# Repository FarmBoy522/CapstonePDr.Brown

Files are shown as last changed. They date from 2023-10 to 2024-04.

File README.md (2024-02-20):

# CapstonePDr.Brown
Option 8 - Capstone Project - CS490 ERAU
			      EE421/CS491

Vision Statement

Produce a handheld ultrasound inspection device for inspecting a bridge/structural component for faults in the field. This handheld unit gathers and stores test data collected over time for 48 to 72 hours.

Product Backlog
(current status shown in the issues tab)

Hardware:
	•	Design an outer casing to contain the electronics and test equipment.
	•	Requirements: the case must be able to withstand a fall from 3 ft and protect the contents of the case, the case must be water resistant and be able to protect the contents from water penetration from rain, 				      the case must have a handle and or strap for operator use, the case shall have all required penetrations for equipment to run wires and status lights (if applicable). The case shall be resistant/ 			      shielded from outside radio interference.
	•	Design an electrical system to support the unit’s operation.
	•	Requirements: The power supply shall support equipment normal operating use for greater than or equal to 48 hours (Ideally 72hrs), the electrical system shall be reusable, the electrical system shall have wires 			      secured to the casing or sheathed to prevent damage, the electrical system shall alert the user when power is low. Some portions of the system will operate at 500v and require verification that 			      wire insulation is sufficient for safe operation. 
	•	(TX) Design a smaller equivalent to the signal generator for the transistors operating frequencies.
	•	Requirements: able to produce required frequency for transducer 500kHz, able to produce required frequency for transducer 50kHz, able to switch between the two frequencies, Able to adjust the amplitude of 			              the signal (if required) Transmitter output: pulse 500V, 2microseconds. (Similar system) or Excitation: HV 1000v at 5us, LV 600v at 5us (data sheet)
	•	(RX) Design a smaller equivalent to the oscilloscope for the transistors operating frequencies.
	•	Requirements: able to receive required frequency for transducer 500kHz, able to receive required frequency for transducer 50kHz, able to switch between the two frequencies, Amplifier to boost amplitude of signal. 			      (If required)
	•	Produce attachable extensions to the test equipment leads to extend the test length or assist in accessibility for operator (if required) (not to exceed 20 ft)
	•	Design the memory storage and access hardware
	•	Requirements: minimum storage of “The current data files contain 40000 double-precision numbers and are approx. 1.6 MB” sampling at 10 min interval over 72-hour period, must be computer accessible. 					      (Estimated 691.2MB)
	•	Design an alarm/status system.
	•	Requirement: low battery/power light or alarm, self-check light or alarm, operating/on light or alarm, transmitting/testing light or alarm, memory full light or alarm, high temperature alarm light or alarm.
	•	Design a cooling system for the unit in the case of an overtemperature event. (If applicable)
	•	Requirement: temperature sensor inside the unit (RTD and fan recommended)

Software:
	•	Design/ program/find compatible software to process recorded signal. (MATLAB used previously)
	•	Requirements: must display the captured signal, alert the user if a fault is detected and where (if applicable)
	•	Develop software to monitor battery life and project remaining life 
	•	Develop software to monitor remaining memory space and project how much longer the device can record (use minutes and seconds remaining for recording)
	•	Develop software to pull data overtime from a signal to be used in other programs.
	•	Design software to perform a self-check of the system and determine if the unit has a fault.
	•	Design software to monitor temperature and activate the cooling system. Or shut down if the temperature exceeds 150 F (arbitrary value that may be changed)
	•	Design a GUI (graphical user interface) to quickly check calculated values and for maintenance purposes to display system data.
	
Other:
	•	The unit altogether shall not exceed 25 pounds 
	•	The unit shall be usable by a single operatior in the field.
	•	The unit should be corrosion resistant
	•	The unit should have safety features to shut down the unit if a fault in the system is detected
	•	The unit budget shall not exceed 2000$

Client request:
	•	The unit shall store data to be processed using a computer at a later time.
	•	Recording triggered/start when transmission starts

 2024 update for Backlog

To Do
Develop system to prevent frequent OS errors to allow program to run continuously #55
Design program to monitor charge voltage #54
Create system trigger to shutdown and light "overtemp protection" LED in case of uncontrolled temp overrun #53
Create system trigger to run "charging" fans if temps exceed operational max for parts #52
Wire "charging" fans to main circuit #51
Determine fan mounting positions #50
Install cooling fans #49
Apply sealant to the exterior casing #48
Purchase waterproof sealant #47
Label exterior LED's, switches, and components #46
Create cover plates (if applicable) #45
Create an operators manual (if time available) #44
Purchase 12 to 19.5 v power converter #43
Mount and Install RTD #42
Purchase RTD (resistance temperature detector) #41
Connect capacitor electrically HVS #40
Mount and install relay HVS #39
Purchase Relay for HVS #38
Test fan controllers via Arduino [Sprint 1 2024] #23
Design software to perform a self-check of the system and determine if the unit has a fault. #14
Develop software to store oscilloscope data on computer #13
Develop software to monitor remaining memory space and project how much longer the device can record (use minutes and seconds remaining for recording) #12
Develop software to monitor battery life and project remaining life #11
Test new data recording system with old Matlab program #10
Design the memory storage and access hardware #7

In Progress
Produce drip cover for exterior casing #56
Install electrical system HVS part 8 (resistors) #37
Install electrical system HVS part 7 (coaxial connection port) #36
Install electrical system LVS part 6 (battery) #35
Install electrical system HVS part 6 (12v to 500v power converter) #34
Install electrical system HVS part 5 (Fuses) #33
Install electrical system HVS part 4 (exterior operated switches) #32
Install electrical system HVS part 3 (Capacitor) #31
Install electrical system HVS part 2 (wiring) #30
Install electrical system HVS part 1 (circuit boards) #29
Install electrical system LVS part 5 (Fuses) #28
Install electrical system LVS part 4 (exterior operated switches) #27
Install electrical system LVS part 3 (LED) #26
Install electrical system LVS part 2 (wiring) #25
Install electrical system LVS part 1 (circuit boards) #24
Test electrical systems #21
code for led indicating lights/alarms #18
verify design criteria met #17

Finished
Program LUT for fan controllers [Sprint 1 2024] #22
Verify components electrically #20
connect/solder electrical system components #19
Design a GUI (graphical user interface) to quickly check calculated values and for maintenance purposes to display system data. #16
Design software to monitor temperature and activate the cooling system. Or shut down if the temperature exceeds 150 F (arbitrary value that may be changed) #15
Design a cooling system for the unit in the case of an overtemperature event. (If applicable) #9
Design an alarm/status system. #8
Produce attachable extensions to the test equipment leads to extend the test length or assist in accessibility for operator (if required) #6
(RX) Design a smaller equivalent to the oscilloscope for the transistors operating frequencies. #5
(TX) Design a smaller equivalent to the signal generator for the transistors operating frequencies. #4
Perform research to determine if the equipment can be miniaturized from the lab environment. #3
Design an electrical system to support the unit’s operation. #2
Design an outer casing to contain the electronics and test equipment. #1

	•	50 pulses sent each transmission (100 µsec interval in example)
	•	The revived 50 pulses are averaged together and displayed.
	•	The unit battery shall last for 48-72 hours or greater with samples being taken every 10 min.
	•	Budget less than or equal to 2000$
	•	MATLAB used to process data into usable form and graphed for analysis.

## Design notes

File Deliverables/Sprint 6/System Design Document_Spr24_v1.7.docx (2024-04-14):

System Design Document

Dr. Brown Capstone Project Spring ‘24:

Portable Ultrasound Device for Coda-Wave Interferometry

Team members:

Michael Kisellus, Matthew Baker, Layton Foxworthy, Kyle Fox, and Christopher Coppedge

Version | Author | Change | Date
v1.0 | Michael Kisellus, Matthew Baker, Layton Foxworthy, Kyle Fox, and Christopher Coppedge | Initial draft | 1/23/2024
v1.1 | Michael Kisellus | Times new roman text, figure 6,7 update, print format to make more readable, update references, update table of context, table 2 update | 4Feb2024
V1.2 | Kyle Fox | Updated readability | 5Feb2024
V1.3 | Michael Kisellus | Corrections from SDD feedback | 15,20Feb2024
V1.4 | Michael Kisellus | Same as above | 29Feb2024
V1.5 | Kyle Fox | Update Software architecture sections | 01Mar2024
V1.6 | Matthew Baker | Update cooling system detailed design, corrections from feedback on External Interfaces | 21Mar2024
V1.7 | Matthew Baker | Corrections from TA feedback: eliminating stray highlighting, proofreading | 11Apr2024

# TABLE OF CONTENT

1 INTRODUCTION 4

1.1 Purpose and Scope 4

1.2 Project Executive Summary 4

1.2.1 System Overview 4

1.2.2 Design Constraints 6

1.2.3 Future Contingencies 6

1.3 Document Organization 7

1.4 Project References 8

1.5 Glossary 8

2 SYSTEM ARCHITECTURE 9

2.1 System Hardware Architecture 10

2.1.1 Cooling System 10

2.1.2 Electrical System 11

2.2 System Software Architecture 12

2.3 Internal Communications Architecture 12

3 HUMAN-MACHINE INTERFACE 13

3.1 Inputs 13

3.2 Outputs 14

4 DETAILED DESIGN 15

4.1 Hardware Detailed Design 15

4.1.1 Environment Control and Cooling System 15

4.1.2 Electrical and Power System 16

4.1.3 Microcontroller and Control 17

4.1.4 Output Signal 17

4.1.5 Input Signal 17

4.2 Software Detailed Design 17

4.3 Internal Communications Detailed Design 18

5 EXTERNAL INTERFACES 19

5.1 Interface Architecture 19

5.2 Interface Detailed Design 20

6 SYSTEM INTEGRITY CONTROLS 20

7 References 23

SYSTEM DESIGN DOCUMENT

Overview

The System Design Document describes the system requirements, operating environment, system and subsystem architecture, files and database design, input formats, output layouts, human-machine interfaces, detailed design, processing logic, and external interfaces.

# 1 INTRODUCTION

Bridges are vital transportation infrastructure that are used daily by millions of people. Like any constructed work, the material used has a finite lifespan and will degrade as both the effects of nature and its designed purpose act on the bridge. Being able to determine locations of failure points, subsurface cracks, and voids in building materials such as concrete can greatly increase the ability for an engineering team to predict future issues and plan remedial work for a bridge. To assist those engineers, the Portable Ultrasound Device (PUD) was designed. This device can be used in conjunction with ultrasonic transducers to detect anomalies within concrete. The data collected can be used to make future engineering decisions.

## 1.1 Purpose and Scope

The PUD is a handheld ultrasound inspection device for inspecting bridges and structural components for faults in the field. This handheld unit will have an independent power supply and will collect and store test data. The PUD is fully capable of its precise data collection duties while still being durable enough to withstand difficult environmental conditions such as shock from a fall, rain, and other environments a field tool will be exposed to.

## 1.2 Project Executive Summary

This PUD unit consists of commercial off-the-shelf (COTS) components engineered into a cohesive system that matches the requirements. The production management for the PUD project is Agile Scrum. Dividing the PUD project into 3 sprints over the course of an 11-week timeline.

### 1.2.1 System Overview

The PUD system will output a pulse signal to the transducer as shown in figure 2 point 1. The transducer then uses the piezoelectric effect to produce a 54kHz test signal, this signal propagates into the connected concrete sample being tested. The signal then propagates to a second transducer placed on the opposing side of the concrete sample. Through the piezoelectric effect the second transducer converts the 54kHz signal into a low-level voltage which is returned to the PUD to be processed.

Note: The 54 kHz is due to the manufacturer of the transducer NDT James Instruments. It is designed to produce this frequency

The use case diagram shown in figure 1 describes the options an operator can use to operate the PUD system. The operator may charge the battery or remove the storage device (SD) card when the power is off to the main system. The main functionality is accessible when the operator turns the unit's power on. Allowing the operator to enter the test duration by repeatedly pressing the test duration button to cycle through the options. The test duration selected is displayed on the face plate LEDs 6,7,8,9, and 10 shown in figure 6. The operator may press the start button to initiate the test. The operator may also stop the test before the test duration ends and save the resulting data to an SD card.

Figure 1: Use Case Diagram

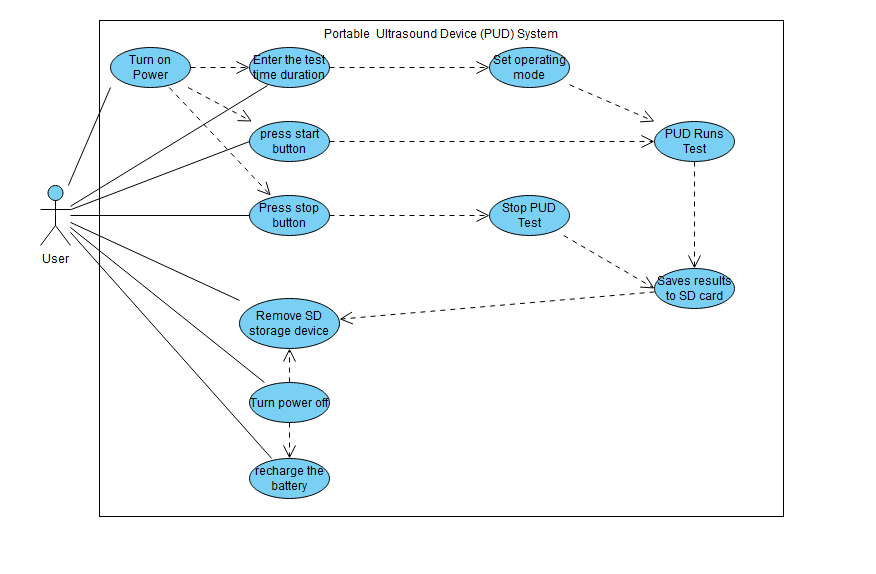
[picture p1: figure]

Figure 2: overall system diagram

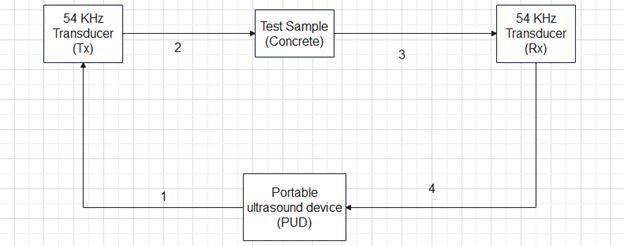
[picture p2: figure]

### 1.2.2 Design Constraints

The design of the system will balance system weight vs battery life, battery consumption vs cooling, and accuracy vs component price. One of the requirements of the system is that it must remain portable and as such we will be keeping the unit as light as possible. This comes in direct competition with battery life, which also has its own requirement. Battery consumption and cooling are also going to have to be balanced to ensure the hardware, specifically the battery, stays within operating temperature. This would lead us to running the fans more but that increases battery consumption and decreases how long the system can be used in the field. Lastly, more accurate signal processing hardware costs more than its less accurate counterpart so our design uses components that are within the project’s budget of $2000 and are also accurate enough for our application.

### 1.2.3 Future Contingencies

The exact requirements of the system are dependent on the civil engineering laboratory (Lab run by Professor Brown), which serves as the primary stakeholder for the system. They will be the primary user of the PUD once it is operational so the requirements must match their expectations. Any changes to the system will depend on their wants and needs. The civil engineering lab already has some components of the final system, these are not going to change and are proven to operate correctly from previous testing.

Operating with 500V requires specialized components and rated insulative material to protect the system from inadvertent grounds or component failure. If components fail during testing a higher voltage rated component may be purchased to replace insufficient performing parts.

The Metal oxide semiconductor field effect transistor (MOSFET) component used must switch on and off quickly to fulfill its purpose. If the component is unable to meet specifications during testing a better/ more expensive component may need to be purchased to replace this component.

The oscilloscope used to sample the return signal needs to be sampled extremely quickly to capture the return signal in detail. This component may need to be replaced if testing reveals the sample rate to be insufficient.

## 1.3 Document Organization

The document adheres to the organizational structure and formatting prescribed by the course. Every section, heading, and subheading has been aligned with the template guidelines to maintain a consistent and professional appearance. By following the provided instructions and formatting guidelines, we aimed not only to meet the basic requirements but also to contribute to the overall uniformity of documentation between the multiple teams. This approach ensures that the professors and TAs can easily navigate the document.

Part 1 contains the INTRODUCTION which has 8 subsections: Purpose and Scope, Project Executive Summary, System Overview, Design Constraints, Future Contingencies, Document Organization, Project References, and the Glossary. Overall, this section describes the system, constraints, contingencies and the documentation associated with the system.

Part 2 contains the SYSTEM ARCHITECTURE which has 3 subsections: System Hardware Architecture, System Software Architecture, Internal Communications Architecture. Overall, this section describes the system hardware and software architecture for the PUD system. The hardware section is subdivided by systems.

Part 3 contains the HUMAN-MACHINE INTERFACE which has 2 subsections: Inputs and Outputs. Overall, this section describes the inputs a user can make and the outputs the PUD system will produce.

Part 4 contains the DETAILED DESIGN which has 3 subsections: Hardware Detailed Design, Software Detailed Design, Internal Communications Detailed Design. Overall, this section provides an in-depth explanation of the systems used to construct the PUD system.

Part 5 contains the EXTERNAL INTERFACES which has 2 subsections: Interface Architecture and Interface Detailed Design. Overall, this section describes other systems the PUD system must interface with to operate. This section is small because the system is self-contained and does not communicate to exterior systems during operation.

Part 6 contains the SYSTEM INTEGRITY CONTROLS. Overall, this system has to do with data security and software protection. This section is small due to the unit not requiring data protection as the PUD does not contain sensitive information.

## 1.4 Project References

This section provides a bibliography of key project references and deliverables that have been produced before this point.

International Electrotechnical Commission (2013). Degrees of protection provided by enclosures (IP Code) (IEC 60529). Retrieved from https://website.iec.ch/publication/2452

Parts references are placed at the end of the document in table 3.

## 1.5 Glossary

Supply a glossary of all terms and abbreviations used in this document. If the glossary is several pages in length, it may be included as an appendix. Shown in table 1.

Table 1: glossary

IP Rating [IPAB]

Ingress Protection rating as codified under the IEC 60529 standard, where A is the device’s resistance to solid particle such as dust from zero (no protection) to 6 (most protection) and B is the device’s resistance to liquids from zero (no protection) to 9K (most protection). (International Electrotechnical Commission [IEC], 2013)

An IP55 rating means:

5-Ingress of dust is not entirely prevented, but it must not enter in sufficient quantity to interfere with the satisfactory operation of the equipment.

5-Water projected by a nozzle (6.3 mm) against enclosure from any direction shall have no harmful effects.
PUD | Portable ultrasound device
LED | Light emitting diode
piezoelectric effect | Applying mechanical stress to a crystal produces an electrical charge and vice versa.
MOSFET | Metal oxide semiconductor field effect transistor
UART | Universal asynchronous receiver transmitter
HMI | Human machine interface
PC | Personal computer
Tx | Transmitter
Rx | Reciever
SD | Storage device
FRD | Functional requirement document
RTM | Requirement traceability matrix

# 2 SYSTEM ARCHITECTURE

This section outlines the overall system architecture, including both software and hardware architecture for the PUD system and subsystems.

Figure 3 shows the PUD physical components and their interactions. Point 1 shows that the cooling fan receives power to operate from the battery. Point 2 shows that the analog to digital converter delivers its data to the central control chip. Point 3 shows that the pulse generator is controlled by the central control chip. Point 4 shows that the pulse generator controls the MOSFET gating on or off. Point 5 shows that The MOSFET outputs to the Transducer. Point 6 shows that the central control chip transfers data to the SD card. Point 7 shows that the central control chip monitors the battery voltage. Point 8 shows that the cooling fan is controlled by the central control chip. Point 9 shows that the status LEDs are controlled by the central control chip. Point 10 shows that the central control chip receives power from the battery. Point 11 shows that the status LEDs are powered by the battery. Point 12 shows that the transducer transmits a signal to the analog to digital converter. Point 13 shows that the MOSFET input is provided by the DC-to-DC converter. Point 14 shows that the DC-to-DC converter is powered by the battery.

Figure 3: Portable ultrasound device (PUD) internal components block diagram

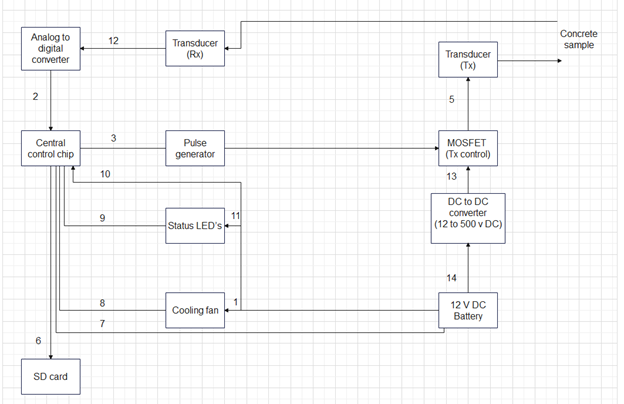
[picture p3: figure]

## 2.1 System Hardware Architecture

This section, describes the overall system hardware and organization. The system hardware is broken into 2 subsystems: Cooling System, Electrical System.

### 2.1.1 Cooling System

The cooling system consists of multiple 80mm fans each connected to an integrated fan controller and temperature sensor to operate independently from one another to ensure that if one fan goes down the other(s) can still operate as well as making sure each area within the case gets the airflow that it requires. The fans will be placed on either end of an inner metal frame to drive the airflow over the components in the most efficient manner possible. The fan’s RPM rate will be tied to the internal temperature of local components (detected via the controller) via the following curve shown in figure 4. This curve is designed by the manufacturer of the fan components.

Figure 4: Cooling fan behavior chart

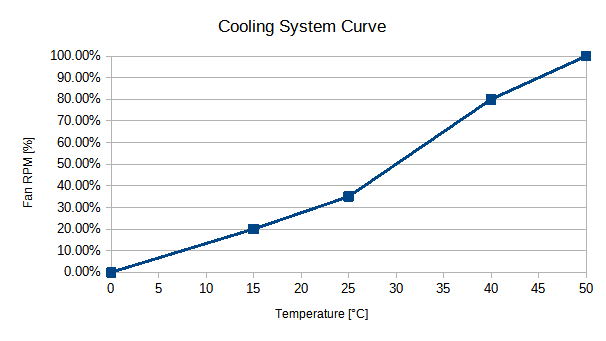
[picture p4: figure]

While the system’s design considers the possibility for the fans to run at maximum for the entire operating time, this thermal curve is in keeping with industry standards for keeping a computer system cooled while preventing too much current and power use from the internal power supply and thus preventing premature power drain.

Parts List:

- Twin NMB 08025SE-12Q-FT-DW Fan, 12VDC, 3.12 Watts at 0.26 Amps for variable cooling
- EMC2101 integrated fan controller and thermocouple, 3/5V DC connected to central board.

### 2.1.2 Electrical System

The PUD electrical system consists of a 12v battery bank which is used to power various loads. Such as LED’s and cooling fans. There is a subsystem for charging the battery which is disconnected through an externally operable switch. The high voltage section consists of a 12v DC to 500v DC converter and a capacitor bank to maintain voltage. Electrical schematic shown in figure 3 below.

Parts list for electrical systems are shown in table 2 but parts may be replaced with equivalent parts.

Figure 5: PUD Electrical system

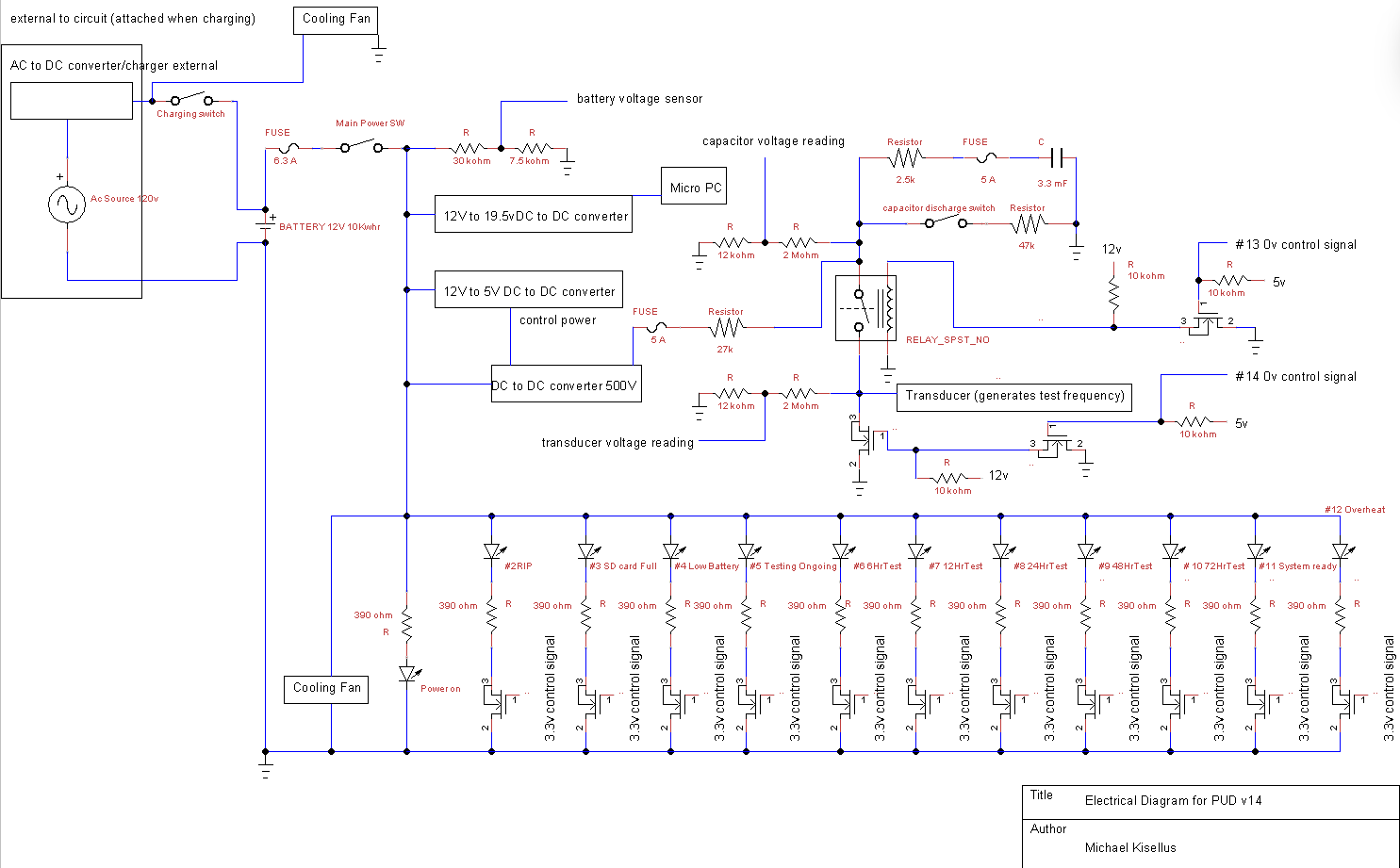
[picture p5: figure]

## 2.2 System Software Architecture

The software system is made up of two parts, the Raspberry Pi Pico, and the minicomputer. Both parts work independently to control the system and record data.

The Raspberry Pi Pico (RP Pico) handles system control through a state machine with three separate states. Each state controls a different part of the hardware system. The first state allows for button interrupts to control movement to the next state. The second state allows for pulse control and overall system timing. The third state changes the total test time of the system.

The microcomputer will run a Python-C wrapper to program the oscilloscope to do automated data collections. This collection will be done without human intervention and store the data on an SD card within the computer for later retrieval.

## 2.3 Internal Communications Architecture

The internal communications will consist of USB, Digital IO, and UART. The Universal asynchronous receiver transmitter (UART) will allow us to program the microcontroller. USB will be used to control and program the Oscilloscope as well as preform data collection/storage. The microcontroller will use the digital IO pins to control the Human machine interface (HMI) and pulse control. Shown in figure 8.

There will be no communication between the microcontroller and the minicomputer as the buttons will control microcontroller function and the oscilloscope will have automatic data collection. The microcontroller will however send a pulse to the oscilloscope at the same time as the control pulse is sent to the transducer.

Figure 8: Internal Communications Architecture diagram

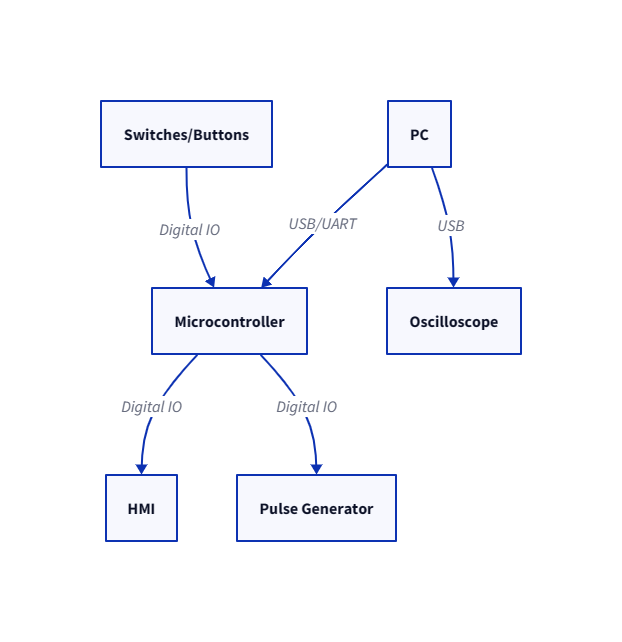
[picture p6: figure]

# 3 HUMAN-MACHINE INTERFACE

The PUD system will have input from the user to start the system and to determine how long the system should operate. This will be performed through physical buttons. As for outputs the PUD will have LED indicators to display the system’s status to the operator. Additionally, a removable SD card will be able to be extracted from the system after it has gathered the desired data.

## 3.1 Inputs

The PUD system inputs will be physical buttons that send a voltage signal to the microcontroller. Because it is a simple 2-state button the PUD will have the input to the microcontroller be a simple binary input. The buttons will correspond to modes that set the time the system will be in operation. This simplicity will make I/O controls simple and reliable.

The front panel physical button I/O options will be “Test System”, “6 Hour”, “12 Hour”, “24 Hour”, “48 Hour”, “72 Hour”, “Start Test” “Select Test Duration” and “Stop Test”. As shown in figure 6.

Figure 6: Input panel for PUD

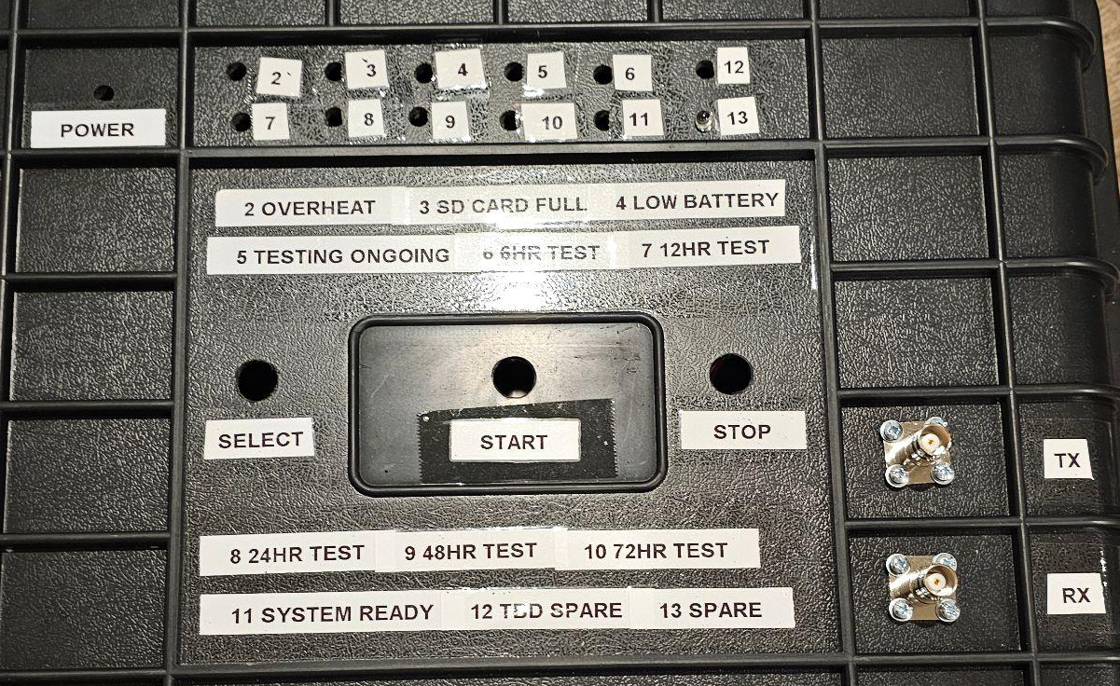
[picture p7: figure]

## 3.2 Outputs

The outputs from the system come in two different forms. The data from the operation of the system, and the indicators that tell the operator the status of the system. The operator indicators will be presented on LEDs and the system’s output data from the concrete measurement will be stored on an SD card.

The operator’s indicators will be the representation of binary values in our microcontroller. The implementation of this will depend on the voltage the microcontroller is able to output so if it is not able to power the LED we may need a relay to switch the LED on. The indicators will include “Power Available”, “Low Battery”, “High Temperature”, “SD Card Full”, “Unit Charging Capacitor” and more if needed.

The data the system collects about the concrete will need to be converted to a digital signal and stored through the oscilloscope. This will then be written to an SD card in the minicomputer for the operator to retrieve when the system is done with its operation. The retrieval will require the case to be opened. This helps protect the SD card against the weather. The output file on the SD card will be set within the minicomputer program as a “.mat” file.

Note: Expanding on the source of the data the system collects: After the system transmits a 500 v pulse to the Transmitting (Tx) transducer. The transducer vibrates and those vibrations travel through the concrete/sample. The vibrations then reach the receiving (Rx) transducer and the vibrations are converted to a electrical voltage. This voltage is read by the connected oscilloscope and processed into a graph of the resulting voltages over time. This graph is then saved for review by human operators on a removable SD card or other storage device.

Figure 7: Output panel for PUD

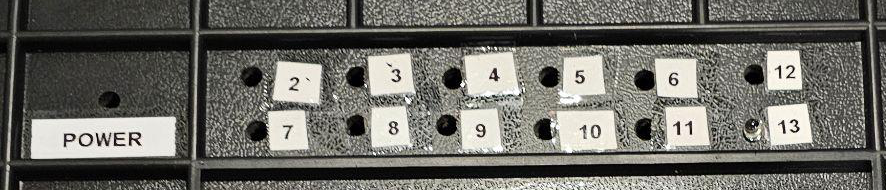
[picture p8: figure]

# 4 DETAILED DESIGN

This section provides the information needed for a system development team to build and integrate the hardware components, code, and integrate the software modules, and interconnect the hardware and software segments into a functional product. Additionally, this section addresses the detailed procedures for combining separate COTS packages into a single system. Every detailed requirement should map back to the Functional requirement document

(FRD), and the mapping should be presented in an update to the Requirement traceability matrix (RTM) and include the RTM as an appendix to this design document.

## 4.1 Hardware Detailed Design

The low-level hardware design is split into 5 distinct parts. The microcontroller and control system, the output signal, the input signal, the environment control, and the power system.

### 4.1.1 Environment Control and Cooling System

The cooling system consists of two 80mm 12VDC fans each connected to a EMC2101 fan controller which circulates air via a pull-push arrangement with one fan acting as intake and the other acting as exhaust. The fans are placed on opposing sides of the case and staggered with one at the rear-right and the other at the front-left side to properly vent air around the battery and capacitor. The fan controllers are integrated circuit boards that contain a programmable ROM that contains a look-up table which instructs the fan on the proper RPM to spin at via pulse-width modulation which is dependent on the temperature inside the case. The external cutouts for the fans have fan covers that consist of an external vent to protect from rainfall; filter media to prevent the ingress of dust, insects, and other solid matter; and a plastic grate to act as a finger guard in the event that the external cover is dislodged. Internally the fans are protected via plastic mesh held to prevent damage to the internal wiring. Each fan as an IP55 rating to aid in the overall elemental resistance of the unit. The fan cover baseplates are attached via long screws and waterproof sealant. Each fan draws 3.12 watts and 0.26 amps and each controller board requires 5VDC supply voltage provided by available power within the electrical system. The fan controller boards also provide the temperature readings to the Pico at the heart of the system so that, in case of temperature overrun, the system can be shut down to prevent damage to the components.

### 4.1.2 Electrical and Power System

The electrical system consists of 2 main buses. Note: electrical bus bars are used to distribute power. A 12 V DC bus and a 500 V DC bus are used.

The 12 V DC bus consists of 2 loops. The first loop is used to recharge the LiFePO4 12V 50Ah Lithium Iron Phosphate Battery. The battery is connected using 6 AWG (16mm²) 13 Inch Battery Interconnect Cable to the exterior of the casing and is accessible without opening the case. A Battery Isolator Switch for Car Vehicle RV and Marine (On/Off) is used to isolate the battery charging loop when not in use. The battery charger used is a 5A & 10A 12V Smart Battery Charger with LCD Display for Lead Acid and Lithium (LiFePO4) Batteries. The second loop connects the battery to the 12 V DC load bus which powers the various loads of the system. The battery has a switch to open this loop and turn off the system. The battery connects to the 10 Position Wire to Board Terminal Block Horizontal with Board. This is used to connect the various 12 v loads. Including the LED indicating lights which require a 453 Ohms ±1% 0.25W, 1/4W Through Hole Resistor Axial Metal Film to reduce voltage and current to 3.3v and 20mA for the LED to operate. The LED uses a Transistor’s: Bipolar (BJT) Transistor NPN 36 V Through Hole TO-92-3 to receive signals from the controlling chip to turn on or off. The cooling fan receives power from this bus. The controlling chip receives its power from this bus. The DC 12v 24v to 5v Step Down Converter Regulator 5A 25W Power Adapter Reducer for Car Electronics Truck Vehicle Boat Solar System (Accept DC 8-40V Inputs) receives power from this bus and its output is used as control power on the Enclosed DC to DC Converter 1 Output 0 ~ 500V 20mA 13V Input. The 12V DC to 500V DC converter receives its main power from this bus and sends power to the 500V bus.

The 500V DC bus starts at the 12V DC to 500V DC converter and is used to charge a 3300 µF 500 V Aluminum Electrolytic Capacitor which acts as a voltage regulator for normal operation. Amcor Marine Grade Primary Wire and Battery Cable is used for the 500 v portions of the circuit to connect the circuit components. A 47 kOhms ±5% 50W Wire wound Chassis Mount Resistor is used in series with the capacitor to prevent current from exceeding the 20mA limit of the converter while charging the capacitor. Finally, a MOSFET N-Channel 500 V 14A (Tc) 30W (Tc) Through Hole TO-220FP is used to gate the 500 V DC source on for 2*10^-6 sec. This pulse then travels to the transducer and leaves the PUD system. Figure 3 above displays the electrical schematic.

### 4.1.3 Microcontroller and Control

This part of the PUD can be affectionately considered the brains of the PUD. The microcontroller and control system handles both user inputs, timing of data collection from the input signal, control of the output signal, and allows for user retrieval of data from the SD card.

This system uses the bus architecture described earlier to communicate with both the SD card and the ADC. This allows data to move through the microcontroller to the SD card with minimal latency for further data collection.

### 4.1.4 Output Signal

This is the 500V DC signal that pings the transducer. The system uses a DC-DC converter to charge 500V and release a 2-microsecond pulse to the transducer allowing the semiconductive nature of the crystal to ring. This is activated by the microcontroller and is timed to allow the input signal to be unaffected by the “strike” of the output transducer.

### 4.1.5 Input Signal

The input signal is a 1V peak signal that is fed into a high-speed high bandwidth ADC. This ADC converts the analog signal into a digital stream that is fed into the microcontroller. This signal is the representation of the concrete health, this signal must be captured in its entirety and for its whole duration. This is done by using the ADC filtering functions to remove noise and capture the whole waveform for data processing. Once the ADC has captured a portion of the signal, the microcontroller moves the data over SPI to the SD card for processing by the data analysis program, which is off system.

## 4.2 Software Detailed Design

Software design of the microcontroller consists of a state machine of 3 states. This is done to reduce the chance of functions or control running in error. This design also allows for a major simplification of the overall system by allowing for the minicomputer to not communicate directly with the microcontroller.

This simplification of design parameters allows for each state to control the program with a minor number of function calls that operate linearly. The first state allows for input from buttons to step into the next state. This “waiting” state allows for the user to press the start button to go to state 2 and begin the test, stop button to do nothing, and select button to go to state 3 and change the total test time. The second “running” state will control the pulse control, system timing, and overall control. The third “select” state changes the current total test time value.

## 4.3 Internal Communications Detailed Design

USB Communication will be the method in which the PC will communicate with the oscilloscope. The oscilloscope will be preprogrammed with a function that will allow for automated data collection. This software is sourced from the manufacturer. This automated data collection will allow for the program to store data on the computer without human intervention.

Shown in figure 9.

Figure 9: Rx system

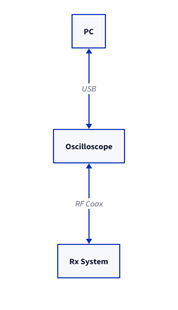
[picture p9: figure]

The microcontroller will use its Digital IO pins to turn LEDs on and off, for digital interrupts from the HMI, and send a pulse to the TX and oscilloscope portion of the system. The LEDs will be controlled by the outputs of the microcontroller. The pulse will be timed to be as short as possible, however to ensure accuracy that will feed into a timer circuit to keep the time consistent. Shown in figure 10.

Figure 10: Button interface to system

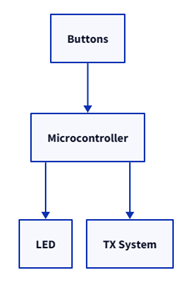
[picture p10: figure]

# 5 EXTERNAL INTERFACES

With the system being self-contained there are no external interfaces under the scope of this PUD project, the only exception being the SD card containing the testing data. However, as this card is extracted from the PUD system manually by the operator this would only fit the definition of an external interface via the broadest possible interpretation of the term.

# 6 SYSTEM INTEGRITY CONTROLS

The data collected by the PUD system is not inherently sensitive or private so security is not the highest priority. There will be a physical lock on the PUD outer casing for safety purposes but this will also protect the data the system collects. Physical protection of the device is the responsibility of the user of the system. Verification of the data will come from the lab that analyzes the data so this is not within the scope of the PUD project.

Table 2: electrical components parts list

part number | Part specification and description
1 | 3300 µF 500 V Aluminum Electrolytic Capacitors Radial, Can - Screw Terminals 54mOhm @ 100Hz 20000 Hrs @ 85°C
2 | Enclosed DC DC Converter 1 Output 0 ~ 500V 20mA 13V Input 3838-HighVoltagePowerSupplyAHV12V500V20MAWTB-ND - Tape & Box (TB)
3 | DC 12v 24v to 5v Step Down Converter Regulator 5A 25W Power Adapter Reducer for Car Electronics Truck Vehicle Boat Solar System (Accept DC 8-40V Inputs)
4 | White, Cool 9000K LED Indication - Discrete 3.2V Radial
5 | 5A & 10A 12V Smart Battery Charger with LCD Display for Lead Acid and Lithium (LiFePO4) Batteries
6 | 6AWG (16mm²) 13 Inch Battery Interconnect Cable
7 | LiFePO4 12V 50Ah Lithium Iron Phosphate Battery
8 | Battery Isolator Switch for Car Vehicle RV and Marine (On/Off)
9 | Ancor Marine Grade Primary Wire and Battery Cable
10 | N-Channel 500 V 14A (Tc) 30W (Tc) Through Hole TO-220FP
11 | Starelo 5pcs 19mm Momentary Push Button Switch Black Shell, IP65 Waterproof Push Button Switch,Stainless Steel 1 Normally Open Without LED.
12 | 47 kOhms ±5% 50W Wirewound Chassis Mount Resistor
13 | N-Channel 20 V 6.8A (Ta) 510mW (Ta), 6.94W (Tc) Surface Mount TO-236AB
14 | 390 Ohms ±5% 0.5W, 1/2W Through Hole Resistor Axial Flame Retardant Coating, Safety Carbon Film
15 | 21 Circuit 0.374" (9.50mm) Barrier Block Connector Screws
16 | 5 A 600 V AC 500 V DC Fuse Cartridge, Ceramic Requires Holder 5mm x 20mm
17 | Fuse Block 10 A 600V 1 Circuit Cartridge Chassis Mount
18 | 6.3 A 250 V AC DC Fuse Cartridge, Glass Requires Holder 5mm x 20mm
19 | ANSI Z535 Safety Labels - Hazardous Voltage Inside Hazard labels with strong adhesive backing ideal for rugged use
20 | 50ft - 1/4 inch & 1/2 inch PET Expandable Braided Sleeving – Black – Alex Tech Braided Cable Sleeve
21 | XHF 3/4" Strong Back-Glue Self Adhesive Black Cable Zip Tie Mounts 100pcs with 8" Zip Ties, Screws, UV Protection Outdoor Sticky Wire Fasteners Cable Clips Management Anchors Organizer Holders Squares
22 | Miuzei PCB Board Prototype Kit for Electronic Projects, Circuit Solder Double-Side Board with 40 Pin 2.54 mm Male to Female Headers Connector, 2P&3P Screw Terminal Block, Solder Flux, Solder Wire
23 | 330 Pcs M2 Male Female Brass Hex Spacer Standoffs Screws Nuts, Brass Spacer Hex Column Screw Nut Assortment Kit, Threaded Pillar Standoffs Screws for PCB Circuit Board Motherboard Standoffs Spacer
24 | Breadboard, Surface Mount Plated Surface Mount Pad (Square) 0.100" (2.54mm)
25 | 2.7 kOhms ±5% 120W Wirewound Chassis Mount Resistor
26 | Heat Sink TO-218, TO-220, TO-247 Aluminum 14.0W @ 70°C Board Level, Vertical or Heat Sink TO-220 Aluminum 2.5W @ 50°C Board Level
27 | Belker Universal Laptop Car Charger with USB C for HP Dell Asus Lenovo Samsung MacBook Pro Air Google Chromebook Ultrabook Notebook
28 | VELCRO Brand Extreme Outdoor Mounting Tape | 20Ft x 1 In, Holds 15 lbs | Strong Heavy Duty Stick on Adhesive | Mount on Brick, Concrete for Hanging, 30702
29 | Coolais 5 Pcs Momentary Push Button Switch Metal Waterproof Push Button Start 12mm 3A 250V AC PBSM-01 (Flat Head)
30 | 3M Marine Adhesive Sealant Fast Cure 5200 (05220) Permanent Bonding and Sealing for Boats and RVs Above and Below the Waterline Waterproof Repair, White, 3 fl oz Tube
31 | Temperature Sensor Analog, Local 5°C ~ 100°C 20mV/°C TO-92-3
32 | ASEV30 SERIES 30A DC CONTACTOR Search Alert TSA Approved Travel Combination Luggage Cable Locks for Suitcase, Gym Locker,Toolbox,Backpack 1,2,4,6 &10 pk
33 | E/FUSING 900 Moldable Silicone Putty - Black
34 | 2Pcs Electronic Thermostat Controller W1209 DC 12V Digital Thermostat Waterproof Sensor Temperature Control Switch -50~110°C
35 | TBD

# 7 References

“021706.3TXP Littelfuse Inc. | Circuit Protection | DigiKey.” DigiKey, www.digikey.com/en/products/detail/littelfuse-inc/021706-3TXP/3425317. Accessed 21 Oct. 2023.

“05200005ZXGY Littelfuse Inc. | Circuit Protection | DigiKey.” DigiKey, www.digikey.com/en/products/detail/littelfuse-inc/05200005ZXGY/554334. Accessed 21 Oct. 2023.

“0ADKC5000-Be Bel Fuse Inc. | Circuit Protection | Digikey.” DigiKey, www.digikey.com/en/products/detail/bel-fuse-inc/0ADKC5000-BE/7404459. Accessed 21 Oct. 2023.

“100ft - 1/2 Inch Pet Expandable Braided Sleeving - Amazon.Com.” Amazon, www.amazon.com/100ft-Expandable-Braided-Sleeving-braided/dp/B074GMNW7T. Accessed 21 Oct. 2023.

“12-48V Battery Isolator Switch for Car Vehicle RV and Marine (on/off): Eco-Worthy.” ECO, www.eco-worthy.com/products/12-48v-battery-isolator-switch-for-car-vehicle-rv-and-marine-on-off?variant=40589578567868. Accessed 21 Oct. 2023.

“2-1546306-1 TE Connectivity AMP Connectors - DigiKey Electronics.” DigiKey, www.digikey.com/en/products/detail/te-connectivity-amp-connectors/2-1546306-1/1136667. Accessed 21 Oct. 2023.

“330 PCS M2 Male Female Brass Hex Spacer Standoffs Screws ... - Amazon.Com.” Amazon, www.amazon.com/Standoffs-Assortment-Threaded-Circuit-Motherboard/dp/B0BZYTC581. Accessed 21 Oct. 2023.

“577002B00000G Aavid, Thermal Division of Boyd Corporation - Digikey.” DigiKey, www.digikey.com/en/products/detail/aavid-thermal-division-of-boyd-corporation/577002B00000G/102507. Accessed 21 Oct. 2023.

“5A 12V Automatic Smart Battery Charger and Maintainer with LCD Display for Lead Acid and Lithium (LiFePO4) Batteries: Eco-Worthy.” ECO, www.eco-worthy.com/products/5a-12v-automatic-smart-battery-charger-and-maintainer-with-lcd-display-for-lead-acid-and-lithium-lifepo4-batteries?variant=42350017052921. Accessed 21 Oct. 2023.

“6AWG (16mm2) 13 Inch Battery Interconnect Cable: Eco-Worthy.” ECO, www.eco-worthy.com/products/6awg-16mm-13-inch-battery-interconnect-cable?variant=34593133625509. Accessed 21 Oct. 2023.

“Als30a332np500 Kemet | Capacitors | Digikey - Digi-Key Electronics.” Digikey, www.digikey.com/en/products/detail/kemet/ALS30A332NP500/3462159. Accessed 21 Oct. 2023.

“Amazon.Com: 2Pcs Electronic Thermostat Controller W1209 DC 12V Digital ...” Amazon, www.amazon.com/Electronic-Thermostat-Controller-Waterproof-Temperature/dp/B08Y6L34PX. Accessed 4 Feb. 2024.

“Amazon.Com: Tsa Approved Luggage Locks, Travel Locks Which Also Work ...” Amazon, www.amazon.com/Approved-Luggage-Travel-Toolbox-Backpack/dp/B07MVJZ6C2. Accessed 4 Feb. 2024.

“Amazon.Com: XHF 3/4" Strong Back-Glue Self Adhesive Black Cable Zip Tie ...” Amazon, www.amazon.com/XHF-Back-Glue-Protection-Fasteners-Management/dp/B08F77YVYB. Accessed 21 Oct. 2023.

“ANCOR Marine Grade Primary Wire and Battery Cable - Amazon.Com.” Amazon, www.amazon.com/Ancor-Marine-Grade-Primary-Battery/dp/B07ZSDK651. Accessed 21 Oct. 2023.

“ANSI Z535 Safety Labels - Hazardous Voltage Inside.” Seton, www.seton.com/ansi-z535-safety-labels-hazardous-voltage-inside-l5476.html?utm_campaign=%5BNB%5D_Labels_Catch%2BAll_PLA-S_High_All_PC-02_GGL_SUS&utm_source=google&utm_medium=cpc&utm_term=&matchtype=&device=c&adgroupid=&gclsrc=aw.ds&gclid=CjwKCAjwseSoBhBXEiwA9iZtxo15KyzhNfMKE5oyzbC-vorhbGmpge9ewSppeK7ReCrhPLgh6Yt0NRoCVhcQAvD_BwE. Accessed 21 Oct. 2023.

“ASEV30-B Altran Magnetics, LLC | Relays | Digikey.” DigiKey, www.digikey.com/en/products/detail/altran-magnetics-llc/ASEV30-B/14120027. Accessed 4 Feb. 2024.

“C503C-Wan-CCADB232 Creeled, Inc. | Optoelectronics | DigiKey.” DigiKey, www.digikey.com/en/products/detail/creeled-inc/C503C-WAN-CCADB232/2681196. Accessed 21 Oct. 2023.

“CF12JT390R Stackpole Electronics Inc | Resistors | Digikey.” DigiKey, www.digikey.com/en/products/detail/stackpole-electronics-inc/CF12JT390R/1741140. Accessed 21 Oct. 2023.

“DC 12V 24V to 5V Step down Converter Regulator 5A 25W Power Adapter ...” Amazon, www.amazon.com/Converter-Regulator-Adapter-Reducer-Electronics/dp/B07Q5W1BG3. Accessed 21 Oct. 2023.

“Dolby Vision + Dolby Atmos - Amazon.Com.” Amazon, www.amazon.com/Hisense-Premium-50U6G1-Quantum-Compatible/dp/B09TWYDMPY. Accessed 4 Feb. 2024.

“E/Fusing 900 Moldable Silicone Putty - Black - Amazon.Com.” Amazon, www.amazon.com/E-FUSING-900/dp/B0B6JWT295. Accessed 4 Feb. 2024.

“High Voltage Power Supply AHV12V500V20MAW Analog Technologies | Power ...” DigiKey, www.digikey.com/en/products/detail/analog-technologies/High-Voltage-Power-Supply-AHV12V500V20MAW/18621897. Accessed 21 Oct. 2023.

“HTTPS: //WWW. Amazon. COM/GP/Product/B00955337I/Ref=oh_aui_detailpage ...” Amazon, www.amazon.com/gp/customer-reviews/R2WSHBZW6W1Z0K/. Accessed 4 Feb. 2024.

“HTTPS: //WWW. Amazon. COM/GP/Product/B00955337I/Ref=oh_aui_detailpage ...” Amazon, www.amazon.com/gp/customer-reviews/R2WSHBZW6W1Z0K/. Accessed 4 Feb. 2024.

“LiFePO4 12V 50ah Lithium Iron Phosphate Battery: Eco-Worthy.” ECO, www.eco-worthy.com/products/lifepo4-12v-50ah-lithium-iron-phosphate-battery?currency=USD&variant=42491122712825&utm_medium=cpc&utm_source=google&utm_campaign=Google+Shopping&stkn=ac7b7d784bf0&gclid=CjwKCAjwgsqoBhBNEiwAwe5w02e_e41oUWis8aF0zZ64SqB2gfhDZQGvhFikRSAGGwQNgwVP8l8POBoCaacQAvD_BwE. Accessed 21 Oct. 2023.

“Miuzei PCB Board Prototype Kit for Electronic Projects, Circuit Solder ...” Amazon, www.amazon.com/Miuzei-Including-Prototype-Connector-Terminal/dp/B07PS4VCDD. Accessed 21 Oct. 2023.

“Ohmite Distributor | DigiKey Electronics.” DigiKey, www.digikey.com/en/supplier-centers/ohmite. Accessed 21 Oct. 2023.

“PMV16XNR Nexperia USA Inc. | Discrete Semiconductor Products | DigiKey.” DigiKey, www.digikey.com/en/products/detail/nexperia-usa-inc/PMV16XNR/5395791. Accessed 21 Oct. 2023.

“Ra-T2X-38E Ohmite | Fans, Thermal Management | DigiKey.” DigiKey, www.digikey.com/en/products/detail/ohmite/RA-T2X-38E/2416488. Accessed 21 Oct. 2023.

“SBBSM2106-1 Chip Quik Inc. | Prototyping, Fabrication Products | DigiKey.” DigiKey, www.digikey.com/en/products/detail/chip-quik-inc/SBBSM2106-1/5978238. Accessed 21 Oct. 2023.

“Starelo 5pcs 12mm Momentary Push Button Switch Black Shell with Pre ...” Amazon, www.amazon.com/Momentary-Push-Button-Switch-Without/dp/B09BKZ68HF. Accessed 21 Oct. 2023.

“STF19NM50N Stmicroelectronics | Discrete Semiconductor Products | DigiKey.” DigiKey, www.digikey.com/en/products/detail/stmicroelectronics/STF19NM50N/2346299. Accessed 21 Oct. 2023.

“TE120B2K7J Te Connectivity Passive Product | Resistors | DigiKey.” DigiKey, www.digikey.com/en/products/detail/te-connectivity-passive-product/TE120B2K7J/14308543. Accessed 21 Oct. 2023.

“TMP37FT9Z Analog Devices Inc. | Sensors, Transducers | DigiKey.” DigiKey, www.digikey.com/en/products/detail/analog-devices-inc/TMP37FT9Z/1217626. Accessed 4 Feb. 2024.

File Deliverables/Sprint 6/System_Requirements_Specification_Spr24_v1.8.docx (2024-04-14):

System Requirements Specification

for

Portable Ultrasound Device for Coda-Wave Interferometry

Version 1.8

Prepared by Michael Kisellus

Christopher Coppedge

Layton Foxworthy

Matthew Baker

Kyle Fox

13APR2024

Table of Contents

Table of Contents ii

Revision History ii

1. Introduction 4

1.1 Purpose 4

1.2 Document Conventions 4

1.3 Intended Audience and Reading Suggestions 4

1.4 Product Scope 4

1.5 References 5

2. Overall Description 5

2.1 Product Perspective 5

2.2 Product Functions 6

2.3 User Classes and Characteristics 6

2.4 Operating Environment 7

2.5 Design and Implementation Constraints 7

2.6 User Documentation 7

2.7 Assumptions and Dependencies 8

3. External Interface Requirements 8

3.1 User Interfaces 8

3.2 Hardware Interfaces 9

3.3 Software Interfaces 10

3.4 Communications Interfaces 10

4. System Features 10

4.1 System test pulse generation and reception 10

4.2 System self-regulation/ protection for overheat 11

4.3 System alarm system 12

4.4 After test processing 13

5. Other Nonfunctional Requirements 13

5.1 Performance Requirements 13

5.2 Safety Requirements 13

5.3 Security Requirements 14

5.4 System Quality Attributes 14

5.5 Business Rules 14

6. Other Requirements 14

Appendix A: Glossary 14

Appendix B: Analysis Models 15

Appendix C: Reference 16

Revision History

Name | Date | Reason For Changes | Version
Michael Kisellus, Christopher Coppedge, Layton Foxworthy, Matthew Baker, Kyle Fox | 1Feb | Initial draft | 1.0
Matthew Baker | 1 Feb | Initial draft, initial edit | 1.1
Michael Kisellus | 4Feb | Figure 3,5 update, Times new roman text, removed appendix D, updated table of contents, update appendix c | 1.2
Christopher Coppedge | 2/22 | Making changes based on TA feedback | 1.3
Michael Kisellus | 29Feb | Same as above | 1.4
Christopher Coppedge | 3/21 | Making changes based on TA feedback | 1.5
Michael Kisellus | 21Mar | correcting req 4.1.3.1 | 1.6
Matthew Baker | 31Mar | Making changes based on TA feedback | 1.7
Christopher Coppedge | 4 April | Final changes and review | 1.8

# Introduction

Bridges are vital transportation infrastructure that are used daily by millions of people. Like any constructed work, the material used has a finite lifespan and will degrade as both the effects of nature and its designed purpose act on the bridge. Being able to determine locations of failure points, subsurface cracks, and voids in building materials such as concrete can greatly increase the ability for an engineering team to predict future issues and plan remedial work for a bridge. To assist those engineers, the Portable Ultrasound Device (PUD) was designed. This device can be used in conjunction with ultrasonic transducers to detect anomalies within concrete. The data collected can be used to make future engineering decisions.

## Purpose

This document intends to define all requirements and conditions relating to the Portable Ultrasound Device. This document covers the physical device hardware, software required to operate the device, operator interaction with the device and the requirements used to produce the unit. As well as software used to process the data collected by the unit (if applicable).

## Document Conventions

Document is in keeping with the provided template, no other requirements exist for this document specific to this project.

## Intended Audience and Reading Suggestions

The intended user for this product is civil engineers and maintenance workers responsible for the integrity of bridge support pillars. This also applies for any profession working with or testing load bearing concrete support pillars such as inspectors or safety personnel. This document contains information on product functionality and requirements given by the client Dr. Brown. Section 2 contains an overall view of the project. Section 3 contains information and procedures for how to use the product. This would be most useful to a system operator or troubleshooter. Section 4 and 5 contain features and operational requirements for the system.

Section 1.4 contains any references used and is required to fully understand or troubleshoot the device.

## Product Scope

The goal of this system is to provide bridge maintenance and safety workers with a field service tool to detect crack propagation. This will allow the operator to gather data over the course of 72 hours and make a more accurate determination of the bridged pillars structural integrity and therefore make the bridge safer for all its users.

Produce a field service unit which after being placed to measure a concrete section will collect data over the course of 48 to 72 hours and be retrieved to review the collected data. The unit will be light enough for one person to move (less than 50 pounds), weather resistant and durable enough for field work.

## References

Appendix C contains the references used for the PUD project.

# Overall Description

Section 2 covers the project's purpose is section 2.1, product functions in section 2.2, user information in section 2.3, and description of the operating environment in section 2.4. Sections 5,6, and 7 contain constraints, user documentation and assumptions made for the unit.

## Product Perspective

The Portable Ultrasound Device for Coda-Wave Interferometry is a new, self-contained product that assists in the internal inspection of concrete support pillars. The system consists of a standalone unit for measuring and recording a concrete sample response to a transducer generated wave.

Figure 1 displays the overhead view of the system. Starting at point 1 a 500v 2 microsecond pulse is produced by the PUD. The transducer then vibrates at 54kHz and enters the concrete test sample shown at point 2. At point 3 the signal that has traveled through the concrete is received at a 2nd transducer and sends an electrical signal to the PUD shown as point 4.

Figure 1: overall system diagram for portable ultrasound device (PUD)

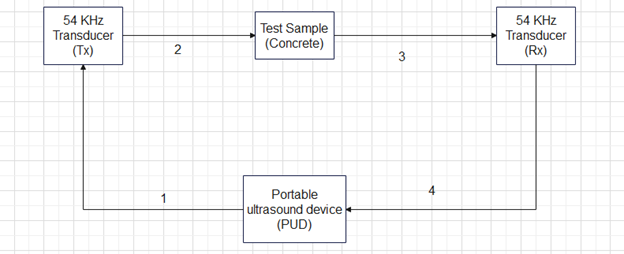
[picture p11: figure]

Figure 2: Portable ultrasound device(PUD) hardware diagram <removed, rev1.4>

## Product Functions

### The following section provides a list of the major functions the product must perform

### Generate a test pulse to the transistor transmitter (TX).

### Receive response signal from the transistor receiver (Rx)

### Store the received data locally (SD card)

### Process raw data offsite using computer programs.

### Monitor and maintain device functionality for an extended period of time.

## User Classes and Characteristics

### Data analyst

The Data analyst will receive the raw data from the receiving transducer. The raw data consists of voltages over time, which are then graphed and analyzed. The data analyst then makes the determination if there is interior structural damage. If the results are inconclusive then the data analyst can request the test engineer to take another sample or reposition the test transducer positions.

### Test engineer

The test engineer will be responsible for going into the field and performing transducer placement to perform the test. Activating the unit to collect data, then retrieving the unit 48 to 72 hours after test initiation.

## Operating Environment

### User interface

The user will interface with the device through a panel of push buttons, and electrical isolation switches. The user will have a panel of LEDs to show the PUD’s condition/status . Because the interface is physical it will require no exterior programs to function during testing.

### Data processing

The data saved during testing is saved on a Secure Digital (SD) card using .mat format (other formats may be considered but currently the civil engineering lab is using .mat). Requiring the user to possess a window 10 or later operating software. Python, possibly C (if lower level coding is required) and MATLAB programs are required to operate the analysis software.

## Design and Implementation Constraints

### Design constraints

2.5.1 The unit shall not exceed 50 pounds.

2.5.2 The unit shall be smaller than 30” x 30” x 20”.

2.5.3 The overall cost to manufacture the PUD unit shall not exceed $2000.00

2.5.4 The unit battery shall last for 72 hours with samples being taken every 10 min.

2.5.5 The unit shall have minimum data storage of 32 GB.

2.5.6 The unit shall not exceed operating temperatures of 140° F.

### Implementation constraints

2.5.7 The unit shall provide a Transmitter output pulse of 500V for 2µsec to the transducer.

## User Documentation

The following documents are the required documentation to operate the PUD.

### Users guide for PUD system.

### PUD system troubleshooting guide.

### PUD Analysis software tutorial guide.

## Assumptions and Dependencies

- Ambient temperatures during operation shall not exceed 100° F.
- The battery is fully charged before sampling starts.
- The battery is in good condition and has not degraded from age.
- The unit is placed in a dry location protected from major weather interference.
- The unit is not disturbed by unauthorized personnel during testing/ random passerby.
- The unit is used following the user manual.
- The user places the transistor transmitter and receiver correctly.
- The unit has no component failures.
- The user has a working laptop with Thonny and MATLAB installed.

# External Interface Requirements

Section 3 contains information regarding the user interface. This includes hardware and software interfaces. Section 3.1 ,3.2 and 3.3 cover the user, hardware and software interfaces. Section 3.4 covers the communication interface.

## User Interfaces

The user interface for the PUD is placed on the exterior of the unit and is designed to be extremely simple to operate for the user. Utilizing push buttons to start or stop the testing sequence. Then using software on a separate computer to analyze the data collected. Below is the operational procedure for users.

### 1.1.1 Turn on the unit's main power switch.

### 1.1.2 Verify power available light on. Shown on figure 3.

### 1.1.3 Verify no lights are illuminated in the alarm section. Shown on figure 3.

### 1.1.4 Select 10min, 6hr, 12hr, 24hr, 48hr, or 72hr testing time setting. Shown on figure 3.

### 1.1.5 Verify selected time setting indicating light is lit for selected time Shown on figure 3.

### 1.1.6 Press the start test button. Shown on figure 3.

### 1.1.7 Verify the test running status light is on. Shown on figure 3.

### 1.1.8 Wait for the test finished light to illuminate or select stop and save button to stop test early.

### 1.1.9 Turn off the main power switch.

### 1.1.10 Remove the memory storage SD card.

### 1.1.11 Place the SD card into the computer used for analysis.

Figure 3: Front panel for PUD


## 1.1 Hardware Interfaces

The PUD hardware has several input commands given by pushbuttons to interface with the Raspberry Pi pico which controls the testing procedure and writes the results to a removable hardware storage device (SD card). Which then interacts with Matlab (similar to file format this is subject to change) to produce the desired result.

### REQ 3.2.1 The push buttons(select, start and stop) shall input 5v command signals to the Raspberry Pi

### REQ 3.2.2 The Raspberry Pi Pico shall send a switching signal to the MOSFET to gate the 500v input on and off. The signal shall be sent 50 times during a testing period then wait 10 minutes.

### REQ 3.2.3 The Raspberry Pi Pico shall send PWM or digital switching signals to the cooling fan to control its speed and on/off status.

### REQ 3.2.4 The Raspberry Pi Pico shall send commands to the status and alarm LEDs to turn on or off

### REQ 3.2.5 The ADC chip shall receive inputs from the transducer receiver.

### REQ 3.2.6 The Raspberry Pi Pico shall send commands to the SD card to record the received signal.

### REQ 3.2.7 The SD card will store data and be kept in a computer and matlab readable format.

REQ 3.2.8 A laptop separate from the PUD shall run the Matlab software required to analyze the raw data.

## 1.2 Software Interfaces

The PUD system has one operating software system running on a Raspberry Pi pico unit. Then later in the process a laptop running Matlab is used to process the data retrieved from the test.

### REQ 3.3.1 Raw data from the receiving transducer shall be sent to SD card using .mat format.

### REQ 3.3.2 Laptop shall be running Windows 10 or later.

REQ 3.3.3 Laptop shall have Thonny and MATLAB installed.

## 1.3 Communications Interfaces

This section does not strongly apply to this unit as it does not contain any form of inter-device communications in a wireless form. However there are two common communication interfaces for the hardware. This consists of the SPI bus and a UART system.

REQ 3.4.1 The Raspberry Pi Pico will use the SPI bus to move data between internal components.

REQ 3.4.2 The Raspberry Pi Pico will use the UART system to allow for programming and system updates.

# System Features

Section 4 provides amplifying information on the system functions discussed in section 2.2.

## System test pulse generation and reception

4.1.1 Description and Priority

The PUD system’s main function is to provide the transducer with the pulse required to generate a testing frequency which propagates through the test material and is received by a second receiving transducer and returned as a voltage to the system and recorded. High

4.1.2 Stimulus/Response Sequences

After the user powers on the unit and selects a test duration, then the start test button is pressed.

The unit will then save results to the SD card over the course of the test duration. Which the user can then take after the test completes or the user stops the test early.

4.1.3 Functional Requirements

REQ 4.1.3.1 The electrical system shall be able to produce a 500 V 2µsec pulse.

REQ 4.1.3.2 The control system shall be able to gate the test signal on and off within 2µsec.

REQ 4.1.3.3 The system shall be able to produce 50 test signals with 100µsec interval between the test pulses.

REQ 4.1.3.4 The system shall convert the analog signal received from the receiver transducer into a digital signal which can be recorded.

REQ 4.1.3.5 The system shall be able to save the data received from the receiving transducer to a SD card.

REQ 4.1.3.6 The system shall have greater than or equal to 35 GB of storage space to store test data.

## 1.4 System self-regulation/ protection for overheat

4.2.1 Description and Priority

The PUD system performs self-monitoring of its internal temperature and activates the cooling systems to protect itself from entering failure conditions(131-140°F depending on the component). Shutting down if unable to correct the issue within 5 min to protect the system.

4.2.2 Stimulus/Response Sequences

No operator action required.

The internal temperature is detected to be approaching 131°F. This triggers the cooling fan to activate at a rate of revolutions per minute in accordance with a pre-programmed hysteresis curve (as seen in Figure 4) and cool the unit with ambient air from the unit’s surroundings.

4.2.3 Functional Requirements

REQ 4.2.3.1 The system shall be able to monitor internal temperatures within the unit.

REQ 4.2.3.2 The system shall run the cooling fan via pulse-width modulation in accordance with a pre-programmed hysteresis curve.

REQ 4.2.3.3 The system shall shut down in the event that temperatures cannot be reduced below the danger level.

## 1.5 System alarm system

4.3.1 Description and Priority

The system shall monitor for various failure conditions and alert the user to any detected abnormalities. This includes overtemperature, SD card full, and low battery. Low

4.3.2 Stimulus/Response Sequences

No user input required

Overheat, SD card Full, or low battery event occurs.

The system will illuminate a LED on the alarm panel to alert the user.

4.3.3 Functional Requirements

REQ 4.3.3.1 The system shall be able to monitor internal unit temperature.

REQ 4.3.3.2 The system shall turn power on for the overheated LED on the alarm panel if temperature exceeds or is equal to 125°F for more than 1 min.

REQ 4.3.3.3 The system shall shut down if temperature exceeds or is equal to 130°F for more than 30 seconds.

REQ 4.3.3.4 The system shall be able to monitor SD card status.

REQ 4.3.3.5 The system shall power on if no SD card is inserted and flash the “SD Card Full” and “Power” LEDs if the card is not present.

REQ 4.3.3.6 If no SD card is present, the machine shall not perform the test phase.

REQ 4.3.3.7 The system shall turn power on for the SD card full LED on the alarm panel if the SD card is 95% of max storage capacity.

REQ 4.3.3.8 The system shall record over the oldest data on the SD card if the error is not corrected.

REQ 4.3.3.9 The system shall be able to monitor battery voltage.

REQ 4.3.3.10 The system shall turn power on for the low battery LED on the alarm panel if the battery voltage drops to or below 10.5V

REQ 4.3.3.11 The system shall turn off the system if battery voltage is below 10V for greater than 1 min.

## After test processing

4.4.1 Description and Priority

The programs used to process the data retrieved from the PUD unit SD card. Making the raw data useful and displaying it in a useful format for analysis.

4.4.2 Stimulus/Response Sequences

Sd card is placed in laptop used for processing and analyzed using Matlab

4.4.3 Functional Requirements

REQ 4.4.3.1 SD Card slot shall be protected by an external cover that requires external action to open

REQ 4.4.3.2 SD Card shall contain a locking latch mechanism

REQ 4.4.3.3 SD Card slot shall present an alignment guide to ensure proper insertion

# Other Nonfunctional Requirements

Section 5 consists of requirements and regulations other than the ones stated in previous sections.

## Performance Requirements

The system shall operate for 48 to 72 hours without recharging the internal battery

The system shall have fans and thermal monitoring to ensure components do not overheat in accordance with (IAW) applicable component requirements.

## Safety Requirements

### The system shall have an external safety lock to protect the user from high voltages present within.

### The system shall have a warning posted on the outside to alert the user to secure power and wait 40 minutes prior to opening due to risk of shock from high voltage supply and capacitor bank.

The safety lock shall be electrically isolated from any of the high voltage components to prevent shock.

## Security Requirements

The project has no security requirements as the data is not sensitive or private.

## System Quality Attributes

### All system components shall be tested prior to installation

### The system when fully constructed shall be tested using a test plan.

A parts list shall be provided along with the finished product to the user.

## Business Rules

Only personnel who have read the operating manual should operate the equipment.

# Other Requirements

## The case shall be able to withstand a fall from 3 ft and protect the contents of the case

The case shall be water resistant and be able to protect the contents from water penetration from rain

The electrical distribution system shall not exceed a component's rated limits, as shown in its related datasheet.

The electrical system shall have no faulty components.

The electrical system shall produce 5,12, and 500V DC.

The electrical system shall have sheathing protection.

The electrical system components shall be securely mounted to the casing.

The electrical system shall have no unintended paths to ground.

Appendix A: Glossary

Abbreviation | Full spelling
LED | Light emitting diode
MOSFET | Metal-oxide-semiconductor field-effect transistor
PUD | Portable Ultrasound Device
Rx | Rx- Receiver
Tx | Tx- Transmitter
SD | Secure Digital card
IAW | In accordance with

Appendix B: Analysis Models

Figure 4: Cooling fan behavior vs temperature


Figure 5: Electrical system schematic diagram


Appendix C: Reference

“021706.3TXP Littelfuse Inc. | Circuit Protection | DigiKey.” DigiKey, www.digikey.com/en/products/detail/littelfuse-inc/021706-3TXP/3425317. Accessed 21 Oct. 2023.

“05200005ZXGY Littelfuse Inc. | Circuit Protection | DigiKey.” DigiKey, www.digikey.com/en/products/detail/littelfuse-inc/05200005ZXGY/554334. Accessed 21 Oct. 2023.

“0ADKC5000-Be Bel Fuse Inc. | Circuit Protection | Digikey.” DigiKey, www.digikey.com/en/products/detail/bel-fuse-inc/0ADKC5000-BE/7404459. Accessed 21 Oct. 2023.

“100ft - 1/2 Inch Pet Expandable Braided Sleeving - Amazon.Com.” Amazon, www.amazon.com/100ft-Expandable-Braided-Sleeving-braided/dp/B074GMNW7T. Accessed 21 Oct. 2023.

“12-48V Battery Isolator Switch for Car Vehicle RV and Marine (on/off): Eco-Worthy.” ECO, www.eco-worthy.com/products/12-48v-battery-isolator-switch-for-car-vehicle-rv-and-marine-on-off?variant=40589578567868. Accessed 21 Oct. 2023.

“2-1546306-1 TE Connectivity AMP Connectors - DigiKey Electronics.” DigiKey, www.digikey.com/en/products/detail/te-connectivity-amp-connectors/2-1546306-1/1136667. Accessed 21 Oct. 2023.

“330 PCS M2 Male Female Brass Hex Spacer Standoffs Screws ... - Amazon.Com.” Amazon, www.amazon.com/Standoffs-Assortment-Threaded-Circuit-Motherboard/dp/B0BZYTC581. Accessed 21 Oct. 2023.

“577002B00000G Aavid, Thermal Division of Boyd Corporation - Digikey.” DigiKey, www.digikey.com/en/products/detail/aavid-thermal-division-of-boyd-corporation/577002B00000G/102507. Accessed 21 Oct. 2023.

“5A 12V Automatic Smart Battery Charger and Maintainer with LCD Display for Lead Acid and Lithium (LiFePO4) Batteries: Eco-Worthy.” ECO, www.eco-worthy.com/products/5a-12v-automatic-smart-battery-charger-and-maintainer-with-lcd-display-for-lead-acid-and-lithium-lifepo4-batteries?variant=42350017052921. Accessed 21 Oct. 2023.

“6AWG (16mm2) 13 Inch Battery Interconnect Cable: Eco-Worthy.” ECO, www.eco-worthy.com/products/6awg-16mm-13-inch-battery-interconnect-cable?variant=34593133625509. Accessed 21 Oct. 2023.

“Als30a332np500 Kemet | Capacitors | Digikey - Digi-Key Electronics.” Digikey, www.digikey.com/en/products/detail/kemet/ALS30A332NP500/3462159. Accessed 21 Oct. 2023.

“Amazon.Com: 2Pcs Electronic Thermostat Controller W1209 DC 12V Digital ...” Amazon, www.amazon.com/Electronic-Thermostat-Controller-Waterproof-Temperature/dp/B08Y6L34PX. Accessed 4 Feb. 2024.

“Amazon.Com: Tsa Approved Luggage Locks, Travel Locks Which Also Work ...” Amazon, www.amazon.com/Approved-Luggage-Travel-Toolbox-Backpack/dp/B07MVJZ6C2. Accessed 4 Feb. 2024.

“Amazon.Com: XHF 3/4" Strong Back-Glue Self Adhesive Black Cable Zip Tie ...” Amazon, www.amazon.com/XHF-Back-Glue-Protection-Fasteners-Management/dp/B08F77YVYB. Accessed 21 Oct. 2023.

“ANCOR Marine Grade Primary Wire and Battery Cable - Amazon.Com.” Amazon, www.amazon.com/Ancor-Marine-Grade-Primary-Battery/dp/B07ZSDK651. Accessed 21 Oct. 2023.

“ANSI Z535 Safety Labels - Hazardous Voltage Inside.” Seton, www.seton.com/ansi-z535-safety-labels-hazardous-voltage-inside-l5476.html?utm_campaign=%5BNB%5D_Labels_Catch%2BAll_PLA-S_High_All_PC-02_GGL_SUS&utm_source=google&utm_medium=cpc&utm_term=&matchtype=&device=c&adgroupid=&gclsrc=aw.ds&gclid=CjwKCAjwseSoBhBXEiwA9iZtxo15KyzhNfMKE5oyzbC-vorhbGmpge9ewSppeK7ReCrhPLgh6Yt0NRoCVhcQAvD_BwE. Accessed 21 Oct. 2023.

“ASEV30-B Altran Magnetics, LLC | Relays | Digikey.” DigiKey, www.digikey.com/en/products/detail/altran-magnetics-llc/ASEV30-B/14120027. Accessed 4 Feb. 2024.

“C503C-Wan-CCADB232 Creeled, Inc. | Optoelectronics | DigiKey.” DigiKey, www.digikey.com/en/products/detail/creeled-inc/C503C-WAN-CCADB232/2681196. Accessed 21 Oct. 2023.

“CF12JT390R Stackpole Electronics Inc | Resistors | Digikey.” DigiKey, www.digikey.com/en/products/detail/stackpole-electronics-inc/CF12JT390R/1741140. Accessed 21 Oct. 2023.

“DC 12V 24V to 5V Step down Converter Regulator 5A 25W Power Adapter ...” Amazon, www.amazon.com/Converter-Regulator-Adapter-Reducer-Electronics/dp/B07Q5W1BG3. Accessed 21 Oct. 2023.

“Dolby Vision + Dolby Atmos - Amazon.Com.” Amazon, www.amazon.com/Hisense-Premium-50U6G1-Quantum-Compatible/dp/B09TWYDMPY. Accessed 4 Feb. 2024.

“E/Fusing 900 Moldable Silicone Putty - Black - Amazon.Com.” Amazon, www.amazon.com/E-FUSING-900/dp/B0B6JWT295. Accessed 4 Feb. 2024.

“High Voltage Power Supply AHV12V500V20MAW Analog Technologies | Power ...” DigiKey, www.digikey.com/en/products/detail/analog-technologies/High-Voltage-Power-Supply-AHV12V500V20MAW/18621897. Accessed 21 Oct. 2023.

“HTTPS: //WWW. Amazon. COM/GP/Product/B00955337I/Ref=oh_aui_detailpage ...” Amazon, www.amazon.com/gp/customer-reviews/R2WSHBZW6W1Z0K/. Accessed 4 Feb. 2024.

“HTTPS: //WWW. Amazon. COM/GP/Product/B00955337I/Ref=oh_aui_detailpage ...” Amazon, www.amazon.com/gp/customer-reviews/R2WSHBZW6W1Z0K/. Accessed 4 Feb. 2024.

“LiFePO4 12V 50ah Lithium Iron Phosphate Battery: Eco-Worthy.” ECO, www.eco-worthy.com/products/lifepo4-12v-50ah-lithium-iron-phosphate-battery?currency=USD&variant=42491122712825&utm_medium=cpc&utm_source=google&utm_campaign=Google+Shopping&stkn=ac7b7d784bf0&gclid=CjwKCAjwgsqoBhBNEiwAwe5w02e_e41oUWis8aF0zZ64SqB2gfhDZQGvhFikRSAGGwQNgwVP8l8POBoCaacQAvD_BwE. Accessed 21 Oct. 2023.

“Miuzei PCB Board Prototype Kit for Electronic Projects, Circuit Solder ...” Amazon, www.amazon.com/Miuzei-Including-Prototype-Connector-Terminal/dp/B07PS4VCDD. Accessed 21 Oct. 2023.

“Ohmite Distributor | DigiKey Electronics.” DigiKey, www.digikey.com/en/supplier-centers/ohmite. Accessed 21 Oct. 2023.

“PMV16XNR Nexperia USA Inc. | Discrete Semiconductor Products | DigiKey.” DigiKey, www.digikey.com/en/products/detail/nexperia-usa-inc/PMV16XNR/5395791. Accessed 21 Oct. 2023.

“Ra-T2X-38E Ohmite | Fans, Thermal Management | DigiKey.” DigiKey, www.digikey.com/en/products/detail/ohmite/RA-T2X-38E/2416488. Accessed 21 Oct. 2023.

“SBBSM2106-1 Chip Quik Inc. | Prototyping, Fabrication Products | DigiKey.” DigiKey, www.digikey.com/en/products/detail/chip-quik-inc/SBBSM2106-1/5978238. Accessed 21 Oct. 2023.

“Starelo 5pcs 12mm Momentary Push Button Switch Black Shell with Pre ...” Amazon, www.amazon.com/Momentary-Push-Button-Switch-Without/dp/B09BKZ68HF. Accessed 21 Oct. 2023.

“STF19NM50N Stmicroelectronics | Discrete Semiconductor Products | DigiKey.” DigiKey, www.digikey.com/en/products/detail/stmicroelectronics/STF19NM50N/2346299. Accessed 21 Oct. 2023.

“TE120B2K7J Te Connectivity Passive Product | Resistors | DigiKey.” DigiKey, www.digikey.com/en/products/detail/te-connectivity-passive-product/TE120B2K7J/14308543. Accessed 21 Oct. 2023.

“TMP37FT9Z Analog Devices Inc. | Sensors, Transducers | DigiKey.” DigiKey, www.digikey.com/en/products/detail/analog-devices-inc/TMP37FT9Z/1217626. Accessed 4 Feb. 2024.

Copyright © 1999 by Karl E. Wiegers. Permission is granted to use, modify, and distribute this document.

Software Requirements Specification for Portable Ultrasound Device for Coda-Wave Interferometry Page 3

Software Requirements Specification for <Project> Page 0

Software Requirements Specification for Portable Ultrasound Device for Coda-Wave Interferometry Page 23

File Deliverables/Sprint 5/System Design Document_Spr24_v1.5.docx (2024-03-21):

System Design Document

Dr. Brown Capstone Project Spring ‘24:

Portable Ultrasound Device for Coda-Wave Interferometry

Team members:

Michael Kisellus, Matthew Baker, Layton Foxworthy, Kyle Fox, and Christopher Coppedge

Version | Author | Change | Date
v1.0 | Michael Kisellus, Matthew Baker, Layton Foxworthy, Kyle Fox, and Christopher Coppedge | Initial draft | 1/23/2024
v1.1 | Michael Kisellus | Times new roman text, figure 6,7 update, print format to make more readable, update references, update table of context, table 2 update | 4Feb2024
V1.2 | Kyle Fox | Updated readability | 5Feb2024
V1.3 | Michael Kisellus | Corrections from SDD feedback | 15,20Feb2024
V1.4 | Michael Kisellus | Same as above | 29Feb2024
V1.5 | Kyle Fox | Update Software architecture sections | 01Mar2024

# TABLE OF CONTENT

SYSTEM DESIGN DOCUMENT

Overview

The System Design Document describes the system requirements, operating environment, system and subsystem architecture, files and database design, input formats, output layouts, human-machine interfaces, detailed design, processing logic, and external interfaces.

# 1 INTRODUCTION

Bridges are vital transportation infrastructure that are used daily by millions of people. Like any constructed work, the material used has a finite lifespan and will degrade as both the effects of nature and its designed purpose act on the bridge. Being able to determine locations of failure points, subsurface cracks, and voids in building materials such as concrete can greatly increase the ability for an engineering team to predict future issues and plan remedial work for a bridge. To assist those engineers, the Portable Ultrasound Device (PUD) was designed. This device can be used in conjunction with ultrasonic transducers to detect anomalies within concrete. The data collected can be used to make future engineering decisions.

## 1.1 Purpose and Scope

The PUD is a handheld ultrasound inspection device for inspecting bridges and structural components for faults in the field. This handheld unit will have an independent power supply and will collect and store test data. The PUD is fully capable of its precise data collection duties while still being durable enough to withstand difficult environmental conditions such as shock from a fall, rain, and other environments a field tool will be exposed to.

## 1.2 Project Executive Summary

This PUD unit primarily consist of commercial off-the-shelf (COTS) components engineered into a cohesive system that matches our requirements. The production management for the PUD project is Agile Scrum. Dividing the PUD project into 3 sprints over the course of an 11-week timeline.

### 1.2.1 System Overview

The PUD system will output a pulse signal to the transducer as shown in figure 2 point 1. The transducer then uses the piezoelectric effect to produce a 54kHz test signal, this signal propagates into the connected concrete sample being tested. The signal then propagates to a second transducer placed on opposing side of the concrete sample. Through the piezoelectric effect the second transducer converts the 54kHz signal into a low-level voltage which is returned to the PUD to be processed.

Note: The 54 kHz is due to the manufacturer of the transducer NDT James Instruments. It is designed to produce this frequency

The use case diagram shown in figure 1 describes the options an operator can use to operate the PUD system. The operator may charge the battery or remove the storage device (SD) card when the power is off to the main system. The main functionality is accessible when the operator turns the unit's power on. Allowing the operator to enter the test duration by repeatedly pressing the test duration button to cycle through the options. The test duration selected is displayed on the face plate LED’s 6,7,8,9, and 10 shown in figure 6. The operator may press the start button to initiate the test. The operator may also stop the test before the test duration ends and save the resulting data to an SD card.

Figure 1: Use Case Diagram


Figure 2: overall system diagram


### 1.2.2 Design Constraints

The design of the system will balance system weight vs battery life, battery consumption vs cooling, and accuracy vs component price. One of the requirements of the system is that it must remain portable and as such we will be keeping the unit as light as possible. This comes in direct competition with battery life, which also has its own requirement. Battery consumption and cooling are also going to have to be balanced to ensure the hardware, specifically the battery, stays within operating temperature. This would lead us to running the fans more but that increases battery consumption and decreases how long the system can be used in the field. Lastly, more accurate signal processing hardware costs more than its less accurate counterpart so our design uses components that are within the project’s budget of $2000 and are also accurate enough for our application.

### 1.2.3 Future Contingencies

The exact requirements of the system are dependent on the civil engineering laboratory (Lab run by Professor Brown), which serves as the primary stakeholder for the system. They will be the primary user of the PUD once it is operational so the requirements must match their expectations. Any changes to the system will depend on their wants and needs. The civil engineering lab already has some components of the final system, these are not going to change and are proven to operate correctly from previous testing.

Operating with 500V requires specialized components and rated insulative material to protect the system from inadvertent grounds or component failure. If components fail during testing a higher voltage rated component may be purchased to replace insufficient performing parts.

The Metal oxide semiconductor field effect transistor (MOSFET) component used must switch on and off quickly to fulfill its purpose. If the component is unable to meet specifications during testing a better/ more expensive component may need to be purchased to replace this component.

The oscilloscope used to sample the return signal needs to be sampled extremely quickly to capture the return signal in detail. This component may need to be replaced if testing reveals the sample rate to be insufficient.

## 1.3 Document Organization

The document adheres to the organizational structure and formatting prescribed by the course. Every section, heading, and subheading has been aligned with the template guidelines to maintain a consistent and professional appearance. By following the provided instructions and formatting guidelines, we aimed not only to meet the basic requirements but also to contribute to the overall uniformity of documentation between the multiple teams. This approach ensures that the professors and TAs can easily navigate the document.

Part 1 contains the INTRODUCTION which has 8 subsections: Purpose and Scope, Project Executive Summary, System Overview, Design Constraints, Future Contingencies, Document Organization, Project References, and the Glossary. Overall, this section describes the system, constraints, contingencies and the documentation associated with the system.

Part 2 contains the SYSTEM ARCHITECTURE which has 3 subsections: System Hardware Architecture, System Software Architecture, Internal Communications Architecture. Overall, this section describes the system hardware and software architecture for the PUD system. The hardware section is subdivided by systems.

Part 3 contains the HUMAN-MACHINE INTERFACE which has 2 subsections: Inputs and Outputs. Overall, this section describes the inputs a user can make and the outputs the PUD system will produce.

Part 4 contains the DETAILED DESIGN which has 3 subsections: Hardware Detailed Design, Software Detailed Design, Internal Communications Detailed Design. Overall, this section provides an in-depth explanation of the systems used to construct the PUD system.

Part 5 contains the EXTERNAL INTERFACES which has 2 subsections: Interface Architecture and Interface Detailed Design. Overall, this section describes other systems the PUD system must interface with to operate. This section is small because the system is self-contained and does not communicate to exterior systems during operation.

Part 6 contains the SYSTEM INTEGRITY CONTROLS. Overall, this system has to do with data security and software protection. This section is small due to the unit not requiring data protection as the PUD does not contain sensitive information.

## 1.4 Project References

This section provides a bibliography of key project references and deliverables that have been produced before this point.

International Electrotechnical Commission (2013). Degrees of protection provided by enclosures (IP Code) (IEC 60529). Retrieved from https://website.iec.ch/publication/2452

Parts references are placed at the end of the document in table 3.

## 1.5 Glossary

Supply a glossary of all terms and abbreviations used in this document. If the glossary is several pages in length, it may be included as an appendix. Shown in table 1.

Table 1: glossary

IP Rating [IPAB]

Ingress Protection rating as codified under the IEC 60529 standard, where A is the device’s resistance to solid particle such as dust from zero (no protection) to 6 (most protection) and B is the device’s resistance to liquids from zero (no protection) to 9K (most protection). (International Electrotechnical Commission [IEC], 2013)

An IP55 rating means:

5-Ingress of dust is not entirely prevented, but it must not enter in sufficient quantity to interfere with the satisfactory operation of the equipment.

5-Water projected by a nozzle (6.3 mm) against enclosure from any direction shall have no harmful effects.
PUD | Portable ultrasound device
LED | Light emitting diode
piezoelectric effect | Applying mechanical stress to a crystal produces an electrical charge and vice versa.
MOSFET | Metal oxide semiconductor field effect transistor
UART | Universal asynchronous receiver transmitter
HMI | Human machine interface
PC | Personal computer
Tx | Transmitter
Rx | Reciever
SD | Storage device
FRD | Functional requirement document
RTM | Requirement traceability matrix

# 2 SYSTEM ARCHITECTURE

This section outlines the overall system architecture, including both software and hardware architecture for the PUD system and subsystems.

Figure 3 shows the PUD physical components and their interactions. Point 1 shows that the cooling fan receives power to operate from the battery. Point 2 shows that the analog to digital converter delivers its data to the central control chip. Point 3 shows that the pulse generator is controlled by the central control chip. Point 4 shows that the pulse generator controls the MOSFET gating on or off. Point 5 shows that The MOSFET outputs to the Transducer. Point 6 shows that the central control chip transfers data to the SD card. Point 7 shows that the central control chip monitors the battery voltage. Point 8 shows that the cooling fan is controlled by the central control chip. Point 9 shows that the status LEDs are controlled by the central control chip. Point 10 shows that the central control chip receives power from the battery. Point 11 shows that the status LEDs are powered by the battery. Point 12 shows that the transducer transmits a signal to the analog to digital converter. Point 13 shows that the MOSFET input is provided by the DC-to-DC converter. Point 14 shows that the DC-to-DC converter is powered by the battery.

Figure 3: Portable ultrasound device (PUD) internal components block diagram


## 2.1 System Hardware Architecture

This section, describes the overall system hardware and organization. The system hardware is broken into 2 subsystems: Cooling System, Electrical System.

### 2.1.1 Cooling System

The cooling system consists of multiple 80mm fans each connected to an integrated fan controller and temperature sensor to operate independently from one another to ensure that if one fan goes down the other(s) can still operate as well as making sure each area within the case gets the airflow that it requires. The fans will be placed on either end of an inner metal frame to drive the airflow over the components in the most efficient manner possible. The fan’s RPM rate will be tied to the internal temperature of local components (detected via the controller) via the following curve shown in figure 4. This curve is designed by the manufacturer of the fan components.

Figure 4: Cooling fan behavior chart


While the system’s design considers the possibility for the fans to run at maximum for the entire operating time, this thermal curve is in keeping with industry standards for keeping a computer system cooled while preventing too much current and power use from the internal power supply and thus preventing premature power drain.

Parts List:

# Twin NMB 08025SE-12Q-FT-DW Fan, 12VDC, 3.12 Watts at 0.26 Amps for variable cooling

# Twin Orion Fans OD8025-12HBIP5501A-ND Fans, 2.2 Watts at 0.18 Amps for cooling while charging

# EMC2101 integrated fan controller and thermocouple, 3/5V DC connected to central board.

### 2.1.2 Electrical System

The PUD electrical system consists of a 12v battery bank which is used to power various loads. Such as LED’s and cooling fans. There is a subsystem for charging the battery which is disconnected through an externally operable switch. The high voltage section consists of a 12v DC to 500v DC converter and a capacitor bank to maintain voltage. Electrical schematic shown in figure 3 below.

Parts list for electrical systems are shown in table 2 but parts may be replaced with equivalent parts.

Figure 5: PUD Electrical system


## 2.2 System Software Architecture

The software system is made up of two parts, the Raspberry Pi Pico, and the minicomputer. Both parts work independently to control the system and record data.

The Raspberry Pi Pico (RP Pico) handles system control through a state machine with three separate states. Each state controls a different part of the hardware system. The first state allows for button interrupts to control movement to the next state. The second state allows for pulse control and overall system timing. The third state changes the total test time of the system.

The microcomputer will run a Python-C wrapper to program the oscilloscope to do automated data collections. This collection will be done without human intervention and store the data on an SD card within the computer for later retrieval.

## 2.3 Internal Communications Architecture

The internal communications will consist of USB, Digital IO, and UART. The Universal asynchronous receiver transmitter (UART) will allow us to program the microcontroller. USB will be used to control and program the Oscilloscope as well as preform data collection/storage. The microcontroller will use the digital IO pins to control the Human machine interface (HMI) and pulse control. Shown in figure 8.

There will be no communication between the microcontroller and the minicomputer as the buttons will control microcontroller function and the oscilloscope will have automatic data collection. The microcontroller will however send a pulse to the oscilloscope at the same time as the control pulse is sent to the transducer.

Figure 8: Internal Communications Architecture diagram


# 3 HUMAN-MACHINE INTERFACE

The PUD system will have input from the user to start the system and to determine how long the system should operate. This will be performed through physical buttons. As for outputs the PUD will have LED indicators to display the system’s status to the operator. Additionally, a removable SD card will be able to be extracted from the system after it has gathered the desired data.

## 3.1 Inputs

The PUD system inputs will be physical buttons that send a voltage signal to the microcontroller. Because it is a simple 2-state button the PUD will have the input to the microcontroller be a simple binary input. The buttons will correspond to modes that set the time the system will be in operation. This simplicity will make I/O controls simple and reliable.

The front panel physical button I/O options will be “Test System”, “6 Hour”, “12 Hour”, “24 Hour”, “48 Hour”, “72 Hour”, “Start Test” “Select Test Duration” and “Stop Test”. As shown in figure 6.

Figure 6: Input panel for PUD

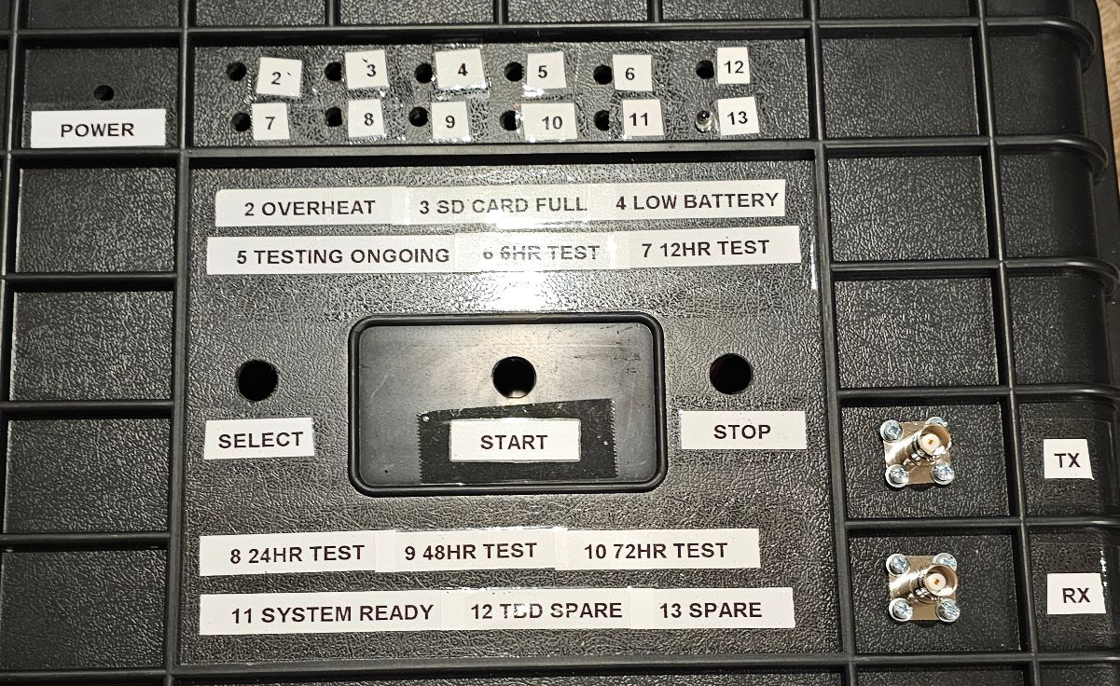
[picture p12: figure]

## 3.2 Outputs

The outputs from the system come in two different forms. The data from the operation of the system, and the indicators that tell the operator the status of the system. The operator indicators will be presented on LEDs and the system’s output data from the concrete measurement will be stored on an SD card.

The operator’s indicators will be the representation of binary values in our microcontroller. The implementation of this will depend on the voltage the microcontroller is able to output so if it is not able to power the LED we may need a relay to switch the LED on. The indicators will include “Power Available”, “Low Battery”, “High Temperature”, “SD Card Full”, “Unit Charging Capacitor” and more if needed.

The data the system collects about the concrete will need to be converted to a digital signal and stored through the oscilloscope. This will then be written to an SD card in the minicomputer for the operator to retrieve when the system is done with its operation. The retrieval will require the case to be opened. This helps protect the SD card against the weather. The output file on the SD card will be set within the minicomputer program as a “.mat” file.

Note: Expanding on the source of the data the system collects: After the system transmits a 500 v pulse to the Transmitting (Tx) transducer. The transducer vibrates and those vibrations travel through the concrete/sample. The vibrations then reach the receiving (Rx) transducer and the vibrations are converted to a electrical voltage. This voltage is read by the connected oscilloscope and processed into a graph of the resulting voltages over time. This graph is then saved for review by human operators on a removable SD card or other storage device.

Figure 7: Output panel for PUD

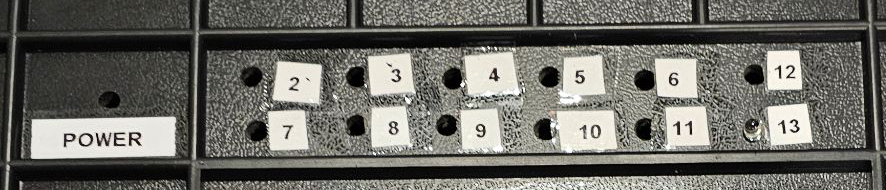
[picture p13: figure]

# 4 DETAILED DESIGN

This section provides the information needed for a system development team to build and integrate the hardware components, code, and integrate the software modules, and interconnect the hardware and software segments into a functional product. Additionally, this section addresses the detailed procedures for combining separate COTS packages into a single system. Every detailed requirement should map back to the Functional requirement document

(FRD), and the mapping should be presented in an update to the Requirement traceability matrix (RTM) and include the RTM as an appendix to this design document.

## 4.1 Hardware Detailed Design

The low-level hardware design is split into 5 distinct parts. The microcontroller and control system, the output signal, the input signal, the environment control, and the power system.

### 4.1.1 Environment Control and Cooling System

The cooling system consists of pre-fabricated aluminum heat sinks attached to the various “hotspots'' of the system (CPUs, Capacitor bank, DC-DC convertor, etc.) via thermally-conductive and electrically neutral compounds such as grease or adhesive pads. These components are then attached via standoffs to a grounded aluminum frame to act as a heat spreader and to prevent electrical short circuits. This frame will consist of sheet aluminum bent into a U-shaped frame to house the actual internal components, with cutouts for wires and connectors, and a removable aluminum top panel fit by friction to enclose the “box” to better channel air across the components. The actual action of cooling the system is provided by Orion Fans OD8025-12HBIP55 fans placed into the casing so that one acts as an intake fan and the second as an exhaust fan. These fans are then connected to the aluminum box via plastic shrouds that will channel the air through the aluminum frame for maximum static pressure. Each fan in and of itself has an IP55 rating to aid in the overall elemental resistance of the unit. In the event that the temperature inside the case approaches the thermal cutoffs/damage zones for the components (i.e. 131 degrees Fahrenheit for the DC-DC converter), the fans will be spun up to maximum RPM to prevent thermal throttling or damage to the components and will reduce RPMs according to a programmed hysteresis curve in the system’s firmware. The source of the temperature information will from the EMC2101 integrated fan controller breakout boards in the main body each of which will be in a different position within the case (e.g.beside the DC-DC converter) to ensure that each fan can operate independently as well as run at a speed that will aid in cooling local components..Additional fans and controllers may be added to provide airflow and cooling to other components inside the case (i.e. battery, capacitors, etc.). Each fan draws 2.2 watts at 0.18 amps, and each board requires a 3-3.6V supply voltage to operate effectively which it can receive from the Raspberry Pi Pico at the heart of the system. The fan controller boards connect to the fans via a standard 4-pin fan connector and to the Pico via a V_in, GND, and 3V pinout. The aluminum selected for the frame is 5052-H32 sheet aluminum at a thickness of 0.4mm which has strong corrosion resistance and is used in marine environments.

### 4.1.2 Electrical and Power System

The electrical system consists of 2 main buses. Note: electrical bus bars are used to distribute power. A 12 V DC bus and a 500 V DC bus are used.

The 12 V DC bus consists of 2 loops. The first loop is used to recharge the LiFePO4 12V 50Ah Lithium Iron Phosphate Battery. The battery is connected using 6 AWG (16mm²) 13 Inch Battery Interconnect Cable to the exterior of the casing and is accessible without opening the case. A Battery Isolator Switch for Car Vehicle RV and Marine (On/Off) is used to isolate the battery charging loop when not in use. The battery charger used is a 5A & 10A 12V Smart Battery Charger with LCD Display for Lead Acid and Lithium (LiFePO4) Batteries. The second loop connects the battery to the 12 V DC load bus which powers the various loads of the system. The battery has a switch to open this loop and turn off the system. The battery connects to the 10 Position Wire to Board Terminal Block Horizontal with Board. This is used to connect the various 12 v loads. Including the LED indicating lights which require a 453 Ohms ±1% 0.25W, 1/4W Through Hole Resistor Axial Metal Film to reduce voltage and current to 3.3v and 20mA for the LED to operate. The LED uses a Transistor’s: Bipolar (BJT) Transistor NPN 36 V Through Hole TO-92-3 to receive signals from the controlling chip to turn on or off. The cooling fan receives power from this bus. The controlling chip receives its power from this bus. The DC 12v 24v to 5v Step Down Converter Regulator 5A 25W Power Adapter Reducer for Car Electronics Truck Vehicle Boat Solar System (Accept DC 8-40V Inputs) receives power from this bus and its output is used as control power on the Enclosed DC to DC Converter 1 Output 0 ~ 500V 20mA 13V Input. The 12V DC to 500V DC converter receives its main power from this bus and sends power to the 500V bus.

The 500V DC bus starts at the 12V DC to 500V DC converter and is used to charge a 3300 µF 500 V Aluminum Electrolytic Capacitor which acts as a voltage regulator for normal operation. Amcor Marine Grade Primary Wire and Battery Cable is used for the 500 v portions of the circuit to connect the circuit components. A 47 kOhms ±5% 50W Wire wound Chassis Mount Resistor is used in series with the capacitor to prevent current from exceeding the 20mA limit of the converter while charging the capacitor. Finally, a MOSFET N-Channel 500 V 14A (Tc) 30W (Tc) Through Hole TO-220FP is used to gate the 500 V DC source on for 2*10^-6 sec. This pulse then travels to the transducer and leaves the PUD system. Figure 3 above displays the electrical schematic.

### 4.1.3 Microcontroller and Control

This part of the PUD can be affectionately considered the brains of the PUD. The microcontroller and control system handles both user inputs, timing of data collection from the input signal, control of the output signal, and allows for user retrieval of data from the SD card.

This system uses the bus architecture described earlier to communicate with both the SD card and the ADC. This allows data to move through the microcontroller to the SD card with minimal latency for further data collection.

### 4.1.4 Output Signal

This is the 500V DC signal that pings the transducer. The system uses a DC-DC converter to charge 500V and release a 2-microsecond pulse to the transducer allowing the semiconductive nature of the crystal to ring. This is activated by the microcontroller and is timed to allow the input signal to be unaffected by the “strike” of the output transducer.

### 4.1.5 Input Signal

The input signal is a 1V peak signal that is fed into a high-speed high bandwidth ADC. This ADC converts the analog signal into a digital stream that is fed into the microcontroller. This signal is the representation of the concrete health, this signal must be captured in its entirety and for its whole duration. This is done by using the ADC filtering functions to remove noise and capture the whole waveform for data processing. Once the ADC has captured a portion of the signal, the microcontroller moves the data over SPI to the SD card for processing by the data analysis program, which is off system.

## 4.2 Software Detailed Design

Software design of the microcontroller consists of a state machine of 3 states. This is done to reduce the chance of functions or control running in error. This design also allows for a major simplification of the overall system by allowing for the minicomputer to not communicate directly with the microcontroller.

This simplification of design parameters allows for each state to control the program with a minor number of function calls that operate linearly. The first state allows for input from buttons to step into the next state. This “waiting” state allows for the user to press the start button to go to state 2 and begin the test, stop button to do nothing, and select button to go to state 3 and change the total test time. The second “running” state will control the pulse control, system timing, and overall control. The third “select” state changes the current total test time value.

## 4.3 Internal Communications Detailed Design

USB Communication will be the method in which the PC will communicate with the oscilloscope. The oscilloscope will be preprogrammed with a function that will allow for automated data collection. This software is sourced from the manufacturer. This automated data collection will allow for the program to store data on the computer without human intervention.

Shown in figure 9.

Figure 9: Rx system


The microcontroller will use its Digital IO pins to turn LEDs on and off, for digital interrupts from the HMI, and send a pulse to the TX and oscilloscope portion of the system. The LEDs will be controlled by the outputs of the microcontroller. The pulse will be timed to be as short as possible, however to ensure accuracy that will feed into a timer circuit to keep the time consistent. Shown in figure 10.

Figure 10: Button interface to system


# 5 EXTERNAL INTERFACES

With the system being self-contained there should be no external interfaces under the scope of the PUD project. The only possible example could be the SD card being extracted from the PUD system and being read by a lab computer. Because of this interaction the PUD will format our data such that MATLAB will be able to read the data from the SD card. Otherwise the power, ultrasonic outputs, and ultrasonic inputs are all self-contained without the PUD system.

## 5.1 Interface Architecture

It is currently unclear regarding the data type the civil engineering lab typically uses when processing ultrasonic concrete scans so the PUD will be changing the output from the microcontroller to match that.

## 5.2 Interface Detailed Design

The data format requirement may come from the civil engineering lab such that it can process the PUD data the same way the lab processed the data they produced. The components will be permanently connected and the data flow will be one direction so there should not be a need for hand-shaking protocols. The current understanding is that any file format that can be imported into MATLAB will be acceptable.

# 6 SYSTEM INTEGRITY CONTROLS

The data collected by the PUD system is not inherently sensitive or private so security is not the highest priority. There will be a physical lock on the PUD outer casing for safety purposes but this will also protect the data the system collects. Physical protection of the device is the responsibility of the user of the system. Verification of the data will come from the lab that analyzes the data so this is not within the scope of the PUD project.

Table 2: electrical components parts list

part number | Part specification and description
1 | 3300 µF 500 V Aluminum Electrolytic Capacitors Radial, Can - Screw Terminals 54mOhm @ 100Hz 20000 Hrs @ 85°C
2 | Enclosed DC DC Converter 1 Output 0 ~ 500V 20mA 13V Input 3838-HighVoltagePowerSupplyAHV12V500V20MAWTB-ND - Tape & Box (TB)
3 | DC 12v 24v to 5v Step Down Converter Regulator 5A 25W Power Adapter Reducer for Car Electronics Truck Vehicle Boat Solar System (Accept DC 8-40V Inputs)
4 | White, Cool 9000K LED Indication - Discrete 3.2V Radial
5 | 5A & 10A 12V Smart Battery Charger with LCD Display for Lead Acid and Lithium (LiFePO4) Batteries
6 | 6AWG (16mm²) 13 Inch Battery Interconnect Cable
7 | LiFePO4 12V 50Ah Lithium Iron Phosphate Battery
8 | Battery Isolator Switch for Car Vehicle RV and Marine (On/Off)
9 | Ancor Marine Grade Primary Wire and Battery Cable
10 | N-Channel 500 V 14A (Tc) 30W (Tc) Through Hole TO-220FP
11 | Starelo 5pcs 19mm Momentary Push Button Switch Black Shell, IP65 Waterproof Push Button Switch,Stainless Steel 1 Normally Open Without LED.
12 | 47 kOhms ±5% 50W Wirewound Chassis Mount Resistor
13 | N-Channel 20 V 6.8A (Ta) 510mW (Ta), 6.94W (Tc) Surface Mount TO-236AB
14 | 390 Ohms ±5% 0.5W, 1/2W Through Hole Resistor Axial Flame Retardant Coating, Safety Carbon Film
15 | 21 Circuit 0.374" (9.50mm) Barrier Block Connector Screws
16 | 5 A 600 V AC 500 V DC Fuse Cartridge, Ceramic Requires Holder 5mm x 20mm
17 | Fuse Block 10 A 600V 1 Circuit Cartridge Chassis Mount
18 | 6.3 A 250 V AC DC Fuse Cartridge, Glass Requires Holder 5mm x 20mm
19 | ANSI Z535 Safety Labels - Hazardous Voltage Inside Hazard labels with strong adhesive backing ideal for rugged use
20 | 50ft - 1/4 inch & 1/2 inch PET Expandable Braided Sleeving – Black – Alex Tech Braided Cable Sleeve
21 | XHF 3/4" Strong Back-Glue Self Adhesive Black Cable Zip Tie Mounts 100pcs with 8" Zip Ties, Screws, UV Protection Outdoor Sticky Wire Fasteners Cable Clips Management Anchors Organizer Holders Squares
22 | Miuzei PCB Board Prototype Kit for Electronic Projects, Circuit Solder Double-Side Board with 40 Pin 2.54 mm Male to Female Headers Connector, 2P&3P Screw Terminal Block, Solder Flux, Solder Wire
23 | 330 Pcs M2 Male Female Brass Hex Spacer Standoffs Screws Nuts, Brass Spacer Hex Column Screw Nut Assortment Kit, Threaded Pillar Standoffs Screws for PCB Circuit Board Motherboard Standoffs Spacer
24 | Breadboard, Surface Mount Plated Surface Mount Pad (Square) 0.100" (2.54mm)
25 | 2.7 kOhms ±5% 120W Wirewound Chassis Mount Resistor
26 | Heat Sink TO-218, TO-220, TO-247 Aluminum 14.0W @ 70°C Board Level, Vertical or Heat Sink TO-220 Aluminum 2.5W @ 50°C Board Level
27 | Belker Universal Laptop Car Charger with USB C for HP Dell Asus Lenovo Samsung MacBook Pro Air Google Chromebook Ultrabook Notebook
28 | VELCRO Brand Extreme Outdoor Mounting Tape | 20Ft x 1 In, Holds 15 lbs | Strong Heavy Duty Stick on Adhesive | Mount on Brick, Concrete for Hanging, 30702
29 | Coolais 5 Pcs Momentary Push Button Switch Metal Waterproof Push Button Start 12mm 3A 250V AC PBSM-01 (Flat Head)
30 | 3M Marine Adhesive Sealant Fast Cure 5200 (05220) Permanent Bonding and Sealing for Boats and RVs Above and Below the Waterline Waterproof Repair, White, 3 fl oz Tube
31 | Temperature Sensor Analog, Local 5°C ~ 100°C 20mV/°C TO-92-3
32 | ASEV30 SERIES 30A DC CONTACTOR Search Alert TSA Approved Travel Combination Luggage Cable Locks for Suitcase, Gym Locker,Toolbox,Backpack 1,2,4,6 &10 pk
33 | E/FUSING 900 Moldable Silicone Putty - Black
34 | 2Pcs Electronic Thermostat Controller W1209 DC 12V Digital Thermostat Waterproof Sensor Temperature Control Switch -50~110°C
35 | TBD
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

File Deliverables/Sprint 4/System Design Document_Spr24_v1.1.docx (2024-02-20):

System Design Document

Dr. Brown Capstone Project Spring ‘24:

Portable Ultrasound Device for Coda-Wave Interferometry

Team members:

Michael Kisellus, Matthew Baker, Layton Foxworthy, Kyle Fox, and Christopher Coppedge

Version | Author | Change | Date
v1.0 | Michael Kisellus, Matthew Baker, Layton Foxworthy, Kyle Fox, and Christopher Coppedge | Initial draft | 1/23/2024
v1.1 | Michael Kisellus | Times new roman text, figure 6,7 update, print format to make more readable, update references, update table of context, table 2 update | 4Feb2023

# TABLE OF CONTENT

1 INTRODUCTION 4

1.1 Purpose and Scope 4

1.2 Project Executive Summary 4

1.2.1 System Overview 4

1.2.2 Design Constraints 6

1.2.3 Future Contingencies 6

1.3 Document Organization 7

1.4 Project References 8

1.5 Glossary 8

2 SYSTEM ARCHITECTURE 8

2.1 System Hardware Architecture 9

2.2 System Software Architecture 11

2.3 Internal Communications Architecture 12

3 HUMAN-MACHINE INTERFACE 12
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

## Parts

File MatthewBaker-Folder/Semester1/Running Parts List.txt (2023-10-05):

L 88+36+36 = 160
W 130
Top section is 114x130mm
Thickness is 0.4mm

Total sq.mm of material is 35,260 which equals approx.  0.3834 sq.ft.

Folding into a channel to form a open-ended rectangular prism consisting of 5052-H32 Aluminum

Fans, 2xOD8025-12HBIP55 12VDC fan
Manufacturer Part#: OD8025-12HBIP55
Digi Key Part#: 	1053-1456-ND
Cost: $15.84/unit, $31.68 total
https://www.digikey.com/en/products/detail/orion-fans/OD8025-12HBIP55/2707577

5052-H32 Aluminum Sheet
2x2' Sheet
Cost @ MetalsDepot.com: $32.36
https://www.metalsdepot.com/aluminum-products/aluminum-sheet

EMC2101 PC Fan controller and temperature sensor (w/STEMMA QT/JST 4pin cable and headers)
Product ID: 4808
Cost: $5.50/unit+0.95 headers+0.95 cables, $14.80 Total
https://www.adafruit.com/product/4808

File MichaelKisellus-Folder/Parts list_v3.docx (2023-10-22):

ALS30A332NP500

Digi-Key Part Number 399-7550-ND

Manufacturer Product Number ALS30A332NP500

CAP ALUM 3300UF 20% 500V SCREW

3300 µF 500 V Aluminum Electrolytic Capacitors Radial, Can - Screw Terminals 54mOhm @ 100Hz 20000 Hrs @ 85°C

https://www.digikey.com/en/products/detail/kemet/ALS30A332NP500/3462159

$88.34

High Voltage Power Supply AHV12V500V20MAW

Enclosed DC DC Converter 1 Output 0 ~ 500V 20mA 13V Input

Digi-Key Part Number(below)

3838-HighVoltagePowerSupplyAHV12V500V20MAWTB-ND - Tape & Box (TB)

https://www.digikey.com/en/products/detail/analog-technologies/High-Voltage-Power-Supply-AHV12V500V20MAW/18621897

$226.90

DC 12v 24v to 5v Step Down Converter Regulator 5A 25W Power Adapter Reducer for Car Electronics Truck Vehicle Boat Solar System (Accept DC 8-40V Inputs)

https://www.amazon.com/Converter-Regulator-Adapter-Reducer-Electronics/dp/B07Q5W1BG3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

12.99

C503C-WAN-CCADB232

LED COOL WHITE CLR 5MM RND T/H

White, Cool 9000K LED Indication - Discrete 3.2V Radial

Digi-Key Part Number(below)

C503C-WAN-CCADB232CT-ND - Cut Tape (CT)

C503C-WAN-CCADB232TB-ND - Tape & Box (TB)

https://www.digikey.com/en/products/detail/creeled,-inc./C503C-WAN-CCADB232/6138556?utm_adgroup=General&utm_source=google&utm_medium=cpc&utm_campaign=PMax%20Shopping_Product_Zombie%20SKUs&utm_term=&utm_content=General&gclid=Cj0KCQjwvL-oBhCxARIsAHkOiu3cTPz6NfGnah6dI9gyCI18RkqZMr3ya9q9RYSoVs7BqKpiX0O5d4UaAkSfEALw_wcB

$2.77 (pack of 10) (x2) = 5.54

5A & 10A 12V Smart Battery Charger with LCD Display for Lead Acid and Lithium (LiFePO4) Batteries

https://www.eco-worthy.com/products/5a-12v-automatic-smart-battery-charger-and-maintainer-with-lcd-display-for-lead-acid-and-lithium-lifepo4-batteries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

$59.99

6AWG (16mm²) 13 Inch Battery Interconnect Cable

https://www.eco-worthy.com/products/6awg-16mm-13-inch-battery-interconnect-cable?variant=34593133625509

$13.63

LiFePO4 12V 50Ah Lithium Iron Phosphate Battery

https://www.eco-worthy.com/products/lifepo4-12v-50ah-lithium-iron-phosphate-battery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

$159.99

Battery Isolator Switch for Car Vehicle RV and Marine (On/Off)

https://www.eco-worthy.com/products/12-48v-battery-isolator-switch-for-car-vehicle-rv-and-marine-on-off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

$18.99 (x2)= 37.98

Ancor Marine Grade Primary Wire and Battery Cable

https://www.amazon.com/Ancor-Marine-Grade-Primary-Battery/dp/B000NV0G0U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

$19.56

STF19NM50N

Digi-Key Part Number 497-12572-5-ND

N-Channel 500 V 14A (Tc) 30W (Tc) Through Hole TO-220FP

https://www.digikey.com/en/products/detail/stmicroelectronics/STF19NM50N/2346299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

$4.61 (x2) = 9.22

Starelo 5pcs 19mm Momentary Push Button Switch Black Shell, IP65 Waterproof Push Button Switch,Stainless Steel 1 Normally Open Without LED.

https://www.amazon.com/Momentary-pre-Wiring-Waterproof-Stainless-Normally/dp/B09BKYC5HL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

14.99

HS50 47K J

Digi-Key Part Number HS5047KJ-ND

RES CHAS MNT 47K OHM 5% 50W

47 kOhms ±5% 50W Wirewound Chassis Mount Resistor

https://www.digikey.com/en/products/detail/ohmite/HS50%252047K%2520J/5307872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

$4.66 (x2)= 9.32

PMV16XNR

Digi-Key Part Number 1727-2300-2-ND - Tape & Reel (TR)

1727-2300-1-ND - Cut Tape (CT)

1727-2300-6-ND - Digi-Reel®

N-Channel 20 V 6.8A (Ta) 510mW (Ta), 6.94W (Tc) Surface Mount TO-236AB

https://www.digikey.com/en/products/detail/nexperia-usa-inc/PMV16XNR/5395791

3.29 (pack of 10) (x2) = 6.58

CF12JT390R

Digi-Key Part Number CF12JT390RTR-ND - Tape & Reel (TR)

CF12JT390RCT-ND - Cut Tape (CT)

390 Ohms ±5% 0.5W, 1/2W Through Hole Resistor Axial Flame Retardant Coating, Safety Carbon Film

https://www.digikey.com/en/products/detail/stackpole-electronics-inc/CF12JT390R/1741140

$0.72 (pack of 10) (x2) = 1.44

2-1546306-1

Digi-Key Part Number A122807-ND

21 Circuit 0.374" (9.50mm) Barrier Block Connector Screws

https://www.digikey.com/en/products/detail/te-connectivity-amp-connectors/2-1546306-1/1136667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

$6.56

0ADKC5000-BE

Digi-Key Part Number 507-2116-ND

5 A 600 V AC 500 V DC Fuse Cartridge, Ceramic Requires Holder 5mm x 20mm

https://www.digikey.com/en/products/detail/bel-fuse-inc/0ADKC5000-BE/7404459

$7.94 (pack of 5)

05200005ZXGY

Digi-Key Part Number F4961-ND

Fuse Block 10 A 600V 1 Circuit Cartridge Chassis Mount

https://www.digikey.com/en/products/detail/littelfuse-inc./05200005ZXGY/554334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

$1.86 (x3) = 5.58

021706.3TXP

Digi-Key Part Number F6053-ND

6.3 A 250 V AC DC Fuse Cartridge, Glass Requires Holder 5mm x 20mm

https://www.digikey.com/en/products/detail/littelfuse-inc./021706.3TXP/3425317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

2.21 (pack of 5)

ANSI Z535 Safety Labels - Hazardous Voltage Inside

Hazard labels with strong adhesive backing ideal for rugged use

https://www.seton.com/ansi-z535-safety-labels-hazardous-voltage-inside-l5476.html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

$20.75

50ft - 1/4 inch & 1/2 inch PET Expandable Braided Sleeving – Black – Alex Tech Braided Cable Sleeve https://www.amazon.com/100ft-Expandable-Braided-Sleeving-Sleeve/dp/B07RZXSJBM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

9.99

XHF 3/4" Strong Back-Glue Self Adhesive Black Cable Zip Tie Mounts 100pcs with 8" Zip Ties, Screws, UV Protection Outdoor Sticky Wire Fasteners Cable Clips Management Anchors Organizer Holders Squares

https://www.amazon.com/XHF-Back-Glue-Protection-Fasteners-Management/dp/B08F77YVYB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

9.99

Miuzei PCB Board Prototype Kit for Electronic Projects, Circuit Solder Double-Side Board with 40 Pin 2.54 mm Male to Female Headers Connector, 2P&3P Screw Terminal Block, Solder Flux, Solder Wire

https://www.amazon.com/Miuzei-Including-Prototype-Connector-Terminal/dp/B07PS4VCDD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

14.99

330 Pcs M2 Male Female Brass Hex Spacer Standoffs Screws Nuts, Brass Spacer Hex Column Screw Nut Assortment Kit, Threaded Pillar Standoffs Screws for PCB Circuit Board Motherboard Standoffs Spacer

https://www.amazon.com/Standoffs-Assortment-Threaded-Circuit-Motherboard/dp/B0BZYTC581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

7.49

SBBSM2106-1

Digi-Key Part Number SBBSM2106-1-ND

Breadboard, Surface Mount Plated Surface Mount Pad (Square) 0.100" (2.54mm)

https://www.digikey.com/en/products/detail/chip-quik-inc./SBBSM2106-1/5978238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

$1.59

TE120B2K7J

Digi-Key Part Number 1712-TE120B2K7J-ND

2.7 kOhms ±5% 120W Wirewound Chassis Mount Resistor

https://www.digikey.com/en/products/detail/te-connectivity-passive-product/TE120B2K7J/14308543

$23.43

Kisellus parts Total cost: 776.99

Other people’s parts

APACHE4800 Weatherproof Protective Case, X-Large, Green

https://www.harborfreight.com/4800-weatherproof-protective-case-x-large-green-56863.html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

$59.99

OD8025-12HBIP55

Digi-Key Part Number 1053-1456-ND

FAN AXIAL 80X25MM 12VDC WIRE

Fan Tubeaxial 12VDC Square - 80mm L x 80mm H Ball 40.0 CFM (1.12m³/min) 2 Wire Leads

https://www.digikey.com/en/products/detail/orion-fans/OD8025-12HBIP55/2707577

$15.84 (x2) = 31.68

Overall Total: 868.66 + shipping

Add

RA-T2X-38E

Digi-Key Part Number RA-T2X-38E-ND

Heat Sink TO-218, TO-220, TO-247 Aluminum 14.0W @ 70°C Board Level, Vertical

https://www.digikey.com/en/products/detail/ohmite/RA-T2X-38E/2416488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

$2 or 25 for 47.43

581002B00000

Digi-Key Part Number HS300-ND

Heat Sink TO-220 Aluminum 2.5W @ 50°C Board Level

https://www.digikey.com/en/products/detail/aavid,-thermal-division-of-boyd-corporation/581002B00000/373776?utm_adgroup=&utm_source=google&utm_medium=cpc&utm_campaign=PMax%20Shopping_Product_Medium%20ROAS%20Categories&utm_term=&utm_content=&utm_id=go_cmp-20223376311_adg-_ad-__dev-c_ext-_prd-373776_sig-CjwKCAjw-KipBhBtEiwAWjgwrBpVUW_Ba5DloGsfzVWSdMukftVtxCo2AZ8gHw13FfPvSo1x5d45YhoCb_sQAvD_BwE&gclid=CjwKCAjw-KipBhBtEiwAWjgwrBpVUW_Ba5DloGsfzVWSdMukftVtxCo2AZ8gHw13FfPvSo1x5d45YhoCb_sQAvD_BwE

2.18 or 25 for 51.72

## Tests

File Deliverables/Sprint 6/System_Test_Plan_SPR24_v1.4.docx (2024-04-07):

System Test Plan

For

Portable Ultrasound Device for Coda-Wave Interferometry

Team member: Michael Kisellus, Matthew Baker, Layton Foxworthy, Kyle Fox, and Christopher Coppedge

Version/Author | Reason and Change/edit | Date
v1.0 Kisellus, Baker, Foxworthy, Fox, and Coppedge | Draft from 1st semester | 21Feb2024
V1.1 Kisellus | Formatting and editing all pages | 22Feb2024
V1.2 Baker | Updated cooling system testing. | 10Mar2024
V1.3 Baker | Feedback from TA, removal of unnecessary cases | 21Mar2024
V1.4 Baker | Combined two cases testing the same thing, corrected missing inputs for tests | 4Apr2024

# Table of Contents

1. Introduction 2

1.1 Purpose 2

1.2 Objectives 2

2. Functional Scope 2

3. Overall Strategy and Approach 2

3.1 Testing Strategy 2

3.2 System Testing Entrance Criteria 4

3.3 Testing Types 4

3.4 Suspension Criteria and Resumption Requirements 9

4. Execution Plan 9

4.1 Execution Plan 9

5. Traceability Matrix & Defect Tracking 16

5.1 Traceability Matrix 16

5.2 Defect Severity Definitions 18

6. Environment 18

6.1 Environment 18

7. Assumptions 18

8. Risks and Contingencies 18

9. Appendices 19

Reference 19

# 1. Introduction

Bridges are vital transportation infrastructure that are used daily by millions of people. Like any constructed work, the material used has a finite lifespan and will degrade as both the effects of nature and its designed purpose act on the bridge. Being able to determine locations of failure points, subsurface cracks, and voids in building materials such as concrete can greatly increase the ability for an engineering team to predict future issues and plan remedial work for a bridge. To assist those engineers, the Portable Ultrasound Device (PUD) was designed. This device can be used in conjunction with ultrasonic transducers to detect anomalies within concrete. The data collected can be used to make future engineering decisions.

## 1.1 Purpose

This document is a test plan for the Portable Ultrasound Device (PUD) Testing, produced by the System Testing team. It describes the testing strategy and approach to testing the team will use to verify that the application meets the established requirements of the client prior to release.

## 1.2 Objectives

- Meets the requirements, specifications, and Client rules.
- Supports the intended clients’ functions and achieves the required standards.
- Satisfies the Entrance Criteria for User Acceptance Testing.
- Complies with electrical safety requirements to ensure operator safety.

# 2. Functional Scope

The scope of the PUD is to utilize an internal electrical system to control and generate high voltage pulses through a piezoelectric transducer to push ultrasound waves through a sample of concrete, capture the resultant sound waves, process them through an internal oscilloscope, and capture the processed signals for analysis by an off-site lab. The PUD will also have an internal cooling system to maintain safe operating conditions for the components, a control system to maintain the testing for 48-72 hours, a software system to produce, capture, and record the pulses created by the system, and a hardware system to allow the engineer to do this with a portable unit that can be carried in one hand and left on-site unattended.

# 3. Overall Strategy and Approach

## 3.1 Testing Strategy

Portable Ultrasound Device System Testing will include testing of all functionalities that are in scope (Section 2) identified. System testing activities will include the testing of new functionalities, modified functionalities, screen level validations, work flows, functionality access, testing of internal & external interfaces.

The following 3.1 sections describe overall how the testing types will be evaluated.

### 3.1.1 Electrical subsystem testing

Test objective: The PUD’s Electrical subsystem works according to the listed requirements presented on the SRS.

Technique: Apply normal operating voltage to parts of the system and verify proper operation using test equipment.

Completion criteria: When all tested components match expected value range from the test case list below in section 4. All failed tests are troubleshot, repaired, and pass retest.

Special considerations: Some tests will involve 500V and require proper electrical safety precautions to test.

### 3.1.2 Cooling subsystem testing

Test objective: The PUD’s Cooling subsystem works according to the listed requirements presented on the SRS.

Technique: After connecting the fan to the controller and the controller to the pico, we assign the fan speed lookup table IAW the controller’s documentation and then expose the controller to controlled temperature changes of approximately ±10C and observe the output fan speed accordingly via a visual inspection and tactile increase in the amount of airflow.

Completion criteria: The fan’s RPMs increase and decrease with exposure to higher and lower ambient temperatures IAW SRS and the EMC2101 specifications.

Special considerations: N/A

### 3.1.3 Data processing subsystem testing

Test objective: The PUD’s Data processing subsystem works according to the listed requirements presented on the SRS.

Technique: Once the receiver section is assembled, a power on and function test will be performed. A test sine wave will be applied to the input and the data will be collected and stored.

Completion criteria: A complete sine wave will be reconstructed from the data collected.

Special considerations: This test should be completed before total assembly. This test should show a complete sine wave with no gaps and with consistent sampling.

### 3.1.4 Transmission/ Reception subsystem testing

Test objective: The PUD’s Transmission/ Reception subsystem works according to the listed requirements presented on the SRS.

Technique: The transmitter will be switched on, powered, and triggered. The receiver will be switched on, powered, and triggered.

Completion criteria: For the TX the transmitter must supply a full 500V signal with a ramp time of under 50ns, and a 2us pulse. RX must receive a signal between 0V and 1V, the signal must be complete in nature.

Special considerations: N/A

### 3.1.5 Control subsystem testing

Test objective: The PUD’s Control subsystem works according to the listed requirements presented on the SRS.

Technique: Apply inputs via the control switches.

Completion criteria: Microcontroller registers the input and can produce the correct, corresponding output.

Special considerations: N/A

### 3.1.6 Exterior casing/mounting subsystem testing

Test objective: The PUD’s Exterior casing/mounting works according to the listed requirements presented on the SRS.

Technique: Apply gradually stronger forces to mounted components. This will build up to a drop test.

Completion criteria: Components do not move, do not disconnect, and are not damaged by the focus applied to them.

### 3.1.7 Overall system functionality testing

Test objective: The PUD system as a whole works according to the listed requirements presented on the SRS.

Technique: Operate the PUD system to verify the unit works as expected for normal operating conditions.

Completion criteria: When all tests are passed from the test case list below in section 4. All failed tests are troubleshot, repaired, and pass retest.

Special considerations: The system is expected to operate outside for the duration of normal testing. But must be monitored to prevent theft or unexpected error.

## 3.2 System Testing Entrance Criteria

To start system testing, certain requirements must be met for testing readiness.

The system must be completely constructed or for the case of subsystems that sub system is complete. For electrical wiring the system is inspected with a fluke/multimeter prior to initial use.

Tests may also be performed to verify individual components operate properly prior to system completion.

## 3.3 Testing Types

### 3.3.1 Electrical subsystem testing

This testing encompasses the requirements for testing related to the operation of the electrical system for the PUD system. The goal of Electrical subsystem testing is to produce a safe, reliable, and requirement satisfying electrical distribution system.

System Requirements Specification, 5.2.3: “The safety lock shall be electrically isolated from any of the high voltage components to prevent shock.”

System Requirements Specification, 5.1.1: “The system shall operate for 48 to 72 hours without recharging the internal battery.”

System Requirements Specification, 6.3: “The electrical distribution system shall not exceed a component's rated limits, as shown in its related datasheet.”

System Requirements Specification, 6.4: “The electrical system shall have no faulty components.”

System Requirements Specification, 6.8: “The electrical system shall have no unintended paths to ground.”

### 3.3.2 Cooling subsystem testing

This testing encompasses the requirements for testing related to the operation of the cooling system for the PUD system. The goal of cooling subsystem testing is to produce a safe, reliable, and requirement satisfying cooling and heat dispersion system.

System Requirements Specification, 4.2.3.1: “The system shall be able to monitor internal temperatures within the unit.”

System Requirements Specification, 4.2.3.2: “The system shall run the cooling fan via pulse-width modulation in accordance with a pre-programmed hysteresis curve”

System Requirements Specification, 4.2.3.3: “The system shall shut down in the event that temperatures cannot be reduced below the danger level.”

### 3.3.3 Data processing subsystem testing

This testing encompasses the requirements for testing related to the operation of the data processing system for the PUD system. The goal of data processing testing is to produce a reliable and requirement satisfying data processing system.

System Requirements Specification, 3.2.6: “The Computer shall send commands to the SD card to record the received signal.”

System Requirements Specification, 3.2.7: “The SD card will store data and be kept in a computer and MATLAB readable format.”

System Requirements Specification, 3.3.2: “Raw data from the receiving transducer shall be sent to SD card by the oscilloscope using .mat format”

System Requirements Specification, 3.4.1: “The Raspberry Pi Pico will use the SPI bus to move data between internal components.”

System Requirements Specification, 4.1.3.4: “The system shall convert the analog signal received from the receiver transducer into a digital signal which can be recorded.”

System Requirements Specification, 4.1.3.5: “The system shall be able to save the data received from the receiving transducer to a SD card.”

System Requirements Specification, 4.1.3.6: “The system shall have greater than or equal to 35 GB of storage space to store test data.”

### 3.3.4 Transmission/ Reception subsystem testing

This testing encompasses the requirements for testing related to the operation of the Transmission/ Reception system for the PUD system. The goal of Transmission/ Reception subsystem testing is to produce a safe, reliable, and requirement satisfying Transmission/ Reception distribution system.

System Requirements Specification, 3.2.5: “The ADC or oscilloscope shall receive inputs from the transducer receiver.”

System Requirements Specification, 3.2.6: “The TX will have a ramp time of under 50ns”

System Requirements Specification, 4.1.3.1: “The electrical system shall produce 500 V 2µsec test pulse.”

### 3.3.5 Control subsystem testing

This testing encompasses the requirements for testing related to the operation of the Control system for the PUD system. The goal of Control subsystem testing is to produce a safe, reliable, and requirement satisfying Control system.

System Requirements Specification, 3.2.1: “The push buttons shall input commands to the Raspberry Pi Pico”

System Requirements Specification, 3.2.2: “The Raspberry Pi Pico shall send a switching signal to the MOSFET to gate the 500v input on and off.”

System Requirements Specification, 3.2.3: “The Raspberry Pi Pico shall send PWM or digital switching signals to the cooling fan to control its speed and on/off status.”

System Requirements Specification, 3.2.4: “The Raspberry Pi Pico shall send commands to the status and alarm LEDs to turn on or off”

System Requirements Specification, 4.1.3.2: “The control system shall be able to gate the test signal on and off within 2µsec”

System Requirements Specification, 4.1.3.3: “The system shall be able to produce 50 test signals with 100µsec interval between the test pulses.”

System Requirements Specification, 4.3.3.2: “The system shall turn power on for the overheated LED on the alarm panel if temperature exceeds or is equal to 125°F for more than 1 min.”

System Requirements Specification, 4.3.3.3: “The system shall shut down if temperature exceeds or is equal to 130°F for more than 30 seconds.”

System Requirements Specification, 4.3.3.4: “The system shall be able to monitor SD card status.”

System Requirements Specification, 4.3.3.4.1: “The system shall power on if no SD card is inserted and flash the “SD Card Full” and “Power” LEDs if the card is not present.”

System Requirements Specification, 4.3.3.4.2: “If no SD card is present, the machine shall not perform the test phase.”

System Requirements Specification, 4.3.3.5: “The system shall turn power on for the SD card full LED on the alarm panel if the SD card is 95% of max storage capacity.”

System Requirements Specification, 4.3.3.6: “The system shall record over the oldest data on the SD card if the error is not corrected.”

System Requirements Specification, 4.3.3.7: “The system shall be able to monitor battery voltage.”

System Requirements Specification, 4.3.3.8: “The system shall turn power on for the low battery LED on the alarm panel if the battery voltage drops to or below 10.5.”

System Requirements Specification, 4.3.3.9: “The system shall turn off the system if battery voltage is below 10V for greater than 1 min.”

### 3.3.6 Exterior casing/mounting subsystem testing

This testing encompasses the requirements for testing related to the Exterior casing/mounting system for the PUD system. The goal of Exterior casing/mounting subsystem testing is to produce a safe, reliable, and requirement satisfying Exterior casing/mounting distribution system.

System Requirements Specification, 4.4.3.1: “SD Card slot shall be protected by an external cover that requires external action to open.”

System Requirements Specification, 4.4.3.2: “SD Card shall contain a locking latch mechanism.”

System Requirements Specification, 4.4.3.3: “SD Card slot shall present an alignment guide to ensure proper insertion.”

System Requirements Specification, 5.2.1: “The system shall have an external safety lock to protect the user from high voltages present within.”

System Requirements Specification, 5.2.2: “The system shall have a warning posted on the outside to alert the user to secure power and wait 5 minutes prior to opening due to risk of shock from high voltage supply and capacitor bank.”

System Requirements Specification, 6.1: “The case shall be able to withstand a fall from 1 ft and protect the contents of the case”

System Requirements Specification, 6.2: “The case shall be water resistant and be able to protect the contents from water penetration from rain”

System Requirements Specification, 6.7: “The electrical system components shall be securely mounted to the casing.”

### 3.3.7 Overall system functionality/PUD testing

This testing encompasses the requirements for testing related to the operation of the PUD system that is not covered by the subsystems. The goal of PUD testing is to produce a safe, reliable, and requirement satisfying system for the client.

Note: This section also contains requirements for any remaining tests

System Requirements Specification, 3.2.8: “A laptop separate from the PUD shall run the MATLAB software required to analyze the raw data.”

System Requirements Specification, 3.3.3: “Laptop using MATLAB shall retrieve data from SD card.”

System Requirements Specification, 3.3.4: “Laptop shall be running Windows 10 or later.”

System Requirements Specification, 3.3.5: “Laptop shall have Thonny and MATLAB installed.”

System Requirements Specification, 5.4.1: “All system components shall be tested prior to installation”

System Requirements Specification, 5.4.2: “The system when fully constructed shall be tested using a test plan.”

System Requirements Specification, 5.4.3: “A parts list shall be provided along with the finished product to the user.”

System Requirements Specification, 5.5.1: “Only personnel who have read the operating manual should operate the equipment.”

## 3.4 Suspension Criteria and Resumption Requirements

This section will specify the criteria that will be used to suspend all or a portion of the testing activities on the items associated with this test plan.

### 3.4.1 Suspension Criteria

Testing will be suspended for a sub system or the whole system if a component within the sub system breaks or is damaged.

Testing will also stop if any team member expresses a concern with safety or believes the system to be unsafe in the testing condition used.

### 3.4.2 Resumption Requirements

After the system is restored to a fully functional and safe state.

Permission to resume testing will be authorized by the team leader.

# 4. Execution Plan

## 4.1 Execution Plan

The execution plan will detail the test cases to be executed. The Execution plan will be put together to ensure that all the requirements are covered. The execution plan will be designed to accommodate some changes, if necessary, if testing is incomplete on any day. All the test cases of the projects under test in this release are arranged in a logical order depending upon their inter dependency.

The test plan for the PUD system is as follows:

### 4.1.1 Electrical subsystem testing (3.1.1)

### 4.1.2 Cooling subsystem testing (3.1.2)

### 4.1.3 Control subsystem testing (3.1.5)

### 4.1.4 Data processing subsystem testing (3.1.3)

### 4.1.5 Exterior casing/mounting subsystem testing (3.3.6)

### 4.1.6 Transmission/ Reception subsystem testing (3.1.4)
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

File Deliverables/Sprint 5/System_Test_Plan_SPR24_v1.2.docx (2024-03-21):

System Test Plan

For

Portable Ultrasound Device for Coda-Wave Interferometry

Team member: Michael Kisellus, Matthew Baker, Layton Foxworthy, Kyle Fox, and Christopher Coppedge

Version/Author | Reason and Change/edit | Date
v1.0 Kisellus, Baker, Foxworthy, Fox, and Coppedge | Draft from 1st semester | 21Feb2024
V1.1 Kisellus | Formatting and editing all pages | 22Feb2024
V1.2 Baker | Updated cooling system testing. | 10Mar2024

# Table of Contents

# 1. Introduction

## 1.1 Purpose

This document is a test plan for the Portable Ultrasound Device (PUD) Testing, produced by the System Testing team. It describes the testing strategy and approach to testing the team will use to verify that the application meets the established requirements of the client prior to release.

## 1.2 Objectives

- Meets the requirements, specifications, and Client rules.
- Supports the intended clients’ functions and achieves the required standards.
- Satisfies the Entrance Criteria for User Acceptance Testing.
- Complies with electrical safety requirements to ensure operator safety.

# 2. Functional Scope

The Modules in the scope of testing for the Portable Ultrasound Device System Testing are mentioned in the document attached in the following path:

1. The system requirement specification (SRS) document:

https://docs.google.com/document/d/16PQ4nDXEOfpaoKCjTae0HhOAPFSO_Tca/edit

2. Section 3.1 of this document.
3. User manual

# 3. Overall Strategy and Approach

## 3.1 Testing Strategy

Portable Ultrasound Device System Testing will include testing of all functionalities that are in scope (Section 2) identified. System testing activities will include the testing of new functionalities, modified functionalities, screen level validations, work flows, functionality access, testing of internal & external interfaces.

The following 3.1 sections describe overall how the testing types will be evaluated.

### 3.1.1 Electrical subsystem testing

Test objective: The PUD’s Electrical subsystem works according to the listed requirements presented on the SRS.

Technique: Apply normal operating voltage to parts of the system and verify proper operation using test equipment.

Completion criteria: When all tested components match expected value range from the test case list below in section 4. All failed tests are troubleshot, repaired, and pass retest.

Special considerations: Some tests will involve 500V and require proper electrical safety precautions to test.

### 3.1.2 Cooling subsystem testing

Test objective: The PUD’s Cooling subsystem works according to the listed requirements presented on the SRS.

Technique: After connecting the fan to the controller and the controller to the pico, we assign the fan speed lookup table IAW the controller’s documentation and then expose the controller to controlled temperature changes of approximately ±10C and observe the output fan speed accordingly via a visual inspection and tactile increase in the amount of airflow.

Completion criteria: The fan’s RPMs increase and decrease with exposure to higher and lower ambient temperatures IAW SRS and the EMC2101 specifications.

Special considerations: N/A

### 3.1.3 Data processing subsystem testing

Test objective: The PUD’s Data processing subsystem works according to the listed requirements presented on the SRS.

Technique: Once the receiver section is assembled, a power on and function test will be performed. A test sine wave will be applied to the input and the data will be collected and stored.

Completion criteria: A complete sine wave will be reconstructed from the data collected.

Special considerations: This test should be completed before total assembly. This test should show a complete sine wave with no gaps and with consistent sampling.

### 3.1.4 Transmission/ Reception subsystem testing

Test objective: The PUD’s Transmission/ Reception subsystem works according to the listed requirements presented on the SRS.

Technique: The transmitter will be switched on, powered, and triggered. The receiver will be switched on, powered, and triggered.

Completion criteria: For the TX the transmitter must supply a full 500V ±5% signal with a ramp time of under 50ns, and a 2us pulse. RX must receive a signal between 0V and 1V, the signal must be complete in nature.

Special considerations: N/A

### 3.1.5 Control subsystem testing

Test objective: The PUD’s Control subsystem works according to the listed requirements presented on the SRS.

Technique: Apply inputs via the control switches.

Completion criteria: Microcontroller registers the input and can produce the correct, corresponding output.

Special considerations: N/A

### 3.1.6 Exterior casing/mounting subsystem testing

Test objective: The PUD’s Exterior casing/mounting works according to the listed requirements presented on the SRS.

Technique: Apply gradually stronger forces to mounted components. This will build up to a drop test.

Completion criteria: Components do not move, do not disconnect, and are not damaged by the focus applied to them.

### 3.1.7 Overall system functionality testing

Test objective: The PUD system as a whole works according to the listed requirements presented on the SRS.

Technique: Operate the PUD system to verify the unit works as expected for normal operating conditions.

Completion criteria: When all tests are passed from the test case list below in section 4. All failed tests are troubleshot, repaired, and pass retest.

Special considerations: The system is expected to operate outside for the duration of normal testing. But must be monitored to prevent theft or unexpected error.

## 3.2 System Testing Entrance Criteria

To start system testing, certain requirements must be met for testing readiness.

The system must be completely constructed or for the case of sub systems that sub system is complete. For electrical wiring the system is inspected with a fluke/multimeter prior to initial use.

Tests may also be preformed to verify individual component operates properly prior to system completion.

## 3.3 Testing Types

### 3.3.1 Electrical subsystem testing

This testing encompasses the requirements for testing related to the operation of the electrical system for the PUD system. The goal of Electrical subsystem testing is to produce a safe, reliable, and requirement satisfying electrical distribution system.

System Requirements Specification, 5.2.3: “The safety lock shall be electrically isolated from any of the high voltage components to prevent shock.”

System Requirements Specification, 5.1.1: “The system shall operate for 48 to 72 hours without recharging the internal battery.”

System Requirements Specification, 6.3: “The electrical distribution system shall not exceed a component's rated limits, as shown in its related datasheet.”

System Requirements Specification, 6.4: “The electrical system shall have no faulty components.”

System Requirements Specification, 6.5: “The electrical system shall produce a 5V, 12V, and 500V DC supply. Within ± 5%”

System Requirements Specification, 6.6: <requirement removed>

System Requirements Specification, 6.8: “The electrical system shall have no unintended paths to ground.”

### 3.3.2 Cooling subsystem testing

This testing encompasses the requirements for testing related to the operation of the cooling system for the PUD system. The goal of cooling subsystem testing is to produce a safe, reliable, and requirement satisfying cooling and heat dispersion system.

System Requirements Specification, 4.2.3.1: “The system shall be able to monitor internal temperatures within the unit.”

System Requirements Specification, 4.2.3.2: “The system shall run the cooling fan via pulse-width modulation in accordance with a pre-programmed hysteresis curve”

System Requirements Specification, 4.2.3.3: “The system shall shut down in the event that temperatures cannot be reduced below the danger level.”

System Requirements Specification, 5.1.2: “The system shall have fans and thermal monitoring to ensure components do not overheat IAW applicable component requirements.”

### 3.3.3 Data processing subsystem testing

This testing encompasses the requirements for testing related to the operation of the data processing system for the PUD system. The goal of data processing testing is to produce a reliable and requirement satisfying data processing system.

System Requirements Specification, 3.2.6: “The Computer shall send commands to the SD card to record the received signal.”

System Requirements Specification, 3.2.7: “The SD card will store data and be kept in a computer and MATLAB readable format.”

System Requirements Specification, 3.3.2: “Raw data from the receiving transducer shall be sent to SD card by the oscilloscope using .mat format”

System Requirements Specification, 3.4.1: “The Raspberry Pi Pico will use the SPI bus to move data between internal components.”

System Requirements Specification, 4.1.3.4: “The system shall convert the analog signal received from the receiver transducer into a digital signal which can be recorded.”

System Requirements Specification, 4.1.3.5: “The system shall be able to save the data received from the receiving transducer to a SD card.”

System Requirements Specification, 4.1.3.6: “The system shall have greater than or equal to 35 GB of storage space to store test data.”

### 3.3.4 Transmission/ Reception subsystem testing

This testing encompasses the requirements for testing related to the operation of the Transmission/ Reception system for the PUD system. The goal of Transmission/ Reception subsystem testing is to produce a safe, reliable, and requirement satisfying Transmission/ Reception distribution system.

System Requirements Specification, 3.2.5: “The ADC or oscilloscope shall receive inputs from the transducer receiver.”

System Requirements Specification, 3.2.6: “The TX will have a ramp time of under 50ns”

System Requirements Specification, 4.1.3.1: “The electrical system shall produce 500 V ±5% 2µsec test pulse.”

### 3.3.5 Control subsystem testing

This testing encompasses the requirements for testing related to the operation of the Control system for the PUD system. The goal of Control subsystem testing is to produce a safe, reliable, and requirement satisfying Control system.

System Requirements Specification, 3.2.1: “The push buttons shall input commands to the Raspberry Pi Pico”

System Requirements Specification, 3.2.2: “The Raspberry Pi Pico shall send a switching signal to the MOSFET to gate the 500v input on and off.”

System Requirements Specification, 3.2.3: “The Raspberry Pi Pico shall send PWM or digital switching signals to the cooling fan to control its speed and on/off status.”

System Requirements Specification, 3.2.4: “The Raspberry Pi Pico shall send commands to the status and alarm LEDs to turn on or off”

System Requirements Specification, 3.3.1: <removed>

System Requirements Specification, 3.4.2: <removed>

System Requirements Specification, 4.1.3.2: “The control system shall be able to gate the test signal on and off within 2µsec (MOSFET) ”

System Requirements Specification, 4.1.3.3: “The system shall be able to produce 50 test signals with 100µsec interval between the test pulses.”

System Requirements Specification, 4.3.3.2: “The system shall turn power on for the overheated LED on the alarm panel if temperature exceeds or is equal to 125°F for more than 1 min.”

System Requirements Specification, 4.3.3.3: “The system shall shut down if temperature exceeds or is equal to 130°F for more than 30 seconds.”

System Requirements Specification, 4.3.3.4: “The system shall be able to monitor SD card status.”

System Requirements Specification, 4.3.3.4.1: “The system shall power on if no SD card is inserted and flash the “SD Card Full” and “Power” LEDs if the card is not present.”

System Requirements Specification, 4.3.3.4.2: “If no SD card is present, the machine shall not perform the test phase.”

System Requirements Specification, 4.3.3.5: “The system shall turn power on for the SD card full LED on the alarm panel if the SD card is 95% of max storage capacity.”

System Requirements Specification, 4.3.3.6: “The system shall record over the oldest data on the SD card if the error is not corrected.”

System Requirements Specification, 4.3.3.7: “The system shall be able to monitor battery voltage.”

System Requirements Specification, 4.3.3.8: “The system shall turn power on for the low battery LED on the alarm panel if the battery voltage drops to or below 10.5.”

System Requirements Specification, 4.3.3.9: “The system shall turn off the system if battery voltage is below 10V for greater than 1 min.”

### 3.3.6 Exterior casing/mounting subsystem testing

This testing encompasses the requirements for testing related to the Exterior casing/mounting system for the PUD system. The goal of Exterior casing/mounting subsystem testing is to produce a safe, reliable, and requirement satisfying Exterior casing/mounting distribution system.

System Requirements Specification, 4.4.3.1: “SD Card slot shall be protected by an external cover that requires external action to open.”

System Requirements Specification, 4.4.3.2: “SD Card shall contain a locking latch mechanism.”

System Requirements Specification, 4.4.3.3: “SD Card slot shall present an alignment guide to ensure proper insertion.”

System Requirements Specification, 5.2.1: “The system shall have an external safety lock to protect the user from high voltages present within.”

System Requirements Specification, 5.2.2: “The system shall have a warning posted on the outside to alert the user to secure power and wait 5 minutes prior to opening due to risk of shock from high voltage supply and capacitor bank.”

System Requirements Specification, 6.1: “The case shall be able to withstand a fall from 1 ft and protect the contents of the case”

System Requirements Specification, 6.2: “The case shall be water resistant and be able to protect the contents from water penetration from rain”

System Requirements Specification, 6.7: “The electrical system components shall be securely mounted to the casing.”

### 3.3.7 Overall system functionality/PUD testing

This testing encompasses the requirements for testing related to the operation of the PUD system that is not covered by the subsystems. The goal of PUD testing is to produce a safe, reliable, and requirement satisfying system for the client.

Note: This section also contains requirements for any remaining tests

System Requirements Specification, 3.2.8: “A laptop separate from the PUD shall run the MATLAB software required to analyze the raw data.”

System Requirements Specification, 3.3.3: “Laptop using MATLAB shall retrieve data from SD card.”

System Requirements Specification, 3.3.4: “Laptop shall be running Windows 10 or later.”

System Requirements Specification, 3.3.5: “Laptop shall have Thonny and MATLAB installed.”

System Requirements Specification, 5.4.1: “All system components shall be tested prior to installation”

System Requirements Specification, 5.4.2: “The system when fully constructed shall be tested using a test plan.”

System Requirements Specification, 5.4.3: “A parts list shall be provided along with the finished product to the user.”

System Requirements Specification, 5.5.1: “Only personnel who have read the operating manual should operate the equipment.”

## 3.4 Suspension Criteria and Resumption Requirements

This section will specify the criteria that will be used to suspend all or a portion of the testing activities on the items associated with this test plan.

### 3.4.1 Suspension Criteria

Testing will be suspended for a sub system or the whole system if a component within the sub system breaks or is damaged.

Testing will also stop if any team member expresses a concern with safety or believes the system to be unsafe in the testing condition used.

### 3.4.2 Resumption Requirements

After the system is restored to a fully functional and safe state.

Permission to resume testing will be authorized by the team leader.

# 4. Execution Plan

## 4.1 Execution Plan

The execution plan will detail the test cases to be executed. The Execution plan will be put together to ensure that all the requirements are covered. The execution plan will be designed to accommodate some changes, if necessary, if testing is incomplete on any day. All the test cases of the projects under test in this release are arranged in a logical order depending upon their inter dependency.

The test plan for the PUD system is as follows:

### 4.1.1 Electrical subsystem testing (3.1.1)

### 4.1.2 Cooling subsystem testing (3.1.2)

### 4.1.3 Control subsystem testing (3.1.5)

### 4.1.4 Data processing subsystem testing (3.1.3)

### 4.1.5 Exterior casing/mounting subsystem testing (3.3.6)

### 4.1.6 Transmission/ Reception subsystem testing (3.1.4)
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

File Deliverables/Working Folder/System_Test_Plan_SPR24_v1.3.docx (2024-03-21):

System Test Plan

For

Portable Ultrasound Device for Coda-Wave Interferometry

Team member: Michael Kisellus, Matthew Baker, Layton Foxworthy, Kyle Fox, and Christopher Coppedge

Version/Author | Reason and Change/edit | Date
v1.0 Kisellus, Baker, Foxworthy, Fox, and Coppedge | Draft from 1st semester | 21Feb2024
V1.1 Kisellus | Formatting and editing all pages | 22Feb2024
V1.2 Baker | Updated cooling system testing. | 10Mar2024
V1.3 Baker | Feedback from TA, removal of unnecessary cases | 21Mar2024

# Table of Contents

# 1. Introduction

Bridges are vital transportation infrastructure that are used daily by millions of people. Like any constructed work, the material used has a finite lifespan and will degrade as both the effects of nature and its designed purpose act on the bridge. Being able to determine locations of failure points, subsurface cracks, and voids in building materials such as concrete can greatly increase the ability for an engineering team to predict future issues and plan remedial work for a bridge. To assist those engineers, the Portable Ultrasound Device (PUD) was designed. This device can be used in conjunction with ultrasonic transducers to detect anomalies within concrete. The data collected can be used to make future engineering decisions.

## 1.1 Purpose

This document is a test plan for the Portable Ultrasound Device (PUD) Testing, produced by the System Testing team. It describes the testing strategy and approach to testing the team will use to verify that the application meets the established requirements of the client prior to release.

## 1.2 Objectives

- Meets the requirements, specifications, and Client rules.
- Supports the intended clients’ functions and achieves the required standards.
- Satisfies the Entrance Criteria for User Acceptance Testing.
- Complies with electrical safety requirements to ensure operator safety.

# 2. Functional Scope

The scope of the PUD is to utilize an internal electrical system to control and generate high voltage pulses through a piezoelectric transducer to push ultrasound waves through a sample of concrete, capture the resultant sound waves, process them through an internal oscilloscope, and capture the processed signals for analysis by an off-site lab. The PUD will also have an internal cooling system to maintain safe operating conditions for the components, a control system to maintain the testing for 48-72 hours, a software system to produce, capture, and record the pulses created by the system, and a hardware system to allow the engineer to do this with a portable unit that can be carried in one hand and left on-site unattended.

# 3. Overall Strategy and Approach

## 3.1 Testing Strategy

Portable Ultrasound Device System Testing will include testing of all functionalities that are in scope (Section 2) identified. System testing activities will include the testing of new functionalities, modified functionalities, screen level validations, work flows, functionality access, testing of internal & external interfaces.

The following 3.1 sections describe overall how the testing types will be evaluated.

### 3.1.1 Electrical subsystem testing

Test objective: The PUD’s Electrical subsystem works according to the listed requirements presented on the SRS.

Technique: Apply normal operating voltage to parts of the system and verify proper operation using test equipment.

Completion criteria: When all tested components match expected value range from the test case list below in section 4. All failed tests are troubleshot, repaired, and pass retest.

Special considerations: Some tests will involve 500V and require proper electrical safety precautions to test.

### 3.1.2 Cooling subsystem testing

Test objective: The PUD’s Cooling subsystem works according to the listed requirements presented on the SRS.

Technique: After connecting the fan to the controller and the controller to the pico, we assign the fan speed lookup table IAW the controller’s documentation and then expose the controller to controlled temperature changes of approximately ±10C and observe the output fan speed accordingly via a visual inspection and tactile increase in the amount of airflow.

Completion criteria: The fan’s RPMs increase and decrease with exposure to higher and lower ambient temperatures IAW SRS and the EMC2101 specifications.

Special considerations: N/A
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

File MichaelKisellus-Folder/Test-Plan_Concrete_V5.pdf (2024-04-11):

# System Test Plan

# For

# Portable Ultrasound Device for Coda-Wave Interferometry

Team member: Michael Kisellus, Matthew Baker, Layton Foxworthy, Kyle Fox, and Christopher Coppedge

Version/Author | Reason and Change/edit | Date
v1.0 Kisellus, Baker, Foxworthy, Fox, and Coppedge | Draft from 1st semester | 21Feb2024
V1.1 Kisellus | Formatting and editing all pages | 22Feb2024
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

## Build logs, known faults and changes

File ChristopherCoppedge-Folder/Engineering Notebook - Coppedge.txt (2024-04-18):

9/14/23 - Elected scrum master, organized information, coordinated a meeting with Dr. Brown, and we set up our Github.

9/15/23 - Met with Dr. Brown to discuss the system requirements and operation. Team meeting to discuss basic ideas and get ready for our next meeting Tuesday.

9/19/23 - In class meeting to discuss our requirements, backlog, and vision statement. We also divided the tasks between the team members. I am in charge of the casing and have begun researching capable cases we can use.

9/21/23 - In class meeting in which we reviewed the progress we made on our respective tasks. I am in charge of the SDD which is due the 19th. Added the template to the github as a base for our SDD.

9/26/23 - In class meeting where we reviewed our progress on our respective tasks. This included ensuring everyone's ideas would meet the requirements and functionality we need. Then we started working on our respective tasks which for me was the SDD.

9/28/23 - Worked on the SDD. Then we had an in-class meeting discussing our progress on our respective tasks. We then all started to work on the SDD and SRS as the first version of those documents are due tomorrow. 

10/3/23 - Team meeting and coordination of the sprint 1 presentation. I created the background section of the presentation and made the drive that will house our shared documents.

10/5/23 - Presentation of the sprint 1 progress. Also arranging the components in CAD.

10/10/23 - Prototyped the case layout in solidworks.

10/12/23 - In class meeting in which we discussed the option of using the lab osciliscope within our system. This would simplify the data collection side of the project.

10/17/23 - In class meeting where we discussed and worked on the test plan that is due the 18th.

10/18/23 - Worked on the test plan to help ensure it is ready for submission.

10/22/23 - Helped develop the SRS.

10/24/23 - Working on Tax exempt purchases. Made some additions to the SDD.

10/26/23 - In class meeting - Went to the SGA to pick up the tax exempt paperwork - Helped compile individual parts lists into a single master list. Sent out emails to parts supplier to get recognition of tax exempt status.

10/31/23 - In class meeting - Worked on SDD and SRS. Also sent follow up emails to digikey and eco-worthy to see if there are any updates to our attempt to get tax-exempt status. Also worked on sprint 2 demo presentation.

11/2/23 - Presented sprint 2 demo, no updates to getting tax-exempt status with any supplier other than Amazon.

11/3/23 - DigiKey replied that our account has been marked as text exempt.

11/7/23 - Ordered digi-key parts from our list and made sure the receipt gets to Dr. Brown.

11/9/23 - Reviewing parts list and ensuring components are suitable for the application. Started picking out an embedded pc to collect data from the osciliscope.

11/14/23 - Class meeting and we continued to find and order parts necessary to the building of our prototype. 

11/16/23 - Team meeting to discuss what to do next. Also first round of parts have arrived so we began to test them to ensure they are functional and ready to be put into our first prototype.

11/21/23 - Class meeting, multiple boxes arrived so we discussed work to do over the break. Also distributed parts for verification. We have begun to work on sprint 3 presentation.

11/23/23 - More parts arrived, reviewed the presentation to see what it needs.

11/28/23 - Delivered parts to school and met in class.Discussed how to move forward with our project and ordered the last parts we'll need for this semester.

11/30/23 - Presentations began and I worked on finalizing our presentation. 

12/5/23 - Recieved more parts and delivered them to Michael so he can test them over the break.

12/6/23 - Working on our 3 minute video and reviewing our presenation before we present.

12/7/23 - Presented our project in the class time.

------ Spring '24 -----

1/11/24 - First day of class, met in the IC and talked about changes to the class format.

1/16/24 - Class meeting to ensure that all the work we wish to complete this semester is on GitHub. Confirm that everyone has tasks to work on. We talked about the next steps we will make to progress with our project.

1/18/24 - Class meeting in which we met with a professor and then went to our lab to plan where we will drill our case to mount hardware.

1/23/24 - In class meeting, began drilling our case and prototyping case layouts. We also realized we need more items from Amazon and digikey so I ordered them and uploaded the receipts.

1/25/24 - Meeting in which we worked on our product vision and backlog. We also identified more items we need from Amazon so I started the process of ordering them.

1/30/24 - Identified more parts we may need. Also worked on the SDD and SRS to make them reflect the progress we have made in our project.

2/1/24 - Began working on the sprint presentation. Added the progress we have made in building our physical device.

2/6/24 - Preparing for our sprint presenation. Still working on our building the device and finalizing the component positions.

2/8/24 - Sprint presentation but I was unable to attend due to a work trip.

2/13/24 - In class meeting in which we talked to the TA's about our roles and progress. We also discussed the idea of getting our project ready to be handed off if we are not able to complete it before the end of the semester. Worked on adding up our orders and renewing our amazon tax exempt status.

2/15/24 - Chose a new scrum master to reflect a change in direction of the project from hardware to software. This was done during an in class meeting where we worked on testing some circuits and worked towards getting the osciliscope controllable via python.

2/20/24 - In class meeting in which we charged the battery to ensure it was functioning correctly. I brought in parts that arrived over the weekend and we figured out how to control the osciliscope from Python.

2/22/24 - Spent the in class meeting editing the SRS based on feedback from the TA.

2/27/24 - Also spent the in class meeting editing the SRS based on feedback from the TA.

2/29/24 - Continued to correct SRS and SDD based on TA feedback.

3/5/24 - Looked to clean up the wiring in the PUD and continued to work on SRS and SDD.

3/7/24 - Looked to clean up the wiring in the PUD and continued to work on SRS and SDD.

3/19/24 - Boeing meeting.

3/24/24 - In class meeting where we talked to the professors and I worked on paperwork.

3/26/24 - In class meeting where we applied sealant to our product and worked on the SRS and SDD.

3/29/24 - Met in class and applied sealent to the PUD. Worked on revising the SRS and SDD.

4/2/24 - Working on the SDD in a class meeting.

4/4/24 - Made final edits to the test plan during an in class meeting.

4/9/24 - Met in class to discuss what is needed to progress with the project. Reviewed the SRS and SDD, then created a Github issue to document the paperwork review.\

4/11/24 - In class meeting in which we talked to the professors about our progress and presenting to an IEEE event. Also reviewed the SRS and SDD.

4/16/24 - Reviewed documentation and worked on the sprint presentation.

4/18/24 - In class meeting where we went over the presentation, updated slides, and reviewed documentation.

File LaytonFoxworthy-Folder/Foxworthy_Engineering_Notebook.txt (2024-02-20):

20230912-
	-Meet with assigned group for first time 
	-Read over project details begin to think about what part i want to tackle
	-We made a github
20230914-
	-Worked on Organizing Github
	-Michael emailed Brown about project
	-Created Discord group
	-Michael chosen as Scrum Leader
20230919-
	-Met with Dr. Brown to see what they already have
	-chose area of focus for each member (code for me)
	-Preliminary Parts list
20230921-
	-Began researching ways to take in raw data and make it usable
	-Maybe could just be microcomputer 
20230926-
	- Meeting on friday with Dr. Brown
	- Continuing to research ways to convert raw data to usable form
	- Straying away from Microcomputer to ADC system instead
20230928-
	-Starting to compile information for sprint 1 presentation
	-Read fourms with other people who have attempted to do similar projects
	 using ADC - not looking great
	-Looking at commercial products designed for specifically what i need they're
	 all very expensive.
20231003-
	-looked over project documents added anything i needed to add for code
	-Tried to obtain file of raw data to see what im working with but the 
	 system they currently use pre formats the data so its pretty useless
20231005-
	Sprint 1 Presentation
20231010-
	-Career Fair
20231012-
	-Continue to research easiest way to accomplish purpose of device
	-examine electrical system schematic to see what needs to be implimented in 
	 addition to ADC seems pretty straightforward
20231017-
	-Went over test plan with everyone
	-Explained the issue with collecting raw data and trying to format it
20231019-
	-Explained how i thought essentially creating an osciloscope from nothing 
	 was going to be a essentially impossible task for me to accomplish to TA 
	 he agreed
20231024-
	-Talked to Dr.Brown about the possibility of using his osciloscope for project
	 he was fine with that
20231026- 
	-Discussed with group new direction for software side of things discussed
	 ways to run osciloscope in PUD maybe a small computer running windows would
	 work
20231031-
	-Worked on Sprint 2 presentation etc.
20231102-
	-Sprint 2 demo
20231107-
	- Started messing around with picoscope software
	- Settings file Dr.Brown provided doesnt seem to be working
	- Also picoscope doesnt record data correctly 
20231109-
	-Figured out i was using a newer version of picoscope software downloaded
	 older version still isnt recording data correctly
20231114-
	-Got picoscope to record correctly by manually setting my own settings
	 will have to see if these settings work for actual testing but for now its 
	 fine for just messing around with
20231116-
	-started messing around with python code to run picoscope automatically
	 some success but i need to see how it runs on actual unit that will be in box
	 exception handling may be an issue
20231121-
	-Not in class
20231128-
	-Continued to mess around with scripts 
20231130-
	-started messing around with pi pico to see how i can impliment different
	 light scripts. Pretty straight forward low power might be a challenge due
	 to pico only accepting up to 3.3V
20231205-
	writing code for pico to demonstrate some basic functionality 
20240116-
	First meeting with team discussed backlog and product status etc.
20240117-
	Met with Dr.Brown to discuss state of progress etc.
20240118-
	Set up new computer downloaded all the software we need went through basic startup
20240123-
	Worked on testing ADC onboard pico demonstrated ability to take analog input and convert it to a digital variable
20240125-
	Not in class
20240129-
	Worked with component provided by Michael to test ability of pico to gate MOSFET on and off
20240202-
	Began to code logic into pico test code to turn indicator lights on and off depending on state of the code
20240208-
	Sprint 1 demo
20240215-
	Worked on trying to get picoSDK commands to work on Python using command wraps this was 
	unsuccessful will need to continue to work on this next week.

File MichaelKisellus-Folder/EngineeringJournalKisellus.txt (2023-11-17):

26Aug-7Sep
•	Review and apply for projects
•	Review scrum
•	Review documentation requirements
12Sep
•	Assigned a project with group 8 (Portable Ultrasound Device for Coda-Wave Interferometry)
•	Familiarize myself with the team members
•	Discuss project with team
•	Read over project details
•	Create GitHub
14Sep
•	Establish communication with team (discord)
•	Link GitHub accounts and review GitHub operation with team 
•	Establish communication with client (Professor Brown) through email
•	Set up meeting with client to review the project and establish the projects requirements.
•	Draft generic project vision and backlog based on provided information (final copy will be produced after meeting with client)
•	Chose scrum leader through vote (Kisellus)
15Sep 
•	Meet with the client and confirmed project scope and requirements. 
•	Completed draft for product vision and product backlog.
19Sep
•	 Ask teacher if budget comes purely from client.
•	 Confirm with team that the product vision and backlog are correct. Modify as required.
•	 Rank tasks by importance and determine which team members are best suited to each task.
•	 Delegate tasks to begin work/design/research.
•	 Start getting a parts list to estimate price. (Estimated 2-week completion for estimate)
•	 Create project backlog through the issue system and assign tasks. 
21Sep
•	Work on design for electrical system (Lithium-ion batteries chosen)
•	Correct vision statement
•	Correct the backlog and add sprint designations
26sep
•	Note: a lot of work done this weekend. Draft of electrical system, draft of front panel, list of parts, capacitor size calculation, SDS drafted.
•	Discuss project status
•	Assign personal to SDD and SRS, placed on google drive for editing
•	Schedule meeting with client for Friday at 1300 for status update and technical questions.
28sep
•	SDD and SRS document work
29sep
•	Meeting with client
•	Verify pulse shape
(2microsecond pulse wait and record for 100 microseconds then repeat 50 times)
•	Request to audit parts list prior to approval
•	Possible expansion to multiple sensors in the future (possibly next semester)
1oct
•	Audit parts list and reconfirm calculations.
3oct
•	Sprint power point presentation draft.
•	Schedule meeting with client to retrieve test equipment.
5oct
•	Sprint power point presentation
6oct
•	Speak with client and verify parts list. (start purchase process)
•	Obtain test equipment
10oct
•	No Class: career fair.
12Oct
•	Modify electrical schematic.
•	Speak to TA and professor for the majority of the class. To identify weak points.
14Oct
•	Draft test plan
•	Run simulation on LTspice to verify capacitor behavior.
15Oct
•	Draft test plan (15 pages)
17Oct
•	Review test plan with team
•	Discuss solutions to sampling/data problem
•	Revise SDD
20Oct 
•	Revise SDD based on feedback from TA
21Oct 
•	Revise SDD based on feedback from TA
24Oct
•	Revise SRS
27Oct
•	Sprint_v2 draft
31Oct 
•	Review parts list, produce alternatives if Digi key tax free status does not occur.
1Nov
•	Sprint 2 presentation.
7Nov
•	Order parts
•	Convert some parts to tax free websites. Client requires tax free.
9Nov
•	Verify parts ordered using correct product code and correct quantity.
14Nov
•	Verify components values match expectation/ test parts individually.
16Nov to 19 Nov
•	Begin soldering components/ assemble electrical circuits.
•	Verify electrical circuits function correctly.

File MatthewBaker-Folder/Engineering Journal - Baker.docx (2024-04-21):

Matthew Baker

Engineering Journal

Senior Design Capstone II – Spring 2024 Semester

Date: 01/16/24

Type of Meeting: Class

Present? Yes

Discussion: Initial get together and update of TA. Researched proper connections to run arduino to program EMC2101 fan controllers.

Date: 01/18/24

Type of Meeting: Class

Present? Yes

Discussion: Discussed division of labor further, began work on wiring and pinouts of EMC2101 fan controllers.

Date: 01/23/24

Type of Meeting: Class

Present? Yes

Discussion: Received soldered pin version and completed programming of EMC2101 controllers. Received prototype of 3D printed external ventilation covers, gave relevant feedback to Kisellus for revisions to aid in connection to fan.

Date: 01/25/24

Type of Meeting: Class

Present? No

Discussion: Absent due to medical appointment. Researched best methods for creating driver boards to house EMC2101 controllers.

Date: 01/30/24

Type of Meeting: Class

Present? Yes

Discussion: Worked on basic driver board layout for controller boards with leads for connections to fan, Rpi, etc. Added diodes and screws to part list.

Date: 01/31/24

Type of Meeting: N/A

Discussion: Completed materials testing of vent covers vis-a-vis screw thread tolerances.

Date: 02/01/24

Type of Meeting: Class

Present? No, due to disability

Discussion: Pushed v1 of SDD/SRS to GitHub Repo.

Date: 02/02/24

Type of Meeting: N/A

Discussion: Added updates to Sprint 1 Demo slides

Date: 02/06/24

Type of Meeting: Class

Members Present: All

Discussion: Found fan covers online to alleviate need for 3d printing.

Date: 02/08/24

Type of Meeting: Class

Members Present: All

Discussion: Sprint 1 presentation

Date: 02/11/24-2/17/24

Quarantined due to COVID

Date: 02/22/24

Type of Meeting: Class

Members Present: All

Discussion: Started process of prepping purchased fan covers for case, waiting on tools to make adjustments for left side cover and widening screw holes for installation. Found mesh material for covering inside of fans to prevent wiring damage

Date: 02/27/24

Type of Meeting: Class

Discussion: Made modifications to left-side fan cover to fit around latch, attached cover baseplates to both sides and made initial mounting for right-side internal fan. Awaiting screen mesh for internal side of fans to prevent wiring damage before finishing installations.

Date: 02/29/24

Type of Meeting: Class

Discussion: Did initial work on Sprint 2 Demo, not in class due to disability.

Date: 03/06/24

Type of Meeting: Class

Discussion: Finished my portion of sprint 2 demo.

Date: 03/08/24

Type of Meeting: Class

Discussion: Sprint 2 Presentation.

Date: 03/19/24

Type of Meeting: Class

Discussion: Cut mesh for internal fan coverings.

Date: 03/21/24

Type of Meeting: Class

Discussion: Unable to attend class due to disability appointment issues, implemented TA feedback into latest version of SRS, SDD, and Test Plan.

Date 3/26/24

Type of Meeting: Class

Discussion: Applied marine sealant to all external penetrations with exception of those sealed by putty, attempted to seal poorly installed fan cover, will fill with putty once dry.

Date 4/4/24

Discussion: Finalized updates to test plan, ensuring no missing inputs for test cases and combining redundant test cases. Final test for cooling system is marked Fail due to lack of fourth lead from obtained fans. Michael is working on a manual cut-off solution.

Date 4/7/24

Did final proofreading pass on test plan alongside Chris C, turned in same. Started work on getting SRS & SDD tuned and ready for turn-in. Completed personal section of backlog summary.

Date 4/11/24

Updated SDD to match TA feedback

Date 4/18/24

Updated final demo portion.

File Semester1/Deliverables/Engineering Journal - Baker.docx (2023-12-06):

Matthew Baker

Engineering Journal

Senior Design Capstone I – Fall 2023 Semester

Date: 9/14/23

Type of Meeting: Class

Present? Yes

Discussion: Selected Scrum Master (Michael Kisellus), presented with general, “starter” vision and backlog document, discussed basics of type of device and purposes. Set up team meeting with Dr. Brown for Friday (9/15/23) to discuss backlog and vision document as well as any materials and documentation from previous design groups. Setup GitHub repo and discord server communications as well as event invitation setup. I volunteered to handle documentation collation, editing, and processing.

Date: 9/15/23

Type of Meeting: Meeting w/ Product Owner

Present? No

Discussion: I was absent during this meeting due to a family emergency, however the group assured me that all details would be placed on the Discord and shared with me.

Addendum: Product backlog posted as ‘Issues’ in the GitHub repo.

Date: 9/19/23

Type of Meeting: Class

Present? Yes

Discussion: Received draft of backlog from Scrum Master, instructed to prioritize the backlog as to completion time and necessity for the system overall, completed same. I volunteered to be the main editor and collator for the different design and requirements documentations as well as assisting in the case design in terms of the cooling system of the unit. Also reviewed the nature of the SRS and SDD with the Scrum Master.

Date: 9/21/23

Type of Meeting: Class

Present? Yes, remotely

Discussion: Created a mock-up for the cooling system in FreeCAD, utilizing a piece of sheet metal attached to a pre-fabricated 80mm heatsink and fan (PDF exported image pushed to repo). Working on a more involved design involving a heatsink designed to extend outside the case.

Date: 9/26/23

Type of Meeting: Class

Members Present: All

Discussion: Scrum Master presented us with what was needed for SRS and SDD, including detail work and parts lists for all components. Each member came in with their needs and ideas for what we are working on. Dimensions of parts and data sheets shared amongst the group. SRS and SDD opened on Google Docs for ease of editing.

90% Completed mockup of cooling system in FreeCAD, added cooling system section to SDD, changed cooling system design to a intake-exhaust tunnel design using sheet aluminum and the chosen fans.

Date: 9/28/23

Type of Meeting: Class

Members Present: All

Discussion: Follow up on previous meeting, ensuring that we are on target for completion of SRS and SDD.

Completed temperature-fan curve chart and added to SDD. Updated parts list to include fan controllers to track multiple thermal zones within the unit/case.

Date: 9/29/23

Type of Meeting: Remote

Members Present: All

Discussion: Perfomed editing pass and proofread of SRS and SDD deliverables once all sections were completed by the team, uploaded same to GitHub and submitted links to Canvas.

Date: 10/3/23

Type of Meeting: Class

Members Present: All

Discussion: Update on changes to design, informed that we need to take a group photo. Began work on first demo presentation as well as shoring up our diagrams. Uploaded sample data file from client to Repo.

Date: 10/5/23

Type of Meeting: Class

Members Present: All

Discussion: Gave Sprint 1 Demo, received feedback

Date: 10/10/23

Type of Meeting: Class

Members Present: All

Discussion: Continued work on refining design, identified what was and was not working and made plans to gather equipment from client.

Date: 10/12/23

Type of Meeting: Class

Members Present: All

Discussion: Discussed product scope with TA, made appointment to meet with client on 10/18 @ 1300 to discuss project goals and potential pivot to using existing modules rather than building from scratch. Began work on test plan.

Date: 10/17/23

Type of Meeting: Class

Members Present: All

Discussion: Discussed test plan with TA and SDD changes/revisions. Discussed need to sit down with client and understand how the test procedure works with the lab equipment and to request any potential documentation.

Date: 10/19/23

Type of Meeting: Class

Members Present: All

Discussion: Plans for revisions of SRS/SDD, analysis of existing lab equipment.

Date: 10/24/23

Type of Meeting: Class

Not Present

Discussion: Not present due to issues related to my disability

Date: 10/26/23

Type of Meeting: Class

Members Present: All

Discussion: Discussed upcoming SRS/SDD revision completion and Sprint Demo 2, changed design of cooling system to remove need for 3d printed fan shrouds, instead using aluminum to enclose and direct airflow. Also created mockup for capacitor mounting frame.

Date: 10/31/23 & 11/2

Type of Meeting: Class

Myself not present due to son’s surgery, updated my portion of Sprint 2 Demo with updated aluminum shroud for unit.

Date: 11/7/23

Type of Meeting: Class

Members Present: All

Discussion: Updating on current situation. My system unchanged.

Date: 11/19/23

Resolved Cooling System Issue on GitHub Repo.

Date: 11/28/23

Initiated RMA on cooling fans as they run purely on DC and do not provide a speed sensor feedback to the controller.

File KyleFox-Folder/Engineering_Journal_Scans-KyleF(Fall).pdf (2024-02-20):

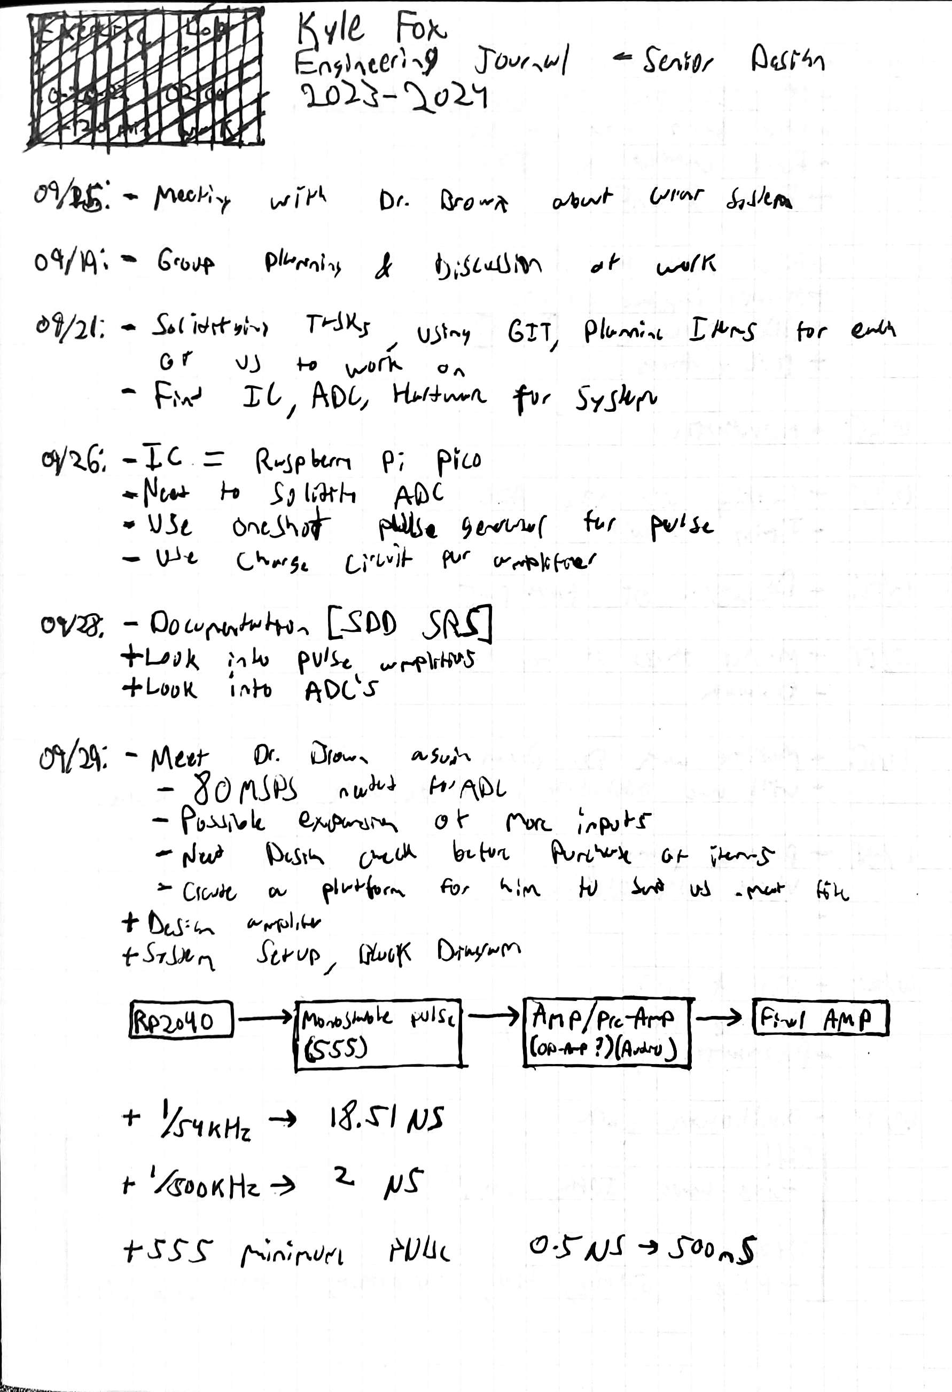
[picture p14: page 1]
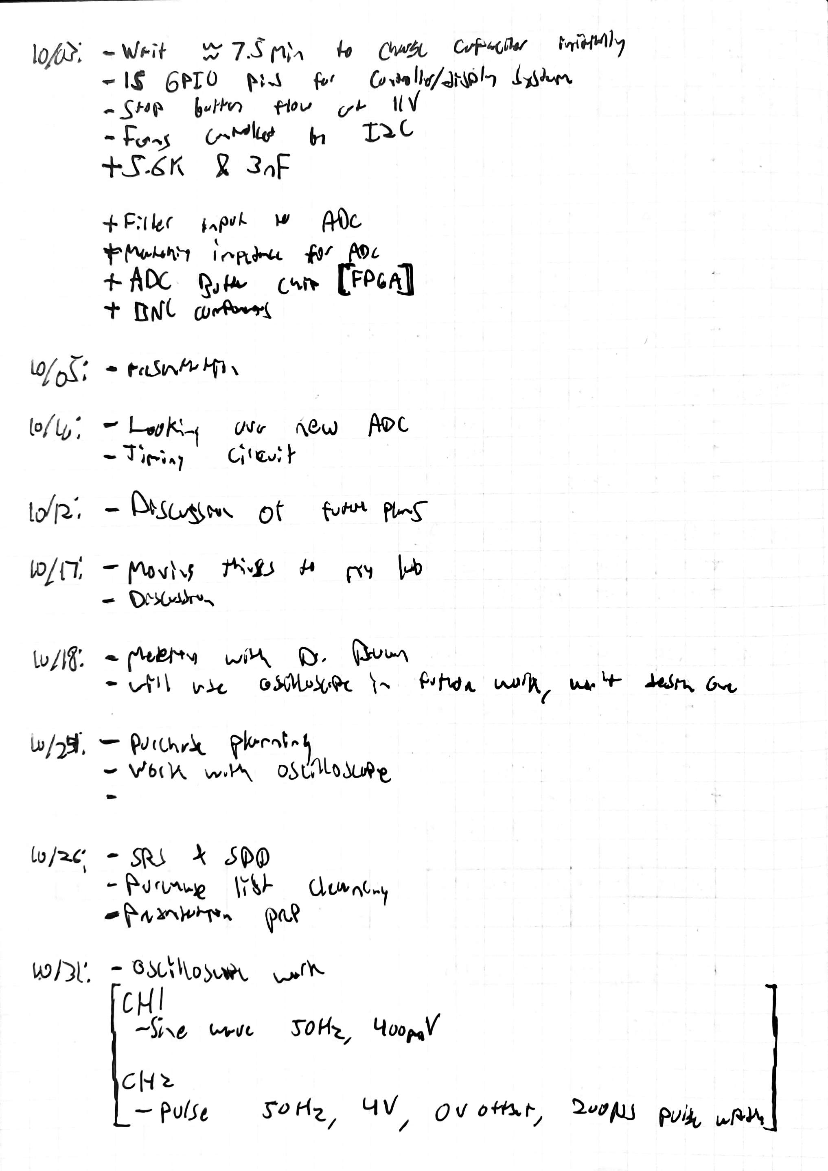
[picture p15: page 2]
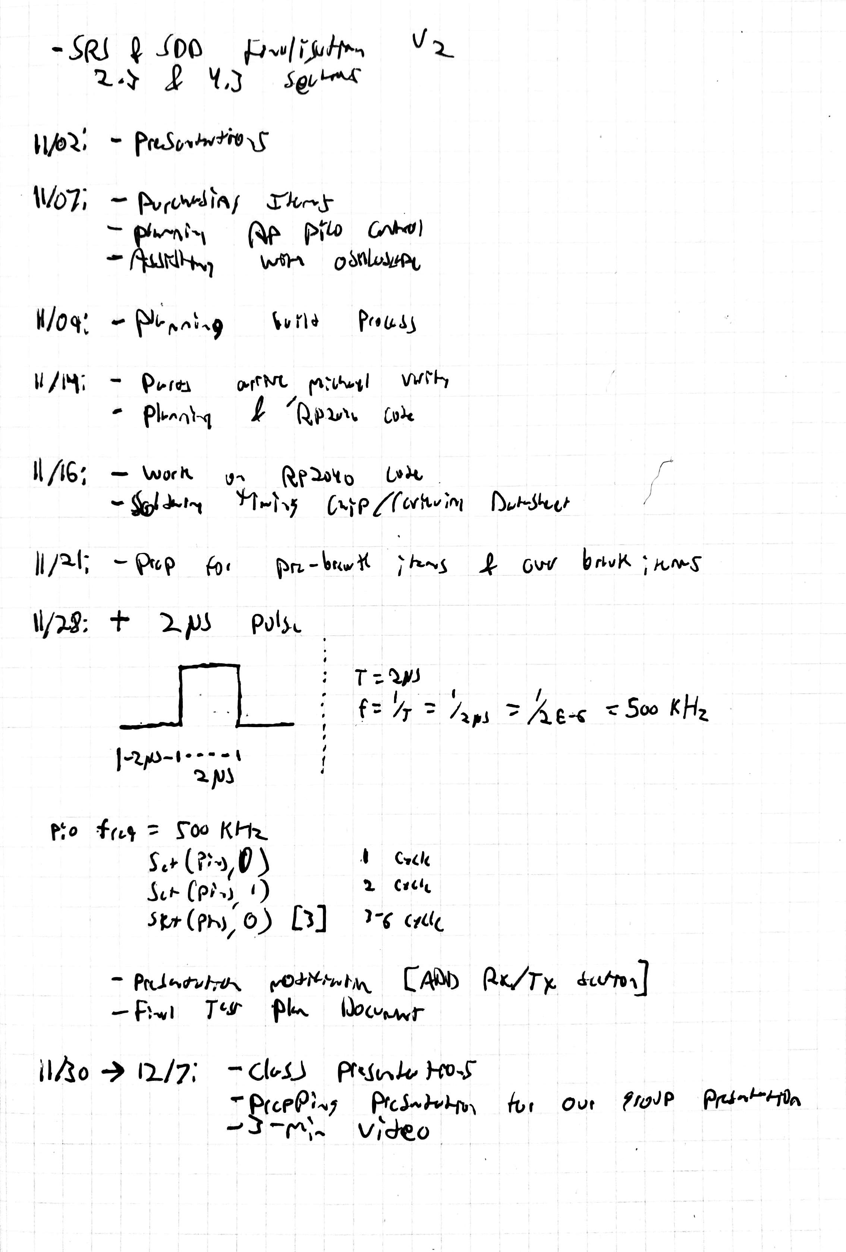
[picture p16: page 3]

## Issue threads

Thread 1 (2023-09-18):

Design an outer casing to contain the electronics and test equipment.

MichaelKi42, 2023-09-18:
•	Requirements: the case must be able to withstand a fall from 3 ft and protect the contents of the case, the case must be water resistant and be able to protect the contents from water penetration from rain, the case must have a handle and or strap for operator use, the case shall have all required penetrations for equipment to run wires and status lights (if applicable). The case shall be resistant/ shielded from outside radio interference.This also includes interior mounting of components.

Closed 2023-11-20.

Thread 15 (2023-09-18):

Design software to monitor temperature and activate the cooling system. Or shut down if the temperature exceeds 150 F (arbitrary value that may be changed)

MichaelKi42, 2023-09-18:

vtmarik, 2024-01-16:
Closing to update into new issue

Closed 2024-01-16.

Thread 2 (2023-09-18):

Design an electrical system to support the unit’s operation.

MichaelKi42, 2023-09-18:
•	Requirements: The power supply shall support equipment normal operating use for greater than or equal to 48 hours (Ideally 72hrs), the electrical system shall be reusable, the electrical system shall have wires secured to the casing or sheathed to prevent damage, the electrical system shall alert the user when power is low. Some portions of the system will operate at 500v and require verification that wire insulation is sufficient for safe operation. (The power supply may be exterior if required)

MichaelKi42, 2023-11-18:
electrical system fully designed

Closed 2023-11-18.

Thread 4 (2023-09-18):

(TX) Design a smaller equivalent to the signal generator for the transistors operating frequencies.

MichaelKi42, 2023-09-18:
•	Requirements: able to produce required frequency for transducer 500kHz, able to produce required frequency for transducer 50kHz, able to switch between the two frequencies, Able to adjust the amplitude of the signal (if required)
Transmitter output: pulse 500V, 2microseconds. (Similar system) or
Excitation: HV 1000v at 5us, LV 600v at 5us (data sheet)

FarmBoy522, 2023-11-20:
This has mostly been completed by Michael - Will verify with him after completion of component testing.

The RP2040 will be programmed to pulse at the proper width to control the overall signal generation.

Closed 2024-01-18.

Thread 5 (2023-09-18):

(RX) Design a smaller equivalent to the oscilloscope for the transistors operating frequencies.

MichaelKi42, 2023-09-18:
•	Requirements: able to receive required frequency for transducer 500kHz, able to receive required frequency for transducer 50kHz, able to switch between the two frequencies, Amplifier to boost amplitude of signal. (If required)

FarmBoy522, 2023-11-20:
Updating this issue with notes:

- An applicable chip to use would be the AnalogDevices AD9655
- Would need a chip to interface with the differential signaling to logic level
- Would be possible to make smaller by using ICs

FarmBoy522, 2023-11-20:
Closing this issue as we have decided to use a prebuilt Oscilloscope instead of designing a replacement circuit.

Closed 2023-11-20.

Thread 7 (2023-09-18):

Design the memory storage and access hardware

MichaelKi42, 2023-09-18:
•	Requirements: minimum storage of “The current data files contain 40000 double-precision numbers and are approx. 1.6 MB” sampling at 10 min interval over 72-hour period, must be computer accessible. (Estimated 691.2MB)

FarmBoy522, 2023-11-20:
This was changed to be a micocomputer running the proper software.

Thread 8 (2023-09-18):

Design an alarm/status system.

MichaelKi42, 2023-09-18:
•	Requirement: low battery/power light or alarm, self-check light or alarm, operating/on light or alarm, transmitting/testing light or alarm, memory full light or alarm, high temperature alarm light or alarm.

MichaelKi42, 2023-11-18:
alarm system designed using led's

Closed 2023-11-18.

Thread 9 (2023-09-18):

Design a cooling system for the unit in the case of an overtemperature event. (If applicable)

MichaelKi42, 2023-09-18:
•	Requirement: temperature sensor inside the unit (RTD and fan recommended) research must be done if a forced or passive cooling system shall be used

vtmarik, 2023-11-20:
System designed and mocked up. Closing as we only are awaiting the parts

Closed 2023-11-20.

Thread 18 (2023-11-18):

code for led indicating lights/alarms

MichaelKi42, 2023-11-18:
The system code to activate led for overheat, SD card full, low battery alarm.
The system code to activate led for Test ongoing alarm, 6hr, 12hr, 24hr, 48hr, 72 hr testing mode status light.

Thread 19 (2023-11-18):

connect/solder electrical system components

MichaelKi42, 2023-11-18:
Solder/connect electrical components per electrical schematic design.
Including switches, LED's, resistors, batteries, voltage converters, mosfets, fuses and fuse holders. Etc..

MichaelKi42, 2024-01-12:
Completed over the break. Any remaining work will be completed on a case by case basis

Closed 2024-01-12.

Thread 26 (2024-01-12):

Install electrical system LVS part 3 (LED)

MichaelKi42, 2024-01-12:
Low voltage system

LED (light emitting diode)

Determine location to place LED
Drill Hole to exterior of casing
Mount LED to casing
Place waterproofing sealant inside LED casing penetration

MichaelKi42, 2024-02-01:
LED mounted

Closed 2024-02-01.

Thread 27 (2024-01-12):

Install electrical system LVS part 4 (exterior operated switches)

MichaelKi42, 2024-01-12:
Low voltage system

Determine location to place exterior operated switches
Drill Hole to exterior of casing
Mount exterior operated switches to casing
Place waterproofing sealant inside exterior operated switches casing penetration

MichaelKi42, 2024-02-01:
exterior switches mounted

Closed 2024-02-01.

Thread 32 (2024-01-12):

Install electrical system HVS part 4 (exterior operated switches)

MichaelKi42, 2024-01-12:
High voltage system

Determine location to place exterior operated switches
Drill Hole to exterior of casing
Mount exterior operated switches to casing
Place waterproofing sealant inside exterior operated switches casing penetration

MichaelKi42, 2024-02-02:
switch installed

Closed 2024-02-02.

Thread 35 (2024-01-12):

Install electrical system LVS part 6 (battery)

MichaelKi42, 2024-01-12:
Low voltage system

Mount battery to casing
Mount 12v to 5v power supply to casing
Mount 12v to 19.5v power supply to casing

MichaelKi42, 2024-02-01:
battery mounted

Closed 2024-02-01.

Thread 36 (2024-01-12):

Install electrical system HVS part 7 (coaxial connection port)

MichaelKi42, 2024-01-12:
High voltage system

Determine location to place coaxial connection port
Drill Hole to exterior of casing
Mount coaxial connection port to casing
Place waterproofing sealant inside coaxial connection port casing penetration

MichaelKi42, 2024-02-01:
connection mounted

Closed 2024-02-01.

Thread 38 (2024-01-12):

Purchase Relay for HVS

MichaelKi42, 2024-01-12:
Research relays (steady state vs electromagnetically)
Purchase relay for high voltage system

MichaelKi42, 2024-02-01:
relay purchased and recieved

Closed 2024-02-01.

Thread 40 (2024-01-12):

Connect capacitor electrically HVS

MichaelKi42, 2024-01-12:
High voltage system

Mount capacitor in casing
Electrically connect capacitor

MichaelKi42, 2024-02-02:
connected electrically

Closed 2024-02-02.

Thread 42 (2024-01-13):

Mount and Install RTD

MichaelKi42, 2024-01-13:
RTD (resistance temperature detector)

Connect RTD electrically
Install wiring as required
Mount components as required.

MichaelKi42, 2024-02-02:
reassigned due to increased work scope

Closed 2024-02-02.

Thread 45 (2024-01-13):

Create cover plates (if applicable)

MichaelKi42, 2024-01-13:
Design and resin print cover plates for exterior casing

MichaelKi42, 2024-02-02:
prototype produced currently working on 3rd iteration of design

MichaelKi42, 2024-02-02:
opened as new ticket closing this redundant ticket

Closed 2024-02-02.

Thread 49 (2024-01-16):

Install cooling fans

vtmarik, 2024-01-16:
Install fans to case

vtmarik, 2024-02-29:
Progress moving smoothly, only awaiting mesh to protect wires from damage then mounting can be completed.

MichaelKi42, 2024-03-28:
Completed

Closed 2024-03-28.

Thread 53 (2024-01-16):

Create system trigger to shutdown and light "overtemp protection" LED in case of uncontrolled temp overrun

vtmarik, 2024-01-16:

MichaelKi42, 2024-02-13:
over temp LED wired and functional. Requires 3v control signal to trigger.

MichaelKi42, 2024-03-21:
temp monitor installed and will output 5v signal when temp reached

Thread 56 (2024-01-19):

Produce drip cover for exterior casing

MichaelKi42, 2024-01-19:
Design in CAD
Transfer to .stl file format/ slice
Resin print prototype
Verify
Redesign if incorrect
Mount if correct

MichaelKi42, 2024-02-02:
prototype printed. currently designing iteration 3 of the design

MichaelKi42, 2024-02-11:
prototype created but is brittle, superior version is purchased

Closed 2024-02-11.

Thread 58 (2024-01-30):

Test vent material for structural integrity with fan mount screws

vtmarik, 2024-01-30:

vtmarik, 2024-02-06:
Drilling results in fracture, pilot holes required of correct size and orientation.

MichaelKi42, 2024-02-11:
Material tested and replacement fan cover ordered

Closed 2024-02-11.

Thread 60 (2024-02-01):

Troubleshoot pin 13

MichaelKi42, 2024-02-01:
Troubleshoot why pin 13 not functional
pin 13 relay wont engage

MichaelKi42, 2024-02-11:
Troubleshooting relieved, Pin 13 is functional. Problem is pull up resistor limiting current flow.

Closed 2024-02-11.

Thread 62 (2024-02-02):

create circuit board for RTD and spare mosfets

MichaelKi42, 2024-02-02:
create circuit board for RTD and Spare mosfets

MichaelKi42, 2024-02-11:
circuit created for spare mosfet, Rtd changed to seprate chip

Closed 2024-02-11.

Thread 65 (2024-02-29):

Mount Fan Control/Voltage divider board.

vtmarik, 2024-02-29:
Mount board into case containing fan controllers and voltage divider.

MichaelKi42, 2024-03-01:
Board mounted and needs to be electrically connected.

Closed 2024-03-01.

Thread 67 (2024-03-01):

Shorten and organize wire (if time available)

MichaelKi42, 2024-03-01:

Closed 2024-03-21.

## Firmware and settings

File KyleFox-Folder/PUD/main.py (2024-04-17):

# Main file, runs whole program
# Currently used in one file to simplify cross file variables
# Plan to change in future update
# V1.0 - Full Working Version #1

import time
from machine import Pin, ADC
from debounced_input import DebouncedInput
import rp2
import setup
import programs

# PIO 50 Pulse Generator
@rp2.asm_pio(set_init=rp2.PIO.OUT_HIGH)
def pulse_management():
    # Total Loop Label
    label("total_pulse")
    
    # Cycles: 1 + 6 + 32 * (2 + 1) = 117 cycles
    # 1 set, 5 set + delay, 32 label + nop + jmp, repeat 3 times
    set(pins, 0)
    set(x, 2)                   [5]
    label("delay_high")
    nop()                       [29]
    jmp(x_dec, "delay_high")

    # Cycles: 1 + 1 + 6 + 157 * (30 + 1) = 5115 cycles
    # 1 nop, 1 set, 5 set + delay, 157 label + nop + jmp, repeat 31 times
    nop()
    set(pins, 1)
    set(x, 30)                  [5]
    label("delay_low")
    nop()                       [29]
    nop()                       [29]
    nop()                       [29]
    nop()                       [29]
    nop()                       [29]
    nop()                       [9]
    jmp(x_dec, "delay_low")
    jmp(y_dec, "total_pulse")
    
    # End by looping indefinitely
    label("noperation")
    nop()
    jmp("noperation")

def ControlStateMachine(PinArray):
    flag = 1
    global state
    
    #Input Control Pins
    strt = DebouncedInput(20, startcall, pin_pull=Pin.PULL_DOWN)
    stop = DebouncedInput(19, stopcall, pin_pull=Pin.PULL_DOWN)
    slct = DebouncedInput(18, selectcall, pin_pull=Pin.PULL_DOWN)
    
    while flag == 1:
        # STATE 0 - WAIT FOR BUTTON PRESS - This is the stop state
        if state == 0:
            print(state)
            time.sleep(2)
                    
        # STATE 1 - RUN PROGRAM
        elif state == 1:
            print(state)
            #programs.state1(timeset, piosm, PinArray)
            state = 0
            
        # STATE 2 - CHANGE TOTAL TEST TIME
        elif state == 2:
            print(state)
            #sec, currentset = programs.state2(currentset, flag)
            state = 0
            
        # ERROR STATE - SOMETHING HAS GONE WRONG AND EXIT
        else:
            print(state)
            print("Error: Wrong State")
            flag = 0
            exit
            
            
    print("Crashed - Check for Errors")
    
def startcall(pressed):
    global state
    if pressed == True:
        state = 1
        
def stopcall(pressed):
    global state
    if pressed:
        state = 0
        

def selectcall(pressed):
    global state
    if pressed:
        state = 2


def setandinit():
    #LED Pins Control 
    p0 = Pin(2, mode=Pin.OUT, pull=None, value=1)
    p1 = Pin(3, mode=Pin.OUT, pull=None, value=1)
    p2 = Pin(4, mode=Pin.OUT, pull=None, value=1)
    p3 = Pin(5, mode=Pin.OUT, pull=None, value=1)
    p4 = Pin(6, mode=Pin.OUT, pull=None, value=1)
    p5 = Pin(7, mode=Pin.OUT, pull=None, value=1)
    p6 = Pin(8, mode=Pin.OUT, pull=None, value=1)
    p7 = Pin(9, mode=Pin.OUT, pull=None, value=1)
    p8 = Pin(10, mode=Pin.OUT, pull=None, value=1)
    p9 = Pin(11, mode=Pin.OUT, pull=None, value=1)
    p10 = Pin(12, mode=Pin.OUT, pull=None, value=1)
    p11 = Pin(13, mode=Pin.OUT, pull=None, value=1)
    
    #ADC Input Pins
    voltage1 = ADC(Pin(26))
    voltage2 = ADC(Pin(27))
    
    #Array of Pin Objects
    #Array Num	0	1	2	3	4	5	6	7	8	9	10	 11		12		 13
    PinArray = [p0, p1, p2, p3, p4, p5, p6, p7, p8, p9, p10, p11, voltage1, voltage2]
    #Pin Val	2	3	4	5	6	7	8	9	10	11	12	 13		26		 27
    
    return PinArray

def state1(timeset, piosm, PinArray):
    # Create the StateMachine with the pulse_management program, outputting on Pin(14).
    sm = rp2.StateMachine(0, pulse_management, freq=500000, set_base=Pin(14))

    # Load the total pulse value into the TX FIFO then load into Y register.
    sm.put(49)					# Total pulses of 50
    sm.exec("pull()")			# Pull from TX FIFO to OSR
    sm.exec("mov(y,osr)")		# Move from OSR to Y
    
    # Device starts charging
    time.sleep(600) # Wait 10min before checking ADC
    
    # Check the ADC voltage
    if voltage1.read_u16() > 100:   # If voltage is good 
        smpulse.active(1)
        time.sleep_ms(100)
    else:
        time.sleep(60)
        fail += 1
    smpulse.active(0)
    #decriment time from total test time
    print("imagine code here")
    
def state2(currentset):
    
    # If the debug mode is set, run for 10min only
    if currentset == -1:
        print("Debug Mode")
        testcounter = 1
        currentset = -1
        return testcounter, currentset
    else:
        # If debug mode isnt selected operate as normal
        testcounter = [1, 36, 72, 144, 288, 432]		# Hour selections; 6hr / 10min = 36 instances
        currentset += 1							# Incriment the current hour select to next one
        
        return testcounter, currentset

if __name__ == '__main__':
    global state
    state = 0

    # Start the StateMachine.
    #sm.active(1)    
    
    PinArray = setandinit()
    ControlStateMachine(PinArray)

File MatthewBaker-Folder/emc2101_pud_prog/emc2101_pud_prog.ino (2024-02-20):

// Basic demo for readings from Adafruit EMC2101
#include <Adafruit_EMC2101.h>

Adafruit_EMC2101  emc2101;

void setup(void) {
  Serial.begin(115200);
  while (!Serial) delay(10);     // will pause Zero, Leonardo, etc until serial console opens

  Serial.println("Adafruit EMC2101 test!");

  // Try to initialize!
  if (!emc2101.begin()) {
    Serial.println("Failed to find EMC2101 chip");
    while (1) { delay(10); }
  }
  Serial.println("EMC2101 Found!");

  //  emc2101.setDataRate(EMC2101_RATE_1_16_HZ);
  Serial.print("Data rate set to: ");
  switch (emc2101.getDataRate()) {
    case EMC2101_RATE_1_16_HZ: Serial.println("1/16_HZ"); break;
    case EMC2101_RATE_1_8_HZ: Serial.println("1/8_HZ"); break;
    case EMC2101_RATE_1_4_HZ: Serial.println("1/4_HZ"); break;
    case EMC2101_RATE_1_2_HZ: Serial.println("1/2_HZ"); break;
    case EMC2101_RATE_1_HZ: Serial.println("1 HZ"); break;
    case EMC2101_RATE_2_HZ: Serial.println("2 HZ"); break;
    case EMC2101_RATE_4_HZ: Serial.println("4 HZ"); break;
    case EMC2101_RATE_8_HZ: Serial.println("8 HZ"); break;
    case EMC2101_RATE_16_HZ: Serial.println("16 HZ"); break;
    case EMC2101_RATE_32_HZ: Serial.println("32 HZ"); break;
  }
emc2101.enableForcedTemperature(false);
  emc2101.enableTachInput(true);
  emc2101.setPWMDivisor(0);
  emc2101.setDutyCycle(50);
   emc2101.LUTEnabled(true);
  emc2101.setLUTHysteresis(3);
  emc2101.setLUT(0, 15, 20);
  emc2101.setLUT(1, 25, 35);
  emc2101.setLUT(2, 30, 50);
  emc2101.setLUT(3, 40, 80);
  emc2101.setLUT(4, 50, 100);
 
}



void loop() {
  Serial.print("External Temperature: ");
  Serial.print(emc2101.getExternalTemperature());
  Serial.println(" degrees C");

  Serial.print("Internal Temperature: ");
  Serial.print(emc2101.getInternalTemperature());
  Serial.println(" degrees C");

  Serial.print("Duty Cycle: ");
  Serial.print(emc2101.getDutyCycle());
  Serial.print("% / Fan RPM: ");
  Serial.print(emc2101.getFanRPM());
  Serial.println(" RPM");
  Serial.println("");

  delay(100);
}

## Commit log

2023-09-21 Added data sheet for the fan
2023-09-25 adding drafted documents
    [SchematicPrototype_V2.dsn]
2023-09-26 Created Initial Part List
    For the immediate heat spreader body and fans
2023-09-28 Added excel sheet for cooling system
    Shows the curve of RPM vs Temperature
    [CoolingSystemCurve.xlsx]
2023-09-28 Adding datasheets and updates
    Updated Journal and Parts List
    Added Datasheets folder with datasheets for Fans and Fan controller
2023-10-03 Added sample data
    Also updated journal
2023-10-13 Add Altium Files
    [ControlSystem.SchDoc, SeniorDesign.PrjPcb]
2024-01-24 Updated personal folder,SDD V1
    SDD v1 begun via edits made to cooling system description
    [CoolingSystemCurve.xlsx]
2024-03-03 Finished software updated
    Will need more work in future however is closer to current and planned function of software control.
2024-03-05 Added additional code
    Was able to get hardware interrupts to act as expected
